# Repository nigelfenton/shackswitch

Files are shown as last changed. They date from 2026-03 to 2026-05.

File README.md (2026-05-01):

# G0JKN ShackSwitch

**Open source HF shack antenna switcher for amateur radio operators.**

**Builder:** Nigel Fenton, G0JKN (retired, UK)  
**Licence:** MIT  
**Current version:** v2.0 — Arduino Uno Q

---

## Photos

### Hardware

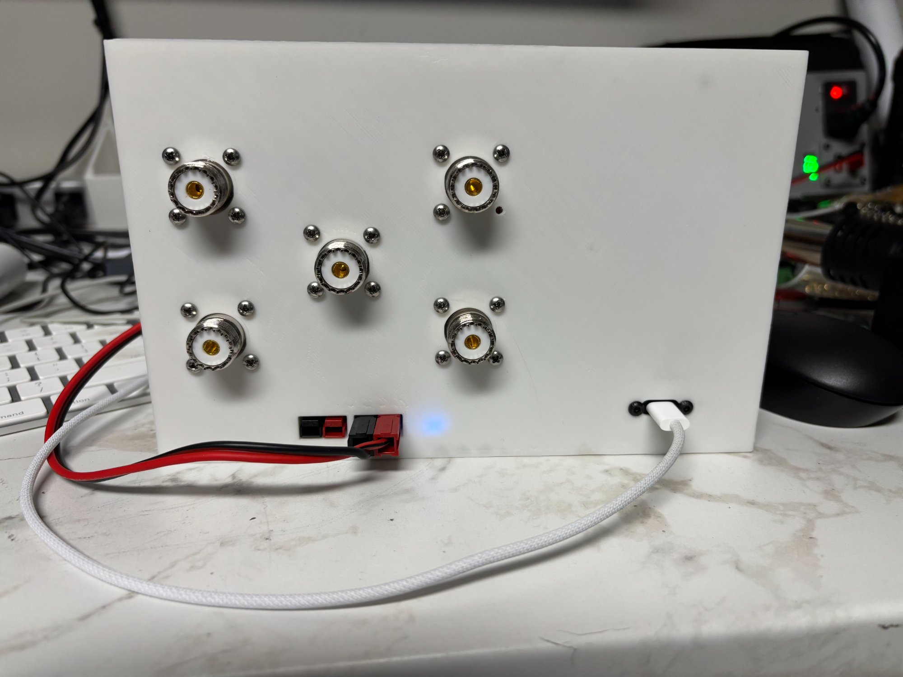
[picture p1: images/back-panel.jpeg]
ShackSwitch v2.0 — back panel


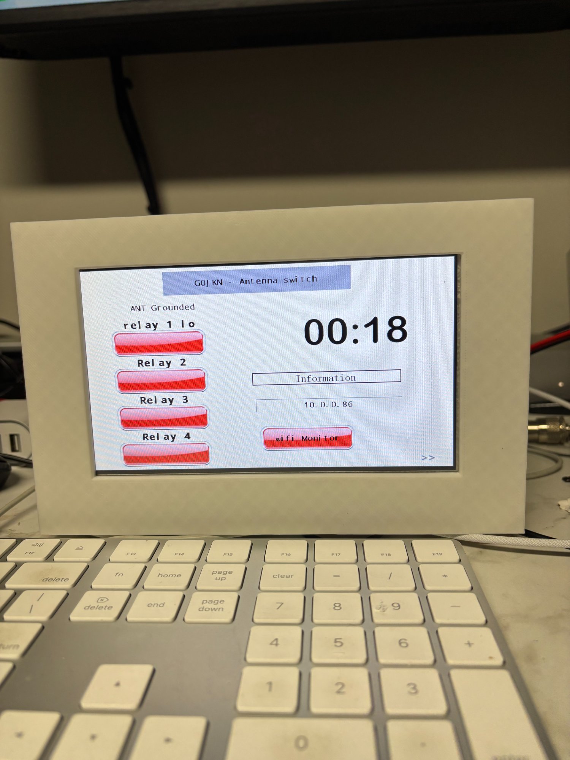
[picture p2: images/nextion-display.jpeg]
Nextion 7" display


### Web Interface

**Status page** — live frequency display per radio input, active antenna highlighted in the band grid, manual override buttons. Cyan = Input A, orange = Input B.

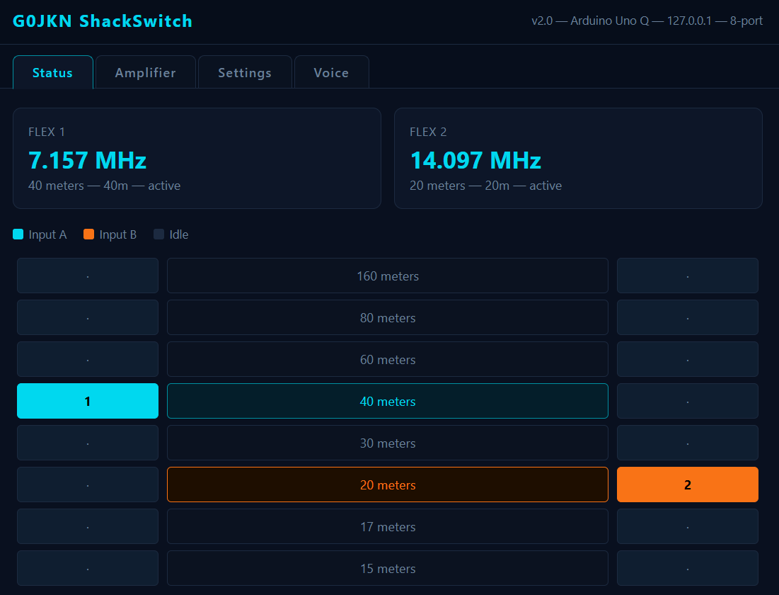
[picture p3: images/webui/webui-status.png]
Status page


**Amplifier page** — RF-Kit RF2K-S live telemetry: forward power, reflected power, SWR, temperature, supply voltage, current.

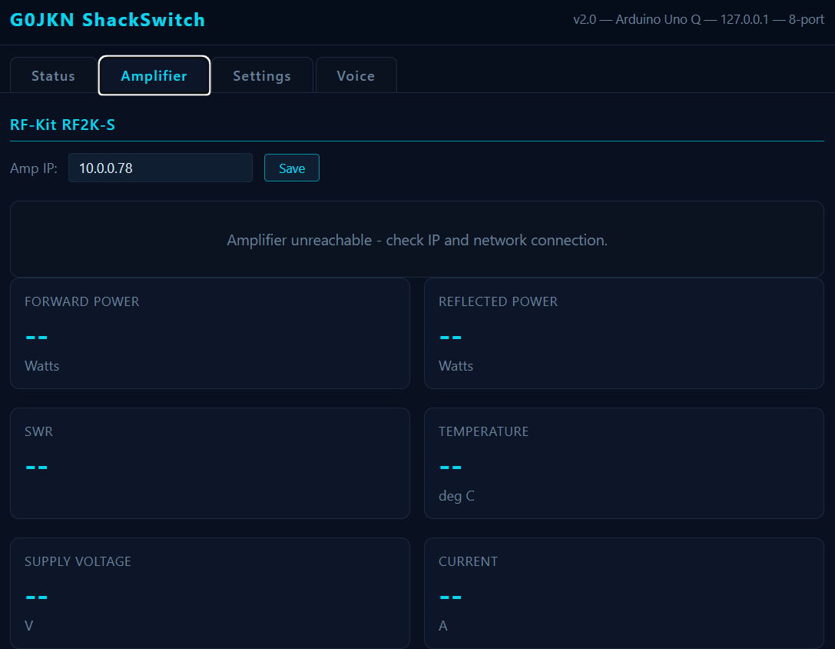
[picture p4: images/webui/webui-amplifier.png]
Amplifier page


**Settings → PORTS** — number of inputs (1 = single radio, 2 = SO2R), port count, input labels, and antenna port names. MCP23017 detection shown here with SO2R-ready status.

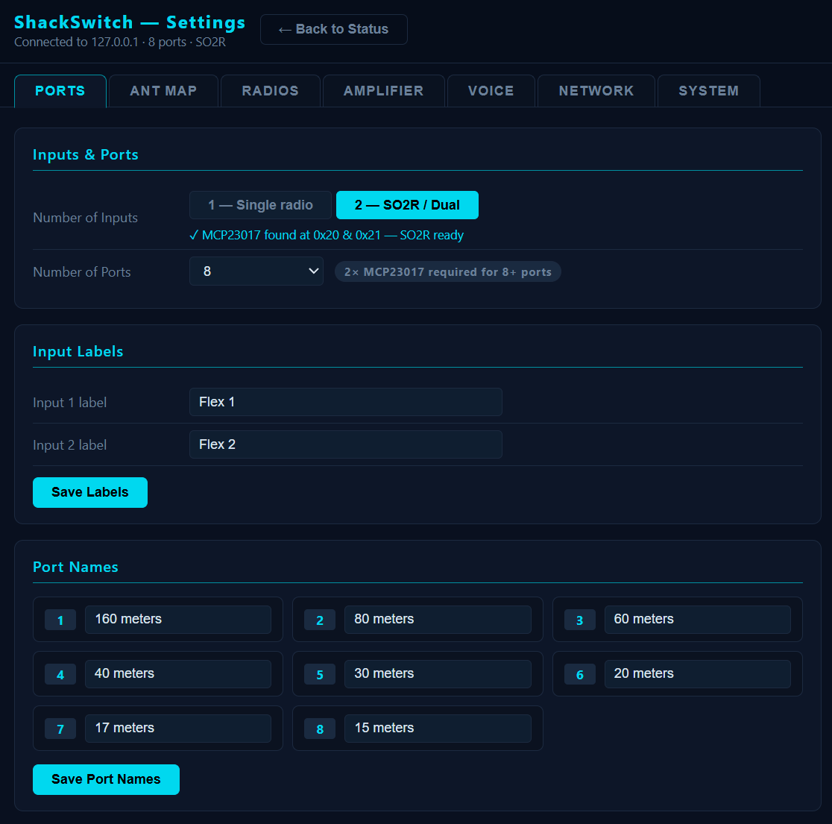
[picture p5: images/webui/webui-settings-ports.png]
Settings — PORTS


**Settings → ANT MAP** — band-to-port assignment grid. Click any cell to assign a band to a port; changes save instantly. The diagonal shows the example 8-antenna one-band-per-antenna setup.

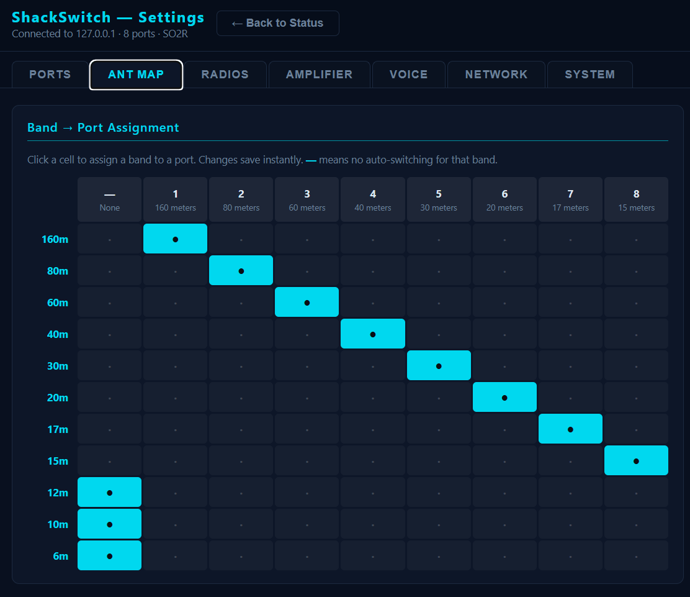
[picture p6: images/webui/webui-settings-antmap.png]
Settings — ANT MAP


**Settings → RADIOS** — CAT radio connections. Add, edit, or remove radios here. FlexRadio/SmartSDR is configured separately and always takes priority over CAT.

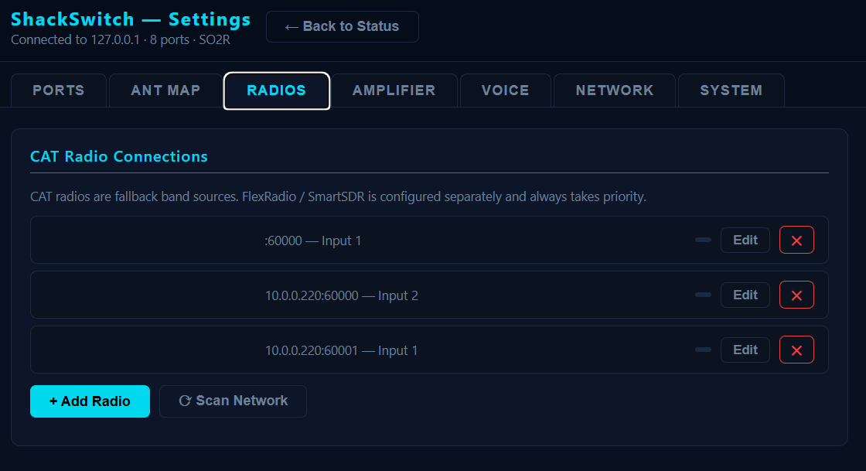
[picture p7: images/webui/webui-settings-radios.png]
Settings — RADIOS


**Settings → AMPLIFIER** — RF-Kit RF2K-S IP address and port configuration.

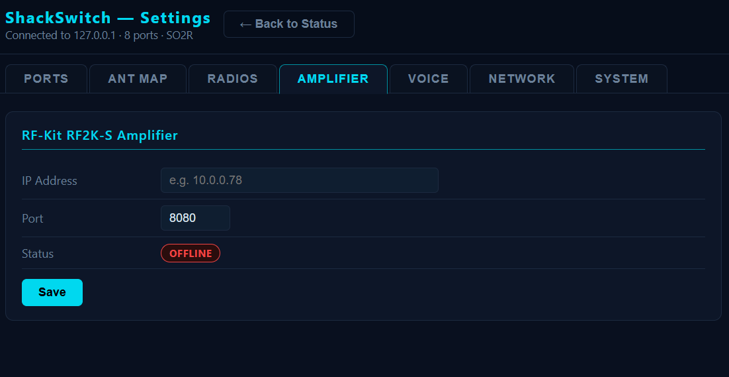
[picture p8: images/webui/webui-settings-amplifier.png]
Settings — AMPLIFIER


**Settings → VOICE** — links to ShackSpeak, the companion voice announcement app that monitors band changes and antenna selections.

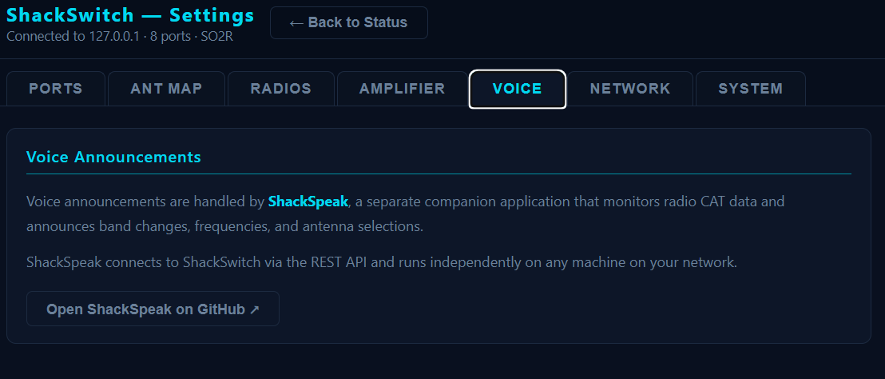
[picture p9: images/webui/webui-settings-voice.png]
Settings — VOICE


**Settings → NETWORK** — shows current WiFi connection and allows scanning for and joining a new network without SSH access.

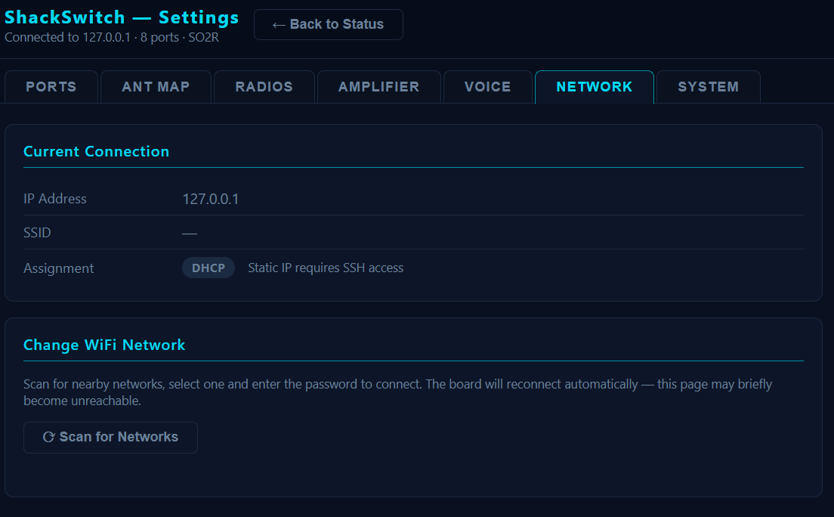
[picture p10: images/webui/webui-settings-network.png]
Settings — NETWORK


**Settings → SYSTEM** — station info (description, IARU region, ITU/CQ zone), board IP, app version and uptime, and factory reset.

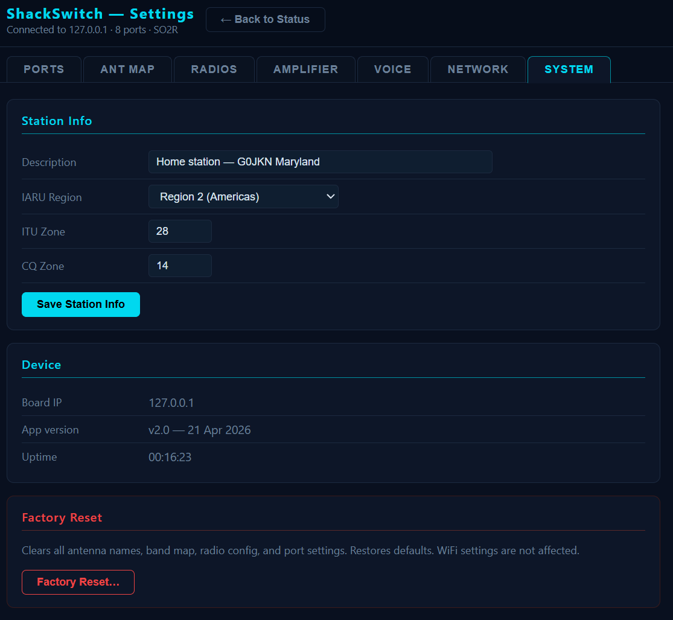
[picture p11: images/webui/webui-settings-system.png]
Settings — SYSTEM


### AetherSDR Integration

**Uno Q — dual input (SO2R), INPUT A on 20m, INPUT B on 80m:**

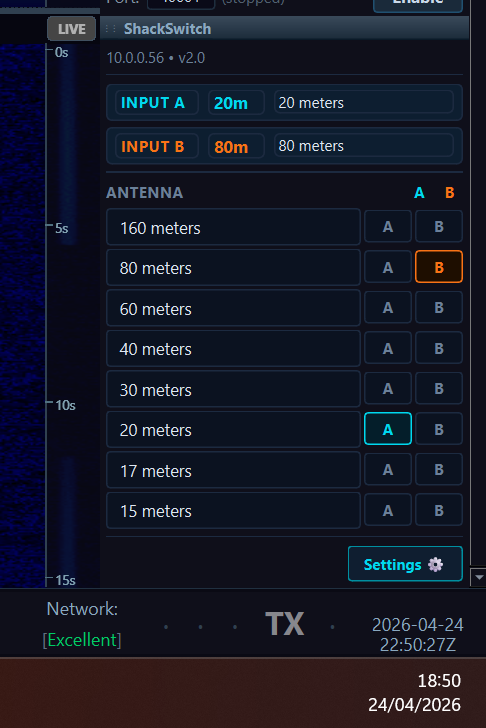
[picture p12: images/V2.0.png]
AetherSDR ShackSwitch applet — Uno Q dual input


**R4 — single input, INPUT A on 40m:**

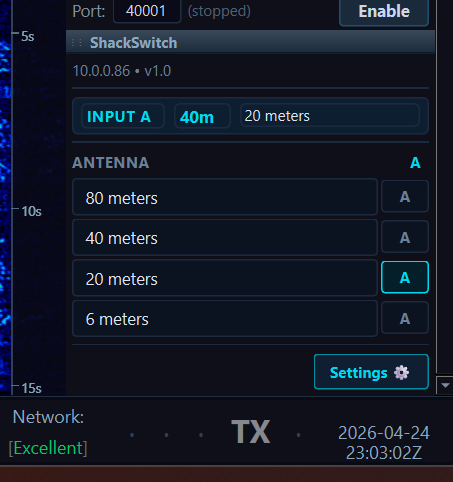
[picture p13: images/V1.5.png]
AetherSDR ShackSwitch applet — R4 single input


---

## What is ShackSwitch?

ShackSwitch sits between your radios and your antennas. It automatically selects the correct antenna when you change band, supports two radio inputs (SO2R capable) with hardware interlock protection, and can be controlled from any browser on your network.

It integrates with FlexRadio SmartSDR, Kenwood, Icom, and Yaesu radios — tracking band changes in real time and switching antennas automatically, with no manual intervention required.

---

## Platform — v2.0

ShackSwitch v2.0 runs on the **Arduino Uno Q** — a single board that combines a Qualcomm QRB2210 quad-core Linux processor with an STM32U585 real-time microcontroller.

- **Linux side** — Python Flask REST API, SmartSDR band tracker, radio CAT orchestrator, 4O3A Antenna Genius emulator. Runs as a Docker container, auto-started on boot.
- **STM32 side** — relay driver firmware. Loaded into RAM via OpenOCD at boot by `shackswitch-boot.sh`. Communicates with the Linux side via the Arduino Bridge RPC.
- **Web UI** — accessible from any browser on the network at `http://[board-ip]:5000/`

No separate Raspberry Pi or Arduino R4 is required.

---

## Features

### Antenna Switching
- Automatic antenna switching triggered by band changes from connected radios
- 2–16 configurable antenna ports (defaults to 8)
- Two radio input ports (SO2R) with hardware interlock — prevents both inputs selecting the same antenna simultaneously
- KK1L 2x6 relay board support via MCP23017 I2C GPIO expander (built and tested)
- G0JKN custom relay shield support (NPN/PNP driver, 12V coils)
- Band-to-antenna assignment grid — configurable per antenna per band

### Radio Interfaces
ShackSwitch tracks band changes from any combination of the following:

| Protocol | Supported Models |
|---|---|
| **FlexRadio SmartSDR** | FlexRadio 6000/7000 series via TCP port 4992 |
| **Kenwood CAT** | TS-450SAT, TS-480HX, TS-590, TS-890S, Elecraft K3/K4 |
| **Yaesu CAT** | FT-845, FT-891, FT-991A, FT-DX10, FT-817/818 |
| **Icom CI-V** | IC-9700, IC-7300, IC-705, IC-7610 |

Each radio runs in its own background thread with automatic reconnection. Serial and network transports are both supported.

### Web UI
- Live antenna selection display with manual switching
- Live frequency display per radio input
- SO2R interlock status
- Settings grid — port count, input labels, antenna names, band assignments
- Profile-based configuration — save and switch between different station setups
- Voice control — Web Speech API for TTS readback and voice commands

### Integration
- **4O3A Antenna Genius emulator** — ShackSwitch advertises itself as an Antenna Genius device over UDP/TCP (port 9007), making it discoverable and controllable by AetherSDR and other compatible software
- **REST API** — full HTTP endpoint set for external control and integration
- **Profile system** — multiple named configurations, switchable at runtime

---

## Hardware

| Item | Detail |
|---|---|
| Main board | Arduino Uno Q (Qualcomm QRB2210 Linux + STM32U585) |
| Relay shield | G0JKN custom shield — NPN/PNP drivers, 12V relay coils |
| Relay expander | KK1L 2x6 relay board with MCP23017 I2C GPIO expanders |
| RF connectors | SO239 — 1–2 radio inputs, up to 16 antenna outputs |
| Radio | FlexRadio 6700 (primary), Kenwood/Yaesu/Icom via CAT |
| Power | 12V DC |

---

## Wiring

### Nextion Display

Connect the Nextion to the Arduino Uno Q header pins as follows:

| Nextion pin | Uno Q pin |
|---|---|
| GND | GND |
| +5V | 5V |
| TX | **D0** (RX) |
| RX | **D1** (TX) |

> ⚠️ **Critical — use D0/D1, not D2/D3.**
> The Uno Q Zephyr OS maps serial ports as follows:
> - `Serial` → internal SoC↔STM32 link (`ttyHS1`) — **never use this for peripherals**
> - `Serial1` → D0/D1 header pins → **this is the Nextion connection**
>
> If you connect to D2/D3 the display will receive nothing. All sketch Nextion functions (`nextion_cmd`, `nextion_poll_serial`, etc.) call `Serial1`, which physically drives D0/D1.

📷 *Photo: close-up of D0/D1 jumper wires on the Uno Q header, with labels*

### MCP23017 I2C (KK1L Relay Board)

| MCP23017 pin | Uno Q pin |
|---|---|
| SDA | SDA (A4) |
| SCL | SCL (A5) |
| VCC | 3.3V (check board spec) |
| GND | GND |
| A0, A1, A2 | GND (I2C address 0x20) |

> If you have address conflicts on the I2C bus, tie A0/A1/A2 to different combinations of GND/VCC to select addresses 0x20–0x27.

📷 *Photo: MCP23017 / KK1L board wired to Uno Q SDA/SCL*

### USB-C Port Gotcha

The Uno Q has two USB-C ports. One is programming/console only; the other is the host USB port used for serial radio adapters. **If USB serial devices don't appear as `/dev/ttyUSB*`, try flipping the USB-C cable** — the host port is orientation-sensitive.

---

## How It Works

```
FlexRadio / Kenwood / Yaesu / Icom
         │ CAT / SmartSDR TCP
         ▼
┌─────────────────────────────────────────┐
│  Arduino Uno Q — Linux side             │
│                                         │
│  radios.py  ──► band change event       │
│                      │                  │
│  main.py (Flask) ◄───┘                  │
│  - REST API :5000                       │
│  - AG emulator :9007                    │
│  - Web UI                               │
│          │ Bridge RPC                   │
└──────────┼──────────────────────────────┘
           │
┌──────────▼──────────────────────────────┐
│  STM32U585 — real-time side             │
│  sketch.ino                             │
│  - Relay driver (direct GPIO)           │
│  - MCP23017 I2C (KK1L board)           │
│  - DIP switch config                    │
└─────────────────────────────────────────┘
           │
    Relay outputs ──► Antennas 1–16
```

### Boot Sequence

On power-up, `shackswitch-boot.sh` (run by systemd):
1. Restarts the `arduino-router` service and waits for its socket
2. Uses OpenOCD to load `sketch.ino.bin` into STM32 RAM
3. Waits for Bridge registration
4. Starts the ShackSwitch Docker container

### SO2R Interlock

When two radios are active:
- If both attempt to use the same antenna — Input B is inhibited
- If both are on the same band — Input B is inhibited
- Interlock state is shown live in the web UI and pushed to connected AetherSDR clients

---

## REST API

| Endpoint | Description |
|---|---|
| `GET /status` | Full status — relay states, bands, SO2R, interlock |
| `GET /radios/status` | CAT radio connection states and current bands |
| `GET /select?input=[a\|b]&port=[n]` | Select antenna port for input A or B |
| `GET /setband?input=[1\|2]&band=[name]` | Set band for input (e.g. `40m`) |
| `GET /bandmap` | Get band-to-antenna assignment map |
| `GET /assign` | Set band-to-antenna assignment |
| `GET /rename` | Rename an antenna port |
| `GET /rename_bulk` | Rename multiple ports in one call |
| `GET /profile` | Get current profile |
| `POST /profile` | Switch or save a profile |
| `GET /config/ports` | Get port count configuration |
| `POST /config/ports` | Set port count (2–16) |
| `GET /factory_reset` | Reset configuration to defaults |
| `GET /kk1l/status` | KK1L relay board status |
| `GET /kk1l/setband` | Drive KK1L board for a band change |

---

## 4O3A Antenna Genius Emulation

ShackSwitch emulates a 4O3A Antenna Genius device so that AetherSDR can discover and connect to it as a peripheral.

- **UDP discovery** — broadcasts on port 9007 every 5 seconds
- **TCP protocol** — implements `antenna list`, `band list`, `port get`, `sub port all`, `sub relay`, and `ping` commands
- Antenna count and band masks are derived from the active profile

See [shackswitch-v2/AETHERSDR-PROTOCOL.md](shackswitch-v2/AETHERSDR-PROTOCOL.md) for full protocol documentation.

> **Status (April 2026):** Full two-way integration is working — ShackSwitch is auto-discovered by AetherSDR, displays as a dedicated ShackSwitch applet showing live band and antenna selection for both inputs (R4: single input; Uno Q: dual input SO2R). Pull request [#2214](https://github.com/ten9876/AetherSDR/pull/2214) is open against the upstream AetherSDR repository; all CI checks passing.

---

## Radio CAT Configuration

Radios are configured in `config.json` under the `radios` key. Each radio entry specifies protocol, transport, and which ShackSwitch input it maps to.

```json
{
  "radios": {
    "a": {
      "label":     "IC-7300",
      "enabled":   true,
      "protocol":  "icom",
      "transport": "serial",
      "device":    "/dev/ttyUSB0",
      "baud":      9600,
      "civ_address": "0x94",
      "input":     "1"
    },
    "b": {
      "label":     "TS-890S",
      "enabled":   true,
      "protocol":  "kenwood",
      "transport": "network",
      "host":      "192.168.1.50",
      "port":      60000,
      "input":     "2"
    }
  }
}
```

FlexRadio SmartSDR is configured separately — `smartsdr.py` connects to the radio's TCP port 4992 and calls `/setband` on band changes.

---

## Repository Structure

```
shackswitch/
├── shackswitch-v2/          — current v2.0 source
│   ├── main.py              — Flask REST API, AG emulator, profile/config management
│   ├── radios.py            — multi-protocol radio CAT orchestrator
│   ├── radio_kenwood.py     — Kenwood CAT driver
│   ├── radio_yaesu.py       — Yaesu CAT driver
│   ├── radio_icom.py        — Icom CI-V driver
│   ├── radio_driver.py      — shared transport and band utilities
│   ├── smartsdr.py          — FlexRadio SmartSDR band tracker
│   ├── kenwood.py           — legacy standalone Kenwood interface (superseded by radios.py)
│   ├── sketch.ino           — STM32U585 relay firmware
│   ├── deploy.sh            — one-command deployment to any Uno Q board
│   ├── templates/           — Flask HTML templates (web UI pages)
│   ├── migrate_config.py    — config format upgrade tool
│   └── AETHERSDR-PROTOCOL.md — 4O3A Antenna Genius protocol documentation
├── services/
│   ├── shackswitch-boot.sh  — boot script: OpenOCD STM32 load + Docker start
│   └── shackswitch.service  — systemd service file
├── firmware/                — legacy Arduino R4 firmware (v1.5, historical)
├── nodered/                 — legacy Node-RED/Pi files (historical)
├── nextion/                 — legacy Nextion HMI files (historical)
└── docs/                    — legacy v1.5 README and project notes
```

---

## Version History

| Version | Platform | Key Changes |
|---|---|---|
| **2.0** | **Arduino Uno Q** | Complete rewrite — Flask REST API on Linux, STM32 relay firmware, Docker container, Bridge RPC, multi-protocol radio CAT (Kenwood/Yaesu/Icom/FlexRadio), KK1L board support, profile system, voice control, 4O3A AG emulation, 2–16 configurable ports |
| 1.5 | Arduino R4 WiFi + Raspberry Pi | TCP control protocol, UDP discovery, FlexRadio band tracking, SO2R interlock, Nextion band display |
| 1.4 | Arduino R4 WiFi | Antenna name labels, live JSON web updates |
| 1.3 | Arduino R4 WiFi | Dual-state image buttons on Nextion |
| 1.2 | Arduino R4 WiFi | NTP time sync, station monitor page, factory reset |
| 1.1 | Arduino R4 WiFi | WiFi web server, web-based antenna control, EEPROM name storage |
| 1.0 | Arduino R4 WiFi | Initial release — 4 relay antenna switching, Nextion display |

---

## Deploying to a New Board

A deploy script is included to get ShackSwitch running on a fresh Arduino Uno Q in one command.

### How the Board Becomes Reachable

The Arduino Uno Q runs Linux. Flask and the Docker container start automatically on every power-up — no USB connection is needed for the app to run.

What changes with USB is **network access**:

| State | What's running | Can you reach it? |
|---|---|---|
| Power only, no WiFi | Flask running on port 5000 | ❌ No — board has no network IP |
| Power + WiFi connected | Flask running on port 5000 | ✅ Yes — `http://[wifi-ip]:5000` from any device on your network |
| Power + USB (App Lab) | Flask running on port 5000 | ✅ Yes — USB network link gives the board a local IP even without WiFi |

When you plug in USB and launch App Lab, the Uno Q presents a **USB network interface** on your computer (Windows shows it as an RNDIS/USB Ethernet adapter). The board gets a USB link-local IP address — App Lab's web interface uses this to let you reach the board. The ShackSwitch web UI at port 5000 is accessible over that same USB link.

**This is the first-time WiFi setup path:**
1. Power up the board (no WiFi yet)
2. Plug in USB → launch App Lab on your computer
3. App Lab connects — board is now reachable over the USB network
4. Open `http://[usb-ip]:5000` in your browser (check App Lab for the board's USB IP address)
5. Go to **Settings → NETWORK** → scan for networks → select your SSID and enter the password → Connect
6. Board joins your WiFi and gets a permanent IP (shown on screen / in App Lab)
7. Unplug USB — from now on use `http://[wifi-ip]:5000` directly

> **Note:** `127.0.0.1` (localhost) refers to *your own computer*, not the board. You cannot use `http://127.0.0.1:5000` in a browser on your PC to reach the board — you need either the WiFi IP or the USB network IP.

---

### Prerequisites

- Arduino Uno Q plugged in via USB-C to your computer
- **App Lab first-run wizard** completed — connect the board to your WiFi network. App Lab displays the board's IP address at the end of setup. Note it down — that's what you pass to the deploy script. It also creates `user:first-app` which ShackSwitch deploys into.
- SSH key set up for the board (see Arduino Uno Q docs)
- This repo cloned to your machine

### Deploy

```bash
cd shackswitch-v2
./deploy.sh 10.0.0.XX    # use the IP shown by App Lab during setup
```

The script will:
1. Copy all Python files and templates to the board
2. Ensure `app.yaml` exposes both ports — **5000** (web UI) and **9007** (AG emulator)
3. Restart the app — flashes the STM32 sketch and starts the Python container

If your SSH key is not at one of the standard locations (`~/.ssh/id_ed25519`, `~/.ssh/id_rsa` etc.) you can override it:

```bash
SSH_KEY=~/.ssh/my_custom_key ./deploy.sh 10.0.0.XX
```

### After Deployment

1. Open `http://10.0.0.XX:5000` in a browser
2. Go to **Settings → PORTS** — name your antenna ports
3. Go to **Settings → ANT MAP** — assign bands to ports (click the grid cell to assign, saves instantly)
4. In **AetherSDR → Radio Setup → Peripherals**, set the ShackSwitch IP to your board IP

> **Note:** Each board starts with a fresh default config — antenna names and band assignments are set up via the web UI after deployment. WiFi and network settings are handled by the Uno Q OS, not ShackSwitch.

---

## udev Rules

To give serial radio adapters persistent device names on the Uno Q, create `/etc/udev/rules.d/99-shackswitch.rules`:

```
# Icom CI-V — Prolific USB-serial adapter
SUBSYSTEM=="tty", ATTRS{idVendor}=="067b", ATTRS{idProduct}=="2303", SYMLINK+="ttyICOM"

# Kenwood / Yaesu — FTDI USB-serial adapter
SUBSYSTEM=="tty", ATTRS{idVendor}=="0403", ATTRS{idProduct}=="6001", SYMLINK+="ttyKENWOOD"
```

Apply without rebooting:
```bash
sudo udevadm control --reload-rules && sudo udevadm trigger
```

Use the symlink in `config.json` (e.g. `"device": "/dev/ttyICOM"`) so the path survives USB re-plug events.

To find vendor/product IDs for an unknown adapter: `lsusb` or `udevadm info -a -n /dev/ttyUSB0 | grep -E "idVendor|idProduct"`.

---

## Key Configuration Settings

The main config file lives at `~first-app/app/config.json` on the board (or `/app/config.json` inside the running Docker container).

| Key | Default | Description |
|---|---|---|
| `ports` | `8` | Number of antenna ports (2–16) |
| `inputs` | `2` | Radio inputs — `1` = single, `2` = SO2R |
| `station.serial` | `"G0JKN-001"` | Station identifier used in AG beacon |
| `station.name` | `"ShackSwitch"` | Display name shown in AetherSDR |
| `smartsdr.host` | `""` | FlexRadio IP address (empty = disabled) |
| `smartsdr.port` | `4992` | SmartSDR TCP port |
| `kk1l.enabled` | `false` | Enable KK1L relay board via MCP23017 |
| `kk1l.i2c_address` | `"0x20"` | MCP23017 I2C address |
| `rf2ks.host` | `""` | RF2K-S amplifier IP (empty = disabled) |

> **AetherSDR identification:** `station.serial` must start with `G0JKN` **or** `station.name` must contain `ShackSwitch` (case-insensitive) for AetherSDR to show the dedicated ShackSwitch applet instead of a generic Antenna Genius panel.

📷 *Screenshot: Settings → SYSTEM page showing station serial and name fields*

---

## Nextion Display — Page Map

Navigation is driven entirely by Python (`nextion.py`). The HMI Touch Release events send `printh 23 02 54 NN` byte sequences (where `NN` is the button code); Python reads those events and issues numeric `page N` commands back to the display.

| Page | Name | Content |
|---|---|---|
| 0 | Splash | ShackSwitch logo, firmware version, **SKIP** button |
| 1 | Single (Main) | Input A band, active antenna, NEXT / PREV |
| 2 | SO2R | Input A and B side-by-side, antenna, interlock state |
| 3 | RSSI | Signal level bars (future) |
| 8 | WiFi | SSID, IP address, signal strength, **BACK** |

### Navigation flow

```
[Boot] → page 0 (splash, 20s auto-advance) → page 1
page 1 → NEXT → page 2 → NEXT → page 3 → NEXT → page 8
page 8 → BACK → page 0 (splash)
```

> **Serial port note:** The Nextion must be connected to D0/D1 (`Serial1` in the sketch). `Serial` is the internal SoC↔STM32 link and cannot be used for the display.

📷 *Photo: Nextion 7" display showing the SO2R page 2 with both inputs active*

---

## Troubleshooting

| Symptom | Likely Cause | Fix |
|---|---|---|
| Nextion stays on splash page | Wrong serial port in sketch | Confirm sketch uses `Serial1.begin(9600)` (D0/D1), not `Serial.begin()` |
| Display shows garbage | Baud mismatch | Both sketch and Nextion HMI must be set to 9600 baud |
| No relay clicks | STM32 sketch not loaded | Check boot script ran: `journalctl -u shackswitch.service` |
| Web UI not reachable at `:5000` | Container not running | `ssh first-app@[ip]` → `docker ps` |
| AetherSDR can't discover ShackSwitch | AG beacon not running | `ss -ulnp \| grep 9007` inside container — check port 9007 UDP |
| AetherSDR shows "Antenna Genius" label | Station name/serial mismatch | Ensure `station.serial` starts with `G0JKN` or `station.name` contains `ShackSwitch` |
| Serial radio not found (`/dev/ttyUSB*` missing) | USB-C orientation | Flip USB-C cable on Uno Q host USB port |
| Band changes not tracked | CAT radio disconnected | Check Settings → RADIOS; verify IP/port/device path; check radio is powered |
| SO2R interlock triggered unexpectedly | Both inputs on same band | This is correct behaviour — interlock clears when bands differ |
| Relay state lost on restart | Known issue — state not persisted | Roadmap item; workaround: re-select band from web UI after restart |

---

## Key File Locations (on the Board)

| File | Path on board | Purpose |
|---|---|---|
| Main config | `~first-app/app/config.json` | All station settings — ports, radios, profiles |
| Boot script | `/usr/local/bin/shackswitch-boot.sh` | Loads STM32 firmware, starts Docker container |
| systemd service | `/etc/systemd/system/shackswitch.service` | Runs boot script on power-up |
| STM32 firmware | `~first-app/app/sketch.ino.bin` | Relay driver binary, loaded into STM32 RAM by OpenOCD |
| Python app | `~first-app/app/*.py` | Flask REST API, radio drivers, AG emulator |
| Nextion module | `~first-app/app/nextion.py` | Nextion display driver and page navigation |
| Templates | `~first-app/app/templates/` | Web UI HTML pages |

📷 *Screenshot: SSH terminal showing `docker ps` output with the shackswitch container running*

---

## Licence

Released under the **MIT Licence**. Free to use, modify and distribute for personal or commercial purposes. Attribution to G0JKN appreciated but not required.

---

## About

Built by **G0JKN/W3** — a retired amateur radio operator keeping the mind sharp one solder joint at a time.

Feedback, suggestions and pull requests welcome.

*73 de G0JKN*

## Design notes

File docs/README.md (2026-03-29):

# G0JKN ShackSwitch
### Open Source Shack Controller for HF Stations





---

## Photos

Nextion Touchscreen Display
*Front panel — Nextion 3.5" touchscreen showing antenna ports, band display, SO2R status, NTP clock and IP address. 3D printed enclosure designed in Fusion 360.*

Back Panel
*Rear panel — five SO239 connectors (one radio input, four antenna outputs), 12V DC power connector with XT60, and USB port for programming. Blue power LED visible.*

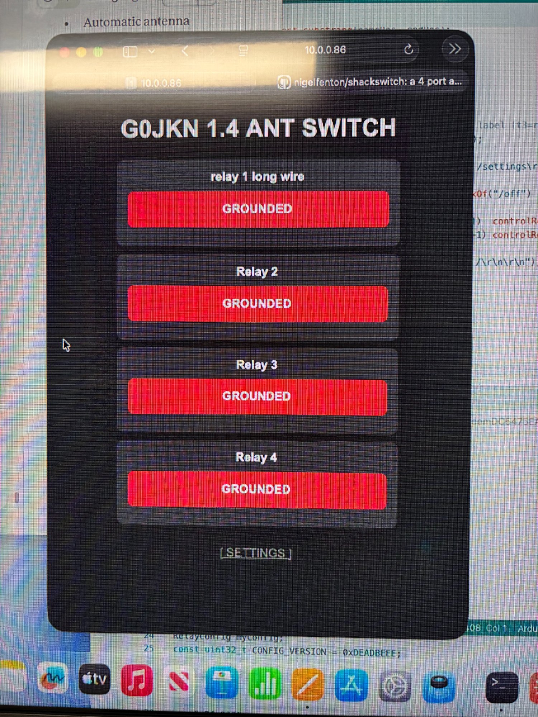
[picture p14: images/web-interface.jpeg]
Web Interface

*Web interface — four antenna ports with live band and SO2R status panel. Updates automatically every 5 seconds.*

---

## What Is This?

The G0JKN ShackSwitch is an open source shack controller designed and built by **G0JKN** as a hobby project. It started life as a simple 4-port antenna switcher and has grown into a full station management system covering antenna switching, SO2R interlock, automatic band tracking via FlexRadio SmartSDR, and network integration via a TCP control protocol and REST API.

If you are new to Arduino or amateur radio electronics, don't worry — this guide explains everything step by step. If you are an experienced builder, feel free to skip ahead to the sections most relevant to you.

---

## Features

- **4-port antenna switching** — select between up to 4 antennas with a single button press
- **Touchscreen control** — Nextion colour display with dual-state image buttons
- **Web interface** — control and monitor the switcher from any browser on your network, including mobile devices
- **Live web updates** — relay state, band display and SO2R status all update automatically every 5 seconds
- **Band display** — tBandA and tBandB show current band for Input 1 and Input 2 on the Nextion and web page
- **SO2R interlock** — inhibits second input if both are transmitting on the same band or same antenna
- **FlexRadio band tracking** — automatic antenna switching driven by SmartSDR frequency data via Raspberry Pi Python service
- **TCP control protocol** — port 9008, compatible with AetherSDR and Node-RED integration
- **UDP discovery beacon** — auto-discovery by network clients every 5 seconds
- **REST API** — full HTTP endpoint set including /setband for band updates
- **Antenna labels** — each port displays its assigned antenna name on the touchscreen and web page
- **WiFi connected** — built-in web server, NTP time sync, and network integration
- **LED Matrix display** — shows active relay or grounded state on the Arduino's onboard matrix
- **EEPROM storage** — antenna names and WiFi credentials survive power cycles
- **Factory reset** — double-tap safety reset accessible from the touchscreen

### Planned / Coming Soon
- KK1L 2x6 relay board expansion — upgrades to 2-input, 6-output matrix via MCP23017 I2C expanders
- Additional shack switching relays (amps, lights, PSU remote) via MCP23017
- BCD band decoder input and output
- PA protection / sequencer integration
- AetherSDR native integration panel (issue #179)

---

## Hardware Required

### Core Components

| Component | Details |
|---|---|
| Arduino Uno R4 WiFi | The brains of the system — includes onboard WiFi and LED matrix |
| Nextion NX4832T035 | 3.5 inch colour touchscreen display (or similar Nextion model) |
| 4x relay module | Single pole, for antenna switching (one relay per antenna port) |
| Custom Arduino shield | PCB or veroboard shield carrying relays, transistor drivers and connectors |
| 12V DC power supply | Powers relay coils via the shield |
| Buck converter | Steps 12V down to 5V for the Arduino and shield logic |
| Raspberry Pi (any model) | Required for SmartSDR band tracking (runs smartsdr.py service) |

### RF Connectors
- 1x SO239 input (from radio)
- 4x SO239 outputs (to antennas)

---

## How It Works

### The Basic Idea

The ShackSwitch sits between your radio and your antennas. Your radio connects to the single RF input, and each of your antennas connects to one of the four RF output ports. Pressing a button on the touchscreen (or clicking in the web interface) activates the corresponding relay, connecting that antenna to the radio and grounding all others.

```
Radio TX/RX
    │
    │  SO239 in
    ▼
┌─────────────────────┐
│  G0JKN ShackSwitch  │──── Relay 1 ──► SO239 ──► Antenna 1
│                     │──── Relay 2 ──► SO239 ──► Antenna 2
│  Arduino R4 WiFi    │──── Relay 3 ──► SO239 ──► Antenna 3
│  Nextion 3.5"       │──── Relay 4 ──► SO239 ──► Antenna 4
└─────────────────────┘
    │              ▲
    │  WiFi        │ HTTP /setband
    ▼              │
Web Browser    Raspberry Pi
               smartsdr.py
                   ▲
                   │ TCP port 4992
                   │
              FlexRadio SmartSDR
```

### Two Input Ports

The ShackSwitch is architecturally a two-input device, reflecting the KK1L 2x6 expansion board and the FlexRadio dual-slice model:

- **Input 1** = FlexRadio Slice A (TX capable)
- **Input 2** = FlexRadio Slice B

In a two-radio setup, Input 1 and Input 2 map to Radio A and Radio B respectively. The firmware tracks band and TX state for each input independently.

### Automatic Band Tracking

A Python service (`smartsdr.py`) runs on a Raspberry Pi on the same network. It connects to SmartSDR on TCP port 4992, subscribes to slice frequency events, and calls the ShackSwitch `/setband` REST endpoint whenever the band changes. The Nextion display and web page update automatically.

### SO2R Interlock

When both inputs are transmitting simultaneously, the firmware evaluates interlock conditions:
- **Same antenna conflict** — Input 2 inhibited
- **Same band conflict** — Input 2 inhibited

The Nextion tSO2R component shows **SO2R OK** (green) or **INHIBIT** (orange).

---

## Software Setup

### Arduino Firmware

**Libraries required** (install via Arduino IDE Library Manager):
- `EasyNextionLibrary` by Seithan
- `NTPClient` by Fabrice Weinberg
- WiFi, RTC, EEPROM, LED Matrix and ArduinoGraphics are included with the R4 board package

**Upload:**
1. Open `shackswitch.ino` and `triggers.ino` in the Arduino IDE — both must be in the same folder
2. Select **Tools → Board → Arduino Uno R4 WiFi**
3. Select the correct COM port
4. Click **Upload**

**Configure WiFi:**
Edit the `loadConfig()` function defaults before uploading, or use the touchscreen WiFi config page after upload.

**Important — boot order:**
Always apply 12V power before or simultaneously with USB. The Nextion runs from 12V — if the Arduino boots before 12V is connected, the boot-time display sync commands are lost.

### Nextion HMI

Copy the `.HMI` file to a FAT32 microSD card, insert into the Nextion, and power the display. It flashes automatically. Remove the card when complete.

### SmartSDR Band Tracker (Raspberry Pi)

The `smartsdr.py` script connects to your FlexRadio and calls `/setband` automatically on band changes.

**Install:**
```bash
# Copy the script
cp smartsdr.py ~/.node-red/smartsdr.py

# Edit the IP addresses at the top of the file
nano ~/.node-red/smartsdr.py
# FLEX_IP = "your.flex.ip.address"
# SHACKSWITCH_IP = "your.shackswitch.ip.address"

# Install as a systemd service
sudo cp smartsdr-tracker.service /etc/systemd/system/
sudo systemctl enable smartsdr-tracker.service
sudo systemctl start smartsdr-tracker.service
```

**Check it's running:**
```bash
sudo systemctl status smartsdr-tracker.service
```

---

## REST API

| Endpoint | Description |
|---|---|
| `GET /status` | Returns relay states, bandA, bandB and so2r as JSON |
| `GET /[n]/on` | Activate relay n (1–4), ground all others |
| `GET /[n]/off` | Ground relay n |
| `GET /rename?id=[n]&name=[name]` | Rename antenna port n, persist to EEPROM |
| `GET /setband?input=[1\|2]&band=[name]` | Set band for Input 1 or 2 (e.g. 40m) |
| `GET /settings` | Settings web page |

**Example /status response:**
```json
{"r1":0,"r2":1,"r3":0,"r4":0,"bandA":"40m","bandB":"20m","so2r":0}
```

**Example /setband response:**
```json
{"input":1,"band":"40m","bandId":4,"so2r":false}
```

---

## TCP Control Protocol (Port 9008)

The ShackSwitch listens for TCP connections on port 9008. Commands are prefixed `C[seq]|`, responses are prefixed `R[seq]|code|` or `S0|` for unsolicited events.

| Command | Description |
|---|---|
| `C1\|ping` | Keepalive check |
| `C1\|antenna list` | List all configured antennas |
| `C1\|band list` | List all bands with frequency ranges |
| `C1\|port get [n]` | Get full state of input port n |
| `C1\|port set [n] rxant=[n] band=[n]` | Set port parameters and drive relay |
| `C1\|interlock set radioA=[0\|1] band=[n]` | Update TX state and trigger interlock |

A UDP discovery beacon is broadcast every 5 seconds on port 9008:
```
SS name=ShackSwitch serial=SS-001 version=1.5.0 ip=[IP] port=9008 ant=4 radio=2
```

---

## Wiring

### Arduino to Nextion

| Arduino Pin | Nextion Pin |
|---|---|
| TX1 (Serial1) | RX |
| RX1 (Serial1) | TX |
| 5V | VCC |
| GND | GND |

### Arduino to Relay Shield

| Arduino Pin | Function |
|---|---|
| D2 | Relay 1 (Antenna 1) |
| D3 | Relay 2 (Antenna 2) |
| D4 | Relay 3 (Antenna 3) |
| D5 | Relay 4 (Antenna 4) |

### Power

| Connection | Details |
|---|---|
| 12V DC in | Powers relay coils directly |
| Buck converter | 12V in → 5V out → Arduino 5V pin and shield logic |

---

## Nextion HMI Components (Page 0)

| Component | Type | Purpose |
|---|---|---|
| b1 – b4 | Dual-state button | Antenna select (active/grounded image) |
| t3 – t6 | Text label | Antenna name above each button |
| tBandA | Text label | Current band for Input 1 / Slice A |
| tBandB | Text label | Current band for Input 2 / Slice B |
| tSO2R | Text label | SO2R OK (green) or INHIBIT (orange) |
| tState | Text label | ANT Active / ANT Grounded |
| tClock | Text label | Current time (NTP synced) |
| t1 | Text label | WiFi IP address |

---

## Troubleshooting

**Display shows "N O T C O N N E C T E D"**
Check SSID and password in the sketch, or use the touchscreen WiFi config page.

**tBandA / tBandB show "---" after boot**
Normal — no band data has been received yet. Start `smartsdr.py` on the Pi and change band in SmartSDR. The display updates within seconds.

**Nextion shows default antenna names after reflash**
Boot order issue — ensure 12V is applied before or with USB power so the Nextion is ready when the Arduino runs setup().

**Web page band panel not updating**
Check `/status` returns `bandA` and `bandB` fields. If they show `---`, the `smartsdr.py` service is not running — check with `sudo systemctl status smartsdr-tracker.service`.

**SmartSDR band tracker not connecting**
Confirm the FlexRadio IP address in `smartsdr.py`. Test TCP connectivity with `nc -zv [flex-ip] 4992`. Check SmartSDR is running with an active slice.

**Web page not updating after touchscreen button press**
The web page polls every 5 seconds. Wait a few seconds — it will update automatically.

---

## Repository Structure

```
shackswitch/
├── firmware/
│   ├── shackswitch.ino           — main sketch, web server, TCP protocol, relay control
│   └── triggers.ino              — Nextion touch event handlers
├── nodered/
│   ├── smartsdr.py               — SmartSDR band tracker (runs on Raspberry Pi)
│   └── smartsdr-tracker.service  — systemd service file for auto-start on boot
├── nextion/
│   └── shackswitch.HMI           — Nextion Editor project file
├── hardwear/
│   ├── shield-schematic.pdf      — Arduino shield schematic
│   └── BOM.csv                   — Bill of materials
├── docs/
│   └── project-brief.docx        — full project brief and architecture document
├── images/
└── README.md
```

---

## Version History

| Version | Changes |
|---|---|
| 1.0 | Initial release — basic 4 relay antenna switching, Nextion display |
| 1.1 | WiFi web server, web-based antenna control, EEPROM name storage |
| 1.2 | NTP time sync, station monitor page, factory reset, WiFi config page |
| 1.3 | Dual-state image buttons on Nextion |
| 1.4 | Antenna name labels, live JSON web updates, improved WiFi handling |
| 1.5 | TCP control protocol (port 9008), UDP discovery beacon, FlexRadio band tracking, SO2R interlock, /setband REST endpoint, Nextion band display, live web band panel, SmartSDR Python integration service |

---

## Licence

This project is released as open source under the **MIT Licence**. You are free to use, modify and distribute it for personal or commercial purposes. Attribution to G0JKN is appreciated but not required.

---

## About

Built by **G0JKN** — a retired amateur radio operator keeping the mind sharp one solder joint at a time. Designed in Fusion 360, coded in Arduino IDE, tested in a real HF shack with a FlexRadio 6700.

Feedback, suggestions and pull requests welcome. If you build one, please share a photo!

*73 de G0JKN* 📻

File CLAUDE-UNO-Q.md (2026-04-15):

# CLAUDE-UNO-Q.md — G0JKN ShackSwitch Project Context

This file gives Claude instant context for the ShackSwitch project.
Paste the raw URL of this file at the start of each session:
`https://raw.githubusercontent.com/nigelfenton/shackswitch/main/CLAUDE-UNO-Q.md`

---

## Project Identity

- **Project:** G0JKN ShackSwitch — open source HF shack antenna switcher
- **Builder:** Nigel Fenton, G0JKN (retired, UK)
- **GitHub:** https://github.com/nigelfenton/shackswitch
- **Licence:** MIT
- **Platform:** Arduino Uno Q (migrated from Arduino Uno R4 WiFi + Raspberry Pi 4)

---

## Current Version

**v2.0** — Arduino Uno Q

---

## CRITICAL — App Lab App Name

**The live App Lab app is `first-app` NOT `shackswitch`.**
The `shackswitch` App Lab app exists but is NOT the running app. Always work with `first-app`.

Live files on Uno Q:
- `first-app` Python: `/home/arduino/ArduinoApps/first-app/python/`
- `first-app` Sketch: `/home/arduino/ArduinoApps/first-app/sketch/`
- `first-app` Templates: `/home/arduino/ArduinoApps/first-app/python/templates/`
- **Config file (host):** `/home/arduino/ArduinoApps/first-app/python/config.json`
- **Config file (container):** `/app/python/config.json` — same file, volume mounted
- ⚠ `/home/arduino/shackswitch_config.json` is a SEPARATE file — NOT used by the running container

---

## Repo Structure

```
shackswitch/
├── CLAUDE-UNO-Q.md         — this file
├── README.md               — project overview
├── CHANGELOG.md            — version history
├── TEST-PLAN-v2.md         — v2.0 test plan (98 tests, 11 sections)
├── shackswitch-v2/         — current source files (reference copies from first-app)
│   ├── main.py             — Flask REST API + smartsdr/radios launcher + AG emulator
│   ├── kenwood.py          — Kenwood-only CAT (serial + network, legacy — still used)
│   ├── radios.py           — Multi-protocol CAT orchestrator (Kenwood/Yaesu/Icom)
│   ├── radio_driver.py     — Abstract RadioDriver base + Serial/Network transports
│   ├── radio_kenwood.py    — Kenwood IF; driver (TS-450/480/590/890, Elecraft K3/K4)
│   ├── radio_yaesu.py      — Yaesu IF; driver (FT-845/891/991A/DX10/817/818)
│   ├── radio_icom.py       — Icom CI-V binary driver (IC-9700/7300/705/7610/7100)
│   ├── smartsdr.py         — FlexRadio SmartSDR band/freq tracker
│   ├── rfkit.py            — RF-Kit RF2K-S amplifier integration
│   ├── migrate_config.py   — config migration tool (flat → profile-based)
│   ├── index.html          — web UI (Status, Amplifier, Settings, Voice pages)
│   ├── sketch.ino          — STM32 firmware (two MCP23017 boards)
│   ├── giga_dummy_890.ino  — Arduino Giga R1 dummy TS-890S (Kenwood CAT, port 60000)
│   ├── r4_dummy_890.ino    — Arduino Uno R4 dummy TS-890S
│   ├── AETHERSDR-PROTOCOL.md — AG protocol documentation
│   └── templates/          — Flask Jinja2 templates
│       ├── index.html      — main UI template (served by Flask)
│       ├── kenwood.html    — Kenwood CAT config/status page
│       └── ag_test.html    — Antenna Genius protocol test harness
├── services/               — systemd service files
│   ├── shackswitch.service
│   └── shackswitch-boot.sh
└── docs/                   — legacy documentation
```

---

## Hardware

### Built and Verified

| Item | Detail |
|---|---|
| Microcontroller | Arduino Uno Q (QRB2210 Linux + STM32U585 MCU) |
| Relay shield | G0JKN custom design, NPN/PNP driver, D2-D5, 12V coils |
| RF connectors | 4x SO239 active (expandable to 16 with dual KK1L boards) |
| Power | 12V DC → relay coils, 5V via Uno Q USB-C |
| Network | WiFi 5 dual band, IP 10.0.0.145 |
| MCP23017 #1 | Address 0x20 — RLYT relay drivers on Port A (Input A routing) |
| MCP23017 #2 | Address 0x22 (A1 bridged to VCC) — RLYB relay drivers on Port A (Input B routing) |
| DIP switches | D6–D9, active LOW with INPUT_PULLUP — 4 bits = values 0–15, read via `get_config` RPC |

### MCP23017 Critical Notes

- **Only Port A (GPA0–GPA7) has relay drivers** — Port B has NO drivers and cannot drive relays
- 1 MCP23017 = **8 usable driven outputs** (Port A only)
- Ports 1–8 → MCP board 1 (0x20) | Ports 9–16 → MCP board 2 (0x22)
- A0 pad pulled LOW by default solder bridge — use A1 or A2 for address setting, NOT A0
- Board 2 address 0x22: A1 bridged to VCC, A0 and A2 open
- ⚠ sketch.ino shows 0x21 for board 2 — **hardware confirmed as 0x22** — sketch needs correcting

---

## Architecture

```
FlexRadio 6700 (10.0.0.250)
│  TCP port 4992
▼
smartsdr.py (Uno Q Linux — Docker container)
  subscribes via sub slice all after 1-second delay
  maps RF_frequency (or frequency) → band name
  calls /kk1l/setband on band change (slice 0 → input 1, slice 1 → input 2)
  reconnects automatically if TCP drops
│
radios.py (parallel thread — multi-protocol CAT)
  polls configured radios via Kenwood/Yaesu/Icom drivers
  calls /kk1l/setband on band change per input assignment
  last_band persists across reconnects (module-level _last_band dict)
│
kenwood.py (parallel thread — legacy Kenwood CAT, still in use)
  serial CAT (TS-480HX etc) and network CAT (TS-890S port 60000)
  same last_band persistence fix applied
│  HTTP GET localhost:5000
▼
Flask REST API (Uno Q Linux — Docker container, port 5000)
  reads/writes /app/python/config.json
│  Bridge RPC (arduino-router.sock)
▼
STM32 firmware (Uno Q MCU — Zephyr OS)
  relay_on/off → D2-D5 (relay shield)
  kk1l_select_a → MCP1 GPA (RLYT, 0x20)
  kk1l_select_b → MCP2 GPA (RLYB, 0x22)
│  GPIO D2-D5 + I2C Wire1 → MCP23017 x2
▼
Relay shield (D2-D5) + KK1L matrix (MCP1 at 0x20, MCP2 at 0x22)
└── SO239 antenna ports 1–16 (8 per MCP board)
```

---

## Radio CAT System

### Two parallel systems (both run at startup)

| System | File | Purpose |
|---|---|---|
| SmartSDR | `smartsdr.py` | FlexRadio 6700 only — subscribes to SmartSDR API on port 4992 |
| Legacy Kenwood | `kenwood.py` | Serial + network Kenwood CAT (TS-480HX, TS-890S etc.) |
| Multi-protocol | `radios.py` | Kenwood + Yaesu + Icom over serial or network — uses radio_*.py drivers |

### Multi-protocol drivers (radio_*.py)

| Driver | File | Covers |
|---|---|---|
| Kenwood | `radio_kenwood.py` | TS-450/480/590/890, Elecraft K3/K4 — ASCII IF; command |
| Yaesu | `radio_yaesu.py` | FT-845/891/991A/DX10/817/818 — ASCII IF; (mode field at pos 21 not 29) |
| Icom CI-V | `radio_icom.py` | IC-9700/7300/705/7610/7100 — binary CI-V, serial only; VHF/UHF bands included for IC-9700 |

### Config key for multi-protocol radios: `"radios"` (NOT `"kenwood"`)

```json
"radios": {
  "a": {
    "label": "IC-9700", "enabled": true, "protocol": "icom",
    "transport": "serial", "device": "/dev/ttyUSB0", "baud": 9600,
    "civ_address": "0x98", "input": "1"
  },
  "b": {
    "label": "TS-890S", "enabled": true, "protocol": "kenwood",
    "transport": "network", "host": "10.0.0.220", "port": 60000, "input": "2"
  }
}
```

### Critical: input source conflicts

If two systems are both assigned to the same input (e.g. SmartSDR slice 1 AND Kenwood radio B both on input 2), they will fight and override each other. The `/radios/status` endpoint detects and reports conflicts. The Settings → Radio Sources page shows a warning banner.

**Kenwood radio B default:** disabled in config (`"enabled": false`) — enable only when a Kenwood/TS-890S is actually connected.

### last_band bug fix (15 Apr 2026)

Both `kenwood.py` and `radios.py` had `last_band` as a local variable that reset to `None` on every reconnect, causing `setband` to fire on each reconnect even if the band hadn't changed. Fixed in both files by using a module-level `_last_band` dict keyed by radio ID.

### Test hardware

| Hardware | Sketch | Role |
|---|---|---|
| Arduino Giga R1 WiFi | `giga_dummy_890.ino` | Dummy TS-890S: touchscreen band buttons, CAT port 60000, web fallback port 80. IP 10.0.0.220 |
| TS-450 | — | Available for serial CAT testing as stand-in for TS-480HX (same Kenwood IF protocol) |

---

## Config File Structure

**Host path:** `/home/arduino/ArduinoApps/first-app/python/config.json`
**Container path:** `/app/python/config.json` (same file, volume mounted)

### Top-level keys

```json
{
  "active_profile": "home",
  "profiles": { "home": { ... } },
  "input1_relay": null,
  "input2_relay": null,
  "input1_port": null,
  "input2_port": null,
  "input1_label": "Flex 6700 A",
  "input2_label": "Flex 6700 B",
  "rfkit_ip": "10.0.0.78",
  "rfkit_enabled": false,
  "kenwood": {
    "a": { "enabled": false, "label": "TS-480HX", "type": "serial", "device": "/dev/ttyUSB0", "baud": 9600, "input": "1", "host": "", "port": 60000 },
    "b": { "enabled": false, "label": "TS-890S",  "type": "network", "host": "", "port": 60000, "input": "2", "device": "/dev/ttyUSB0", "baud": 9600 }
  },
  "radios": {}
}
```

### Profile structure (inside `"profiles"."home"`)

```json
{
  "description": "Home station",
  "iaru_region": 1, "itu_zone": 28, "cq_zone": 14,
  "port_count": 8,
  "antennas": {
    "1": { "name": "Trapped Vertical", "enabled": true,
           "rx_bands": ["160m","80m","40m","20m","15m","10m"],
           "tx_bands": ["40m","20m","15m","10m"], "tx_atu_bands": ["160m","80m"] }
  },
  "band_map": { "20m": 4, "40m": 3, "6m": 7, ... }
}
```

---

## REST API Endpoints (Flask, port 5000)

### Core

| Endpoint | Description |
|---|---|
| `GET /` | Main web UI |
| `GET /status` | Full status — relays, KK1L, band/freq, port_count, active_profile |
| `GET /kk1l/select?input=[1\|2]&port=[n]` | Select KK1L port with interlock |
| `GET /kk1l/deselect_all` | Deselect all KK1L ports |
| `GET /kk1l/setband?input=[1\|2]&band=[name]` | **Auto-switch KK1L by band — use this** |
| `GET /kk1l/status` | KK1L port states + antenna names |
| `GET /bandmap` | band_map + antennas + port_count from active profile |
| `GET /assign?band=[name]&port=[n]` | Assign band to port |
| `GET /assign/clear?band=[name]` | Clear band assignment |
| `GET /rename?id=[n]&name=[name]` | Rename antenna port |
| `POST /rename/bulk` | Rename multiple ports (JSON body) |
| `GET /label?input=[1\|2]&name=[name]` | Set input label |
| `POST /config/ports` | Set port_count 2–16 |
| `POST /antenna/capability` | Update rx/tx/tx_atu_bands and enabled for one port |
| `GET /profile` | Active profile info + available profiles list |
| `GET /profile/set?name=[name]` | Switch active profile |
| `GET /factory_reset` | Reset to 16-port profile defaults |
| `GET /device/config` | Read DIP switch value (0–15) from STM32 |
| `GET /radio/status` | Live FlexRadio slice state |

### Radio CAT (radios.py)

| Endpoint | Description |
|---|---|
| `GET /radios/status` | Combined status: SmartSDR slices + all CAT radios. Includes conflict detection. |
| `GET /radios/scan` | Scan local /24 subnet for radios on ports 4992/60000/50001. Returns list of found services. |
| `GET /radios/config` | Read `config.radios` dict |
| `POST /radios/config` | Write full `config.radios` dict (409 if input conflicts) |
| `PUT /radios/config/<id>` | Add or update a single radio entry |
| `DELETE /radios/config/<id>` | Remove a radio entry |

### Kenwood CAT (legacy)

| Endpoint | Description |
|---|---|
| `GET /kenwood` | Kenwood config/status page |
| `GET /kenwood/status` | JSON state of both radios (a, b) |
| `GET /kenwood/config` | Read kenwood config |
| `POST /kenwood/config` | Write kenwood config for radio a or b |
| `POST /kenwood/test` | Force band change for testing (no radio needed) |

### RF-Kit & Emulators

| Endpoint | Description |
|---|---|
| `GET /rfkit/status` | RF2K-S status |
| `GET /rfkit/config` | Read rfkit_ip and rfkit_enabled |
| `POST /rfkit/config` | Save rfkit_ip and rfkit_enabled |
| `PUT /rfkit/operate` | Set OPERATE or STANDBY |
| `POST /rfkit/fault/reset` | Clear RF2K-S fault |
| `GET /ag-test` | AG protocol test harness page |
| `GET /ag-test/state` | Live AG emulator state JSON |

---

## Web UI

Single page app served by Flask at `http://10.0.0.145:5000/`

**Nav pages:** Status · Amplifier · Settings · Voice · AG Test · Kenwood

**Status page:** Two VFO cards (live freq per input), 3-column antenna matrix, interlock flash, 5s auto-refresh.

**Amplifier page:** RF2K-S metrics, operate mode, fault, IP config.

**Settings page (scroll order):**
1. Hardware Port Count — spinner 2–16, >8 triggers MCP warning
2. Antenna Names — individual and bulk
3. **Radio Sources** — Input 1/2 assignment slots, CAT radio pool (enable/disable/edit/delete), Scan Network button (scans /24 for Flex/Kenwood/Icom), conflict warning banner
4. Input Labels — label for Input A and Input B
5. Band → Antenna Assignment — pigeonhole grid

**Voice page:** TTS + STT (Web Speech API), TTS voice/rate/pitch/volume settings, custom commands.

**Kenwood page:** `/kenwood` — radio A/B config, live status, test band change.

**AG Test page:** `/ag-test` — live Antenna Genius emulator state.

---

## App Lab Setup

- **Tool:** Arduino App Lab 0.6.0
- **Board:** Arduino Uno Q at 10.0.0.145
- **Live app name:** `first-app`
- **Docker container:** `first-app-main-1`
- **Start app (full — reflashes sketch):** `arduino-app-cli app start user:first-app`
- **Stop app:** `arduino-app-cli app stop user:first-app`
- **Restart container only (no reflash):** `docker restart first-app-main-1`
  - ⚠ `docker restart` does NOT re-sync the Bridge RPC — use `arduino-app-cli` for full restart
- **View logs:** `docker logs first-app-main-1 -f --tail 50`
- **Ports exposed:** 5000 (Flask), 9007 (AG emulator TCP)

---

## SSH Access

SSH key installed for passwordless access from this Windows machine:
- **Key:** `~/.ssh/id_ed25519_claude` (on Windows: `C:\Users\nigel\.ssh\id_ed25519_claude`)
- **Connect:** `ssh -i ~/.ssh/id_ed25519_claude arduino@10.0.0.145`
- **SCP:** `scp -i ~/.ssh/id_ed25519_claude <file> arduino@10.0.0.145:/home/arduino/ArduinoApps/first-app/python/`
- Key installed 15 Apr 2026 — one-time password entry via CMD

### Quick deploy (all python files)

```bash
SCP="scp -i ~/.ssh/id_ed25519_claude"
DEST=arduino@10.0.0.145:/home/arduino/ArduinoApps/first-app/python
$SCP main.py kenwood.py radios.py radio_driver.py radio_icom.py radio_kenwood.py radio_yaesu.py smartsdr.py $DEST/
$SCP index.html $DEST/templates/index.html
```

### After deploy — restart

```bash
ssh -i ~/.ssh/id_ed25519_claude arduino@10.0.0.145 "arduino-app-cli app stop user:first-app && arduino-app-cli app start user:first-app"
```

---

## Known Constraints and Gotchas

| Issue | Detail |
|---|---|
| Live app is `first-app` | NOT `shackswitch` — always edit first-app files |
| Config path | Container reads `/app/python/config.json` = host `first-app/python/config.json` |
| `docker restart` vs `app start` | `docker restart` only restarts Python container — Bridge RPC to STM32 may time out. Use `arduino-app-cli app start` for a reliable full restart |
| `Serial1` reserved | Used by arduino-router — do not use in sketch |
| `Bridge.update_safe()` private | Use `Bridge.update()` instead |
| I2C uses Wire1 not Wire | Uno Q headers use Wire1 for SDA/SCL |
| MCP23017 Port A only | Only Port A has relay drivers |
| MCP23017 A0 pulled LOW | Use A1 or A2 for address setting |
| sketch.ino MCP address stale | Shows 0x21 for board 2 — hardware is 0x22 |
| Relay state lost on restart | Startup sync from config not yet implemented |
| /setband vs /kk1l/setband | When kk1l_available always use /kk1l/setband |
| Input source conflict | If SmartSDR and a CAT radio are both assigned to the same input they fight — check /radios/status |
| Kenwood radio B default | Keep `enabled: false` unless a Kenwood radio is physically connected to that IP/port |
| App Lab serial monitor | Unreliable — use Arduino IDE 2.x instead |
| **BSOD — Chrome mic on Win11** | DAX IQ driver + Chrome mic icon = BSOD. Use `chrome://settings/content/microphone` only |

---

## Autostart Status

**SOLVED (6 Apr 2026).** Systemd service reflashes sketch via OpenOCD and starts Docker on power cycle.

- Service: `/etc/systemd/system/shackswitch.service`
- Script: `/home/arduino/shackswitch-boot.sh`
- Sketch binary: `/home/arduino/shackswitch-flash/sketch.ino.bin-zsk.bin`

---

## Antenna Genius (AG) Emulator

ShackSwitch emulates a 4O3A Antenna Genius so AetherSDR can discover and control it.
Protocol documented in `shackswitch-v2/AETHERSDR-PROTOCOL.md`.

- **UDP broadcast:** port 9007, every 5s
- **TCP server:** port 9007 — full AG command/response protocol
- **Status:** connection and protocol fully working as of 9 Apr 2026
- **AetherSDR UI:** antenna panel not yet implemented in AetherSDR — protocol groundwork complete
- **AetherSDR audio:** active bugs in v0.8.15/15.1 (Apr 2026) — monitor for fix

---

## RF-Kit RF2K-S Amplifier Integration

- **Model:** RF-Kit B26-PA RF2K-S — 1500W LDMOS, 160–6m
- **Network:** IP 10.0.0.78, API port 8080 (REST/JSON, no auth)
- `rfkit.py` module live, Amplifier page live
- PA sequencing in `/kk1l/setband`: **not yet implemented**

---

## Known Bugs

| Issue | Detail |
|---|---|
| Relay state not restored on restart | setup() needs to read config and call relay_on at startup |
| sketch.ino MCP address stale | Board 2 shows 0x21 — fix to 0x22 before next sketch deploy |
| PA sequencing not wired in | /kk1l/setband does not yet trigger RF2K-S standby→switch→operate |

---

## Roadmap

| Priority | Item |
|---|---|
| ~~Done~~ | Voice TTS + STT Phase 1+2 — 6 Apr 2026 |
| ~~Done~~ | Live FlexRadio VFO display — 6 Apr 2026 |
| ~~Done~~ | Cold boot autostart via systemd — 6 Apr 2026 |
| ~~Done~~ | Profile-based config — 7 Apr 2026 |
| ~~Done~~ | AG emulator — UDP broadcast + TCP server on port 9007 — 9 Apr 2026 |
| ~~Done~~ | KK1L board built and all relays tested — 9 Apr 2026 |
| ~~Done~~ | TTS voice settings page (voice/rate/pitch/volume) — 14 Apr 2026 |
| ~~Done~~ | Multi-protocol CAT (Kenwood/Yaesu/Icom) — radio_driver/icom/kenwood/yaesu/radios.py — 14 Apr 2026 |
| ~~Done~~ | Radio Sources settings page with network scan + conflict detection — 15 Apr 2026 |
| ~~Done~~ | SSH key auth for passwordless deploy — 15 Apr 2026 |
| ~~Done~~ | last_band reconnect bug fixed in kenwood.py and radios.py — 15 Apr 2026 |
| **Immediate** | Connect KK1L board to MCP23017 driver board (hardware) |
| **Immediate** | Restore relay state on container restart |
| **Immediate** | Fix sketch.ino MCP board 2 address (0x21 → 0x22) |
| **Immediate** | Test Kenwood CAT — Giga dummy (Radio B) then TS-450 serial (Radio A) |
| Near term | Wire RF2K-S PA sequencing into kk1l_setband |
| Near term | USB device passthrough in app.yaml for serial radio (`devices: [/dev/ttyUSB0]`) |
| Near term | Multi-port band_map (SO2R — 2 antennas per band) |
| Near term | Settings page: 2D antenna capability matrix |
| Near term | Profile switcher in UI |
| Future | Visual Radio Controls page (SVG, voice-controllable) |
| Future | MCP23017 #3 for shack switching |
| Future | AetherSDR antenna panel (awaiting their UI implementation) |

---

## Session Log

| Date | Achievement |
|---|---|
| 30 Mar 2026 | Full migration from R4+Pi to Uno Q |
| 30 Mar 2026 | Flask REST API, Bridge RPC, all 4 relays working |
| 30 Mar 2026 | smartsdr.py ported, automatic band switching working |
| 30 Mar 2026 | SO2R interlock working |
| 30 Mar 2026 | Config persistence via host volume mount |
| 30 Mar 2026 | Systemd service for container autostart |
| 31 Mar 2026 | Web UI — dark theme, matrix, status cards, settings, pigeonhole |
| 31 Mar 2026 | KK1L and MCP23017 support added to STM32 sketch |
| 02 Apr 2026 | Wire1 fix, MCP23017 confirmed, KK1L switching working |
| 03 Apr 2026 | RF2K-S integration — rfkit.py, /rfkit/* endpoints, Amplifier page |
| 04 Apr 2026 | Full repo sync to GitHub |
| 04 Apr 2026 | smartsdr.py band-switching bugs fixed — end-to-end confirmed |
| 04 Apr 2026 | MCP23017 #2 at 0x22 added — dual-board confirmed |
| 05 Apr 2026 | Voice TTS Phase 1 + STT Phase 2 live |
| 05 Apr 2026 | Voice Settings page, custom commands, debounce, BSOD root cause |
| 06 Apr 2026 | Cold boot autostart confirmed via systemd |
| 06 Apr 2026 | Live VFO frequency display, multi-slice SO2R confirmed |
| 07 Apr 2026 | Antenna Genius API researched (TCP 9007, pipe-delimited) |
| 07 Apr 2026 | Profile-based config designed and deployed |
| 07 Apr 2026 | Antenna capability model (rx/tx/tx_atu per band per port) |
| 07 Apr 2026 | 16-port scaffold — dual KK1L board ready in config |
| 09 Apr 2026 | AG emulator built — UDP broadcaster + TCP server, AetherSDR confirmed working |
| 09 Apr 2026 | KK1L board built and tested — all relays confirmed |
| 11 Apr 2026 | MCP23017 board 2 address confirmed in hardware; Kenwood CAT architecture designed |
| 14 Apr 2026 | TTS voice settings added to Voice page (voice/rate/pitch/volume + onvoiceschanged fix) |
| 14 Apr 2026 | Multi-protocol radio drivers added: radio_driver.py, radio_icom.py, radio_kenwood.py, radio_yaesu.py, radios.py |
| 14 Apr 2026 | TEST-PLAN-v2.md added, README updated |
| 15 Apr 2026 | SSH key auth set up (id_ed25519_claude → arduino@10.0.0.145) |
| 15 Apr 2026 | All new files deployed from GitHub clone to live first-app |
| 15 Apr 2026 | kenwood.py last_band reconnect bug fixed — module-level _last_band dict |
| 15 Apr 2026 | radios.py same fix applied |
| 15 Apr 2026 | Radio Sources settings page — Input 1/2 slots, CAT pool, Scan Network, conflict detection |
| 15 Apr 2026 | /radios/status, /radios/scan, /radios/config CRUD endpoints added |
| 15 Apr 2026 | Settings page section order rationalised: Radio Sources → Input Labels → Band Map |
| 15 Apr 2026 | Jackson Structured Chart produced (docx, 4 pages, full system decomposition) |

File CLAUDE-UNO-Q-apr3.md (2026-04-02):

# CLAUDE-UNO-Q.md — G0JKN ShackSwitch Project Context

This file gives Claude instant context for the ShackSwitch project.
Paste the raw URL of this file at the start of each session:
`https://raw.githubusercontent.com/nigelfenton/shackswitch/main/CLAUDE-UNO-Q.md`

---

## Project Identity

- **Project:** G0JKN ShackSwitch — open source HF shack antenna switcher
- **Builder:** Nigel Fenton, G0JKN (retired, UK)
- **GitHub:** https://github.com/nigelfenton/shackswitch
- **Licence:** MIT
- **Platform:** Arduino Uno Q (migrated from Arduino Uno R4 WiFi + Raspberry Pi 4)

---

## Current Version

**v2.0** — Arduino Uno Q

---

## CRITICAL — App Lab App Name

**The live App Lab app is `first-app` NOT `shackswitch`.**

The `shackswitch` App Lab app exists but is NOT the running app. Always work with `first-app`.

Live files on Uno Q:
- `first-app` Python: `/home/arduino/ArduinoApps/first-app/python/`
- `first-app` Sketch: `/home/arduino/ArduinoApps/first-app/sketch/`
- `first-app` Templates: `/home/arduino/ArduinoApps/first-app/python/templates/`
- Config file: `/home/arduino/shackswitch_config.json`

---

## Repo Structure

```
shackswitch/
├── CLAUDE-UNO-Q.md          — this file
├── README.md                — project overview
├── CHANGELOG.md             — version history
├── shackswitch-v2/          — current source files (reference copies from first-app)
│   ├── main.py              — Flask REST API + smartsdr launcher
│   ├── index.html           — web UI
│   └── sketch.ino           — STM32 firmware
├── services/                — systemd service files
│   ├── shackswitch.service  — systemd service definition
│   └── shackswitch-boot.sh  — boot script
└── docs/                    — legacy documentation
```

---

## Hardware

### Built and Verified

| Item | Detail |
|---|---|
| Microcontroller | Arduino Uno Q (QRB2210 Linux + STM32U585 MCU) |
| Relay shield | G0JKN custom design, NPN/PNP driver, D2-D5, 12V coils |
| RF connectors | 4x SO239 active (expandable to 6 with KK1L) |
| Power | 12V DC → relay coils, 5V via Uno Q USB-C |
| Network | WiFi 5 dual band, IP 10.0.0.145 |
| MCP23017 | Fitted and detected at 0x20 — KK1L board connected |

### Ordered, Not Yet Built

- KK1L 2x6 relay board — 2 inputs, 6 outputs, 12V relays (board connected, LEDs fitted, full testing pending)

### Retired

- Arduino Uno R4 WiFi — replaced by Uno Q STM32 side
- Raspberry Pi 4 (10.0.0.57) — replaced by Uno Q Linux side (Pi retained for git/SSH)

---

## Architecture

```
FlexRadio 6700 (10.0.0.250)
    │ TCP port 4992
    ▼
smartsdr.py (Uno Q Linux — Docker container)
  subscribes to slice events via C1|sub slice all
  maps RF_frequency → band name
  only fires on band change
    │ HTTP GET localhost:5000
    ▼
Flask REST API (Uno Q Linux — Docker container, port 5000)
  reads/writes /home/arduino/shackswitch_config.json
    │ Bridge RPC (arduino-router.sock)
    ▼
STM32 firmware (Uno Q MCU — Zephyr OS)
  provides relay_on/off, get_status, kk1l_* methods
    │ GPIO D2-D5 (3.3V logic) + I2C Wire1 MCP23017 (KK1L)
    ▼
G0JKN relay shield (NPN/PNP, 12V coils) + KK1L 2x6 (MCP23017 at 0x20)
    │
    └── SO239 antenna ports 1-8
```

---

## REST API Endpoints (Flask, port 5000)

| Endpoint | Description |
|---|---|
| GET / | Main web UI |
| GET /status | Full status JSON including kk1l_available |
| GET /relay/[n]/on | Activate relay n |
| GET /relay/[n]/off | Deactivate relay n |
| GET /select?input=[1\|2]&relay=[n] | Toggle relay for input, enforces interlock |
| GET /setband?input=[1\|2]&band=[name] | Auto-switch by band name |
| GET /assign?band=[name]&relay=[n] | Assign band to port |
| GET /assign/clear?band=[name] | Clear band assignment |
| GET /bandmap | Full band/antenna config |
| GET /rename?id=[n]&name=[name] | Rename single port |
| POST /rename/bulk | Rename multiple ports (JSON body) |
| GET /label?input=[1\|2]&name=[name] | Set input label |
| POST /config/ports | Set port count (4, 6 or 8) |
| GET /set_port_count?count=[n] | Set port count (GET version) |
| GET /factory_reset | Reset config to defaults |
| GET /device/config | Read DIP switch value from STM32 |
| GET /kk1l/select?input=[1\|2]&port=[n] | Select KK1L port for input |
| GET /kk1l/deselect_all | Deselect all KK1L ports |
| GET /kk1l/status | KK1L port states |
| GET /kk1l/setband?input=[1\|2]&band=[name] | Auto-switch KK1L by band |

---

## Bridge RPC Methods (STM32 side)

| Method | Args | Returns | Description |
|---|---|---|---|
| relay_on | int n | bool | Energise relay n (1-4) |
| relay_off | int n | bool | De-energise relay n |
| get_status | — | String | Comma separated relay states |
| kk1l_select_a | int port | bool | Connect port to Input A |
| kk1l_select_b | int port | bool | Connect port to Input B |
| kk1l_deselect | int port | bool | 50 ohm terminate port |
| kk1l_deselect_all | — | bool | Safe state all ports |
| kk1l_status | — | String | Port states e.g. "A,0,B,0,0,0" |
| get_config | — | String | DIP switch value 0-15 |

---

## Config File Structure

Stored at `/home/arduino/shackswitch_config.json` on host, mounted into container:

```json
{
  "antennas": {"1": "Antenna 1", "2": "Antenna 2", "3": "Antenna 3", "4": "Antenna 4"},
  "band_map": {
    "160m": null, "80m": null, "60m": null, "40m": null, "30m": null,
    "20m": null, "17m": null, "15m": null, "12m": null, "10m": null, "6m": null
  },
  "input1_relay": null,
  "input2_relay": null,
  "input1_port": null,
  "input2_port": null,
  "port_count": 4,
  "input1_label": "Input A",
  "input2_label": "Input B"
}
```

---

## Web UI

Single page app served by Flask at `http://10.0.0.145:5000/`

**Status page:**
- Two status cards — current band/antenna for Input 1 and Input 2
- 3-column matrix — [Input 1 button] [Antenna Name] [Input 2 button]
- Buttons show port number (1/2), green for Input 1, orange for Input 2
- Interlock flash — antenna name turns red briefly if blocked
- Routes to `/kk1l/select` when kk1l_available, `/select` otherwise
- 5-second auto-refresh

**Settings page:**
- Port count selector — 4, 6 or 8
- Input label editing — rename Input A/B
- Antenna port naming — individual or bulk save
- Band/antenna pigeon hole grid — click to assign bands to ports

---

## App Lab Setup

- **Tool:** Arduino App Lab 0.6.0
- **Board:** Arduino Uno Q at 10.0.0.145
- **Live app name:** `first-app` (not shackswitch)
- **STM32 library:** Arduino_RouterBridge (auto-added)
- **Python packages:** flask (via requirements.txt)
- **Volume mount:** `/home/arduino/shackswitch_config.json:/app/python/config.json`
- **Port exposed:** 5000

---

## Known Constraints and Gotchas

| Issue | Detail |
|---|---|
| Live app is `first-app` | NOT `shackswitch` — always edit first-app files |
| `Serial1` reserved | Used by arduino-router — do not use in sketch |
| `Bridge.update_safe()` private | Use `Bridge.update()` instead |
| `App.run(on_start=...)` unsupported | Call setup() before `App.run()` |
| RPClite no reference params | Use value types or String returns |
| `app.yaml` read-only in App Lab UI | Edit via SSH |
| STM32 sketch loads into RAM | Does not survive cold power cycle without App Lab reflash |
| 3.3V logic on D pins | NPN/PNP shields fine, verify others |
| I2C uses Wire1 not Wire | Uno Q headers use Wire1 for SDA/SCL |
| App Lab serial monitor unreliable | Use Arduino IDE 2.x serial monitor instead |

---

## Autostart Status (Known Issue)

The STM32 sketch loads into RAM via OpenOCD on every App Lab deploy. After a cold power cycle the sketch must be redeployed from App Lab.

**Workaround:** Deploy once from App Lab. The systemd service (`shackswitch`) then starts the Docker container on subsequent warm reboots.

**Boot sequence files:**
- Service: `/etc/systemd/system/shackswitch.service`
- Script: `/home/arduino/shackswitch-boot.sh`
- OpenOCD binary: `/opt/openocd/bin/openocd`
- Sketch binary: `/home/arduino/shackswitch-flash/sketch.ino.bin-zsk.bin`
- Flash config: `/home/arduino/shackswitch-flash/flash_sketch_ram.cfg`

**Forum post pending** — asking Arduino how to reload sketch and re-register Bridge methods without App Lab.

---

## Known Bugs / Next Session

| Issue | Detail |
|---|---|
| KK1L display not correct in web UI | kk1l_available now true, but web UI matrix not routing/displaying KK1L state correctly |
| Inactive ports still showing dimmed | Change ALL_PORTS to portCount in buildMatrix loop to hide completely |

---

## Roadmap

| Priority | Item |
|---|---|
| Immediate | Fix KK1L display in web UI matrix |
| Immediate | Hide inactive ports completely in matrix |
| Immediate | Solve cold boot autostart — Arduino forum post pending |
| Near term | Wire kk1l_* routing into smartsdr.py band changes |
| Near term | KK1L full relay test with RF |
| Near term | Test plan update for v2.0 |
| Roadmap | MCP23017 #3 shack switching (amps, lights, PSU) |
| Roadmap | PA protection sequencer |
| Roadmap | Binaural/diversity RX handling |
| Roadmap | AetherSDR issue #179 native panel |
| Roadmap | Node-RED integration (deferred) |
| Future | TCP control protocol port 9008 |

---

## Session Log

| Date | Achievement |
|---|---|
| 30 Mar 2026 | Full migration from R4+Pi to Uno Q in single session |
| 30 Mar 2026 | Flask REST API, Bridge RPC, all 4 relays working |
| 30 Mar 2026 | smartsdr.py ported, automatic band switching working |
| 30 Mar 2026 | SO2R interlock working |
| 30 Mar 2026 | Config persistence via host volume mount |
| 30 Mar 2026 | Systemd service for container autostart |
| 31 Mar 2026 | Web UI built — dark theme, 3-column matrix, status cards |
| 31 Mar 2026 | Settings page — port count, input labels, antenna naming |
| 31 Mar 2026 | Band/antenna pigeon hole assignment grid |
| 31 Mar 2026 | Interlock flash on web UI |
| 31 Mar 2026 | KK1L and MCP23017 support added to STM32 sketch |
| 01 Apr 2026 | App renamed attempt — first-app remains live app |
| 02 Apr 2026 | Buttons show input number (1/2) not A/B |
| 02 Apr 2026 | Port count switching working in Settings |
| 02 Apr 2026 | Wire1 fix for I2C on Uno Q headers |
| 02 Apr 2026 | MCP23017 detected, kk1l_available: true confirmed |
| 02 Apr 2026 | KK1L port switching working (LEDs responding) |

---

*G0JKN ShackSwitch v2.0 — 73 de G0JKN*

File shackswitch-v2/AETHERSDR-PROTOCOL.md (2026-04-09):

# AetherSDR — 4O3A Antenna Genius Protocol Notes
# G0JKN ShackSwitch Project — 9 Apr 2026

This file documents the 4O3A Antenna Genius TCP/IP protocol as implemented
in AetherSDR, reverse-engineered from the AetherSDR open source codebase
(https://github.com/ten9876/AetherSDR) and confirmed by live testing against
a ShackSwitch emulator.

---

## Overview

ShackSwitch emulates a 4O3A Antenna Genius so AetherSDR can discover and
control it as a peripheral device. The emulator runs alongside Flask on the
Arduino Uno Q Linux side.

---

## UDP Discovery

AetherSDR listens for UDP broadcast packets on port 9007.

**Packet format (broadcast to 255.255.255.255:9007):**
```
AG ip=<ip> port=<tcp_port> v=<version> serial=<serial> name=<name> ports=<radio_ports> antennas=<antenna_count>\r\n
```

**Example:**
```
AG ip=10.0.0.145 port=9007 v=2.0 serial=G0JKN-SW name=ShackSwitch ports=2 antennas=8\r\n
```

- `ports` = number of radio inputs (ShackSwitch has 2: Input A and Input B)
- `antennas` = number of antenna ports (matches active port_count in profile)
- Broadcast every 5 seconds

**Note:** AetherSDR also supports manual IP entry for devices that cannot be
discovered via UDP (remote/VPN/SmartLink connections). Manually configured
devices auto-connect when the Flex radio connects.

---

## TCP Protocol

**Port:** 9007 (same port as UDP discovery)

### Connection Prologue

On client connection, the device sends immediately:
```
V<version> AG\r\n
```
Example: `V2.0 AG\r\n`

### Command Format (client → device)

```
C<seq>|<command>\r\n
```
- `<seq>` = sequence number, starts at 1, increments per command
- `<command>` = command string (see below)

### Response Format (device → client)

**Single-line response:**
```
R<seq>|00|<body>\r\n
```

**Multi-line response** (antenna list, band list):
```
R<seq>|00|<item1>\r\n
R<seq>|00|<item2>\r\n
R<seq>|00|\r\n
```
Final empty-body line signals end of list.

**Unsolicited status push:**
```
S0|<body>\r\n
```

---

## Command Reference

### C<n>|antenna list

Returns all configured antennas.

**Request:** `C1|antenna list\r\n`

**Response (one line per antenna, terminated by empty line):**
```
R1|00|antenna <id> name=<name> tx=<hex_mask> rx=<hex_mask> inband=<hex_mask>\r\n
R1|00|antenna 2 name=80m_Dipole tx=0x2 rx=0x2 inband=0x2\r\n
R1|00|\r\n
```

- `antenna <id>` — space-separated, NOT `antenna=<id>`
- `name` — underscores replace spaces
- `tx`, `rx`, `inband` — 16-bit hex bitmasks, bit N = band ID N+1

**Band bitmask values:**
| Band | ID | Bit | Hex value |
|---|---|---|---|
| 160m | 1 | 0 | 0x0001 |
| 80m  | 2 | 1 | 0x0002 |
| 60m  | 3 | 2 | 0x0004 |
| 40m  | 4 | 3 | 0x0008 |
| 30m  | 5 | 4 | 0x0010 |
| 20m  | 6 | 5 | 0x0020 |
| 17m  | 7 | 6 | 0x0040 |
| 15m  | 8 | 7 | 0x0080 |
| 12m  | 9 | 8 | 0x0100 |
| 10m  | 10| 9 | 0x0200 |
| 6m | 11| 10| 0x0400 |

---

### C<n>|band list

Returns all band definitions.

**Request:** `C2|band list\r\n`

**Response (one line per band, terminated by empty line):**
```
R2|00|band <id> name=<name> freq_start=<mhz> freq_stop=<mhz>\r\n
R2|00|band 1 name=160m freq_start=1.8 freq_stop=2.0\r\n
...
R2|00|\r\n
```

- `band <id>` — space-separated, NOT `band=<id>`
- `freq_start`, `freq_stop` — MHz as float

---

### C<n>|port get <port>

Returns current status of a radio port (1=Input A, 2=Input B).

**Request:** `C3|port get 1\r\n`

**Response:**
```
R3|00|port <n> auto=<0|1> band=<id> rxant=<ant_id> txant=<ant_id> tx=<0|1> inhibit=<0|1>\r\n
```

- `port <n>` — space-separated, NOT `port=<n>`
- `band` — band ID (0 = no band / unknown)
- `rxant`, `txant` — antenna port number (0 = none selected)
- `tx` — 1 if currently transmitting
- `inhibit` — 1 if inhibited

---

### C<n>|sub port all

Subscribe to port status change notifications.

**Request:** `C5|sub port all\r\n`

**Response:** Acknowledge + immediate push of current state:
```
R5|00|\r\n
S0|port 1 auto=1 band=2 rxant=2 txant=2 tx=0 inhibit=0\r\n
S0|port 2 auto=1 band=0 rxant=0 txant=0 tx=0 inhibit=0\r\n
```

Subsequent changes push unsolicited `S0|port N ...` lines.

---

### C<n>|sub relay

Subscribe to relay/antenna state change notifications.

**Request:** `C6|sub relay\r\n`

**Response:** Acknowledge + immediate push of all relay states:
```
R6|00|\r\n
S0|relay=1 state=off\r\n
S0|relay=2 state=on\r\n
```

---

### C<n>|ping

Keep-alive, sent every 30 seconds.

**Request:** `C7|ping\r\n`

**Response:** `R7|00|\r\n`

---

## Implementation Notes

### ShackSwitch Specifics

- ShackSwitch has **2 radio inputs** (Input A = port 1, Input B = port 2)
- Antenna count matches the active profile's `port_count` (2–16)
- Band masks are derived from the antenna capability model (`tx_bands`, `rx_bands`)
- `inband` mask is set equal to `tx` mask (conservative — can refine later)

### Arduino Platform Health Checks

The Arduino App Lab platform sends HTTP GET requests to all exposed ports
for health monitoring. Port 9007 receives these probes from the Docker gateway
(172.x.x.1). The AG emulator detects HTTP connections (first bytes `GET `) and
responds with `HTTP/1.1 200 OK` then closes — these are not logged.

### AetherSDR Version Status

As of AetherSDR **0.8.7** (9 Apr 2026):
- TCP connection, command/response protocol: ✅ working
- UDP discovery: ✅ implemented (ShackSwitch broadcasts, AetherSDR receives)
- Antenna selection UI panel: ❌ not yet implemented
- Band change commands from AetherSDR to device: not yet observed

The AG TCP infrastructure is complete and ready. The antenna selection panel
in AetherSDR appears to be pending future development.

---

## Suggested AetherSDR Issue / Feature Request

If reporting to the AetherSDR developer (https://github.com/ten9876/AetherSDR/issues):

> **Subject:** Antenna Genius peripheral UI panel
>
> The AG TCP protocol implementation in ShackSwitch confirms the connection
> and command/response sequence works correctly in AetherSDR 0.8.7:
> antenna list, band list, port get 1/2, sub port all, sub relay, and ping
> are all sent and responded to correctly. However no antenna selection UI
> appears in AetherSDR after a successful connection. Is the peripheral
> display panel planned for a future release? Happy to assist test against
> a live ShackSwitch implementation.
>
> Test device: G0JKN ShackSwitch — Arduino Uno Q, 8 antenna ports, 2 radio inputs
> IP: manual config (no real AG hardware)

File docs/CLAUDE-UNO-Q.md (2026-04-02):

# CLAUDE-UNO-Q.md — G0JKN ShackSwitch Project Context

This file gives Claude instant context for the ShackSwitch project.
Paste the raw URL of this file at the start of each session:
`https://raw.githubusercontent.com/nigelfenton/shackswitch/main/CLAUDE-UNO-Q.md`

---

## Project Identity

- **Project:** G0JKN ShackSwitch — open source HF shack antenna switcher
- **Builder:** Nigel Fenton, G0JKN (retired, UK)
- **GitHub:** https://github.com/nigelfenton/shackswitch
- **Licence:** MIT
- **Platform:** Arduino Uno Q (migrated from Arduino Uno R4 WiFi + Raspberry Pi 4)

---

## Current Version

**v2.0** — Arduino Uno Q

---

## Repo Structure

```
shackswitch/
├── CLAUDE-UNO-Q.md          — this file
├── CLAUDE.md                — legacy R4 context (historical)
├── README.md                — project overview
├── CHANGELOG.md             — version history
├── shackswitch-v2/          — current source files (reference copies)
│   ├── main.py              — Flask REST API + smartsdr launcher
│   ├── index.html           — web UI
│   └── sketch.ino           — STM32 firmware
├── services/                — systemd service files
│   ├── shackswitch.service  — systemd service definition
│   └── shackswitch-boot.sh  — boot script (OpenOCD flash + container start)
├── firmware/                — legacy R4 firmware (historical)
└── nodered/                 — legacy Pi Node-RED files (historical)
```

Live files on Uno Q at `/home/arduino/ArduinoApps/shackswitch/`

---

## Hardware

### Built and Verified

| Item | Detail |
|---|---|
| Microcontroller | Arduino Uno Q (QRB2210 Linux + STM32U585 MCU) |
| Relay shield | G0JKN custom design, NPN/PNP driver, D2-D5, 12V coils |
| RF connectors | 4x SO239 active (expandable to 6 with KK1L) |
| Power | 12V DC → relay coils, 5V via Uno Q USB-C |
| Network | WiFi 5 dual band, IP 10.0.0.145 |

### Ordered, Not Yet Built

- KK1L 2x6 relay board — 2 inputs, 6 outputs, 12V relays
- MCP23017 GPIO expanders — in hand, not yet wired

### Retired

- Arduino Uno R4 WiFi — replaced by Uno Q STM32 side
- Raspberry Pi 4 (10.0.0.57) — replaced by Uno Q Linux side

---

## Architecture

```
FlexRadio 6700 (10.0.0.250)
    │ TCP port 4992
    ▼
smartsdr.py (Uno Q Linux — Docker container)
  subscribes to slice events via C1|sub slice all
  maps RF_frequency → band name
  only fires on band change
    │ HTTP GET localhost:5000
    ▼
Flask REST API (Uno Q Linux — Docker container, port 5000)
  reads/writes /home/arduino/shackswitch_config.json
    │ Bridge RPC (arduino-router.sock)
    ▼
STM32 firmware (Uno Q MCU — Zephyr OS)
  provides relay_on/off, get_status, kk1l_* methods
    │ GPIO D2-D5 (3.3V logic) + I2C MCP23017 (KK1L)
    ▼
G0JKN relay shield (NPN/PNP, 12V coils) + KK1L 2x6 (planned)
    │
    └── SO239 antenna ports 1-8
```

---

## REST API Endpoints (Flask, port 5000)

| Endpoint | Description |
|---|---|
| GET / | Main web UI |
| GET /status | Full status JSON |
| GET /relay/[n]/on | Activate relay n |
| GET /relay/[n]/off | Deactivate relay n |
| GET /select?input=[1\|2]&relay=[n] | Toggle relay for input, enforces interlock |
| GET /setband?input=[1\|2]&band=[name] | Auto-switch by band name |
| GET /assign?band=[name]&relay=[n] | Assign band to port |
| GET /assign/clear?band=[name] | Clear band assignment |
| GET /bandmap | Full band/antenna config |
| GET /rename?id=[n]&name=[name] | Rename single port |
| POST /rename/bulk | Rename multiple ports (JSON body) |
| GET /label?input=[1\|2]&name=[name] | Set input label |
| POST /config/ports | Set port count (4, 6 or 8) |
| GET /set_port_count?count=[n] | Set port count (GET version) |
| GET /factory_reset | Reset config to defaults |
| GET /device/config | Read DIP switch value from STM32 |
| GET /kk1l/select?input=[1\|2]&port=[n] | Select KK1L port for input |
| GET /kk1l/deselect_all | Deselect all KK1L ports |
| GET /kk1l/status | KK1L port states |
| GET /kk1l/setband?input=[1\|2]&band=[name] | Auto-switch KK1L by band |

---

## Bridge RPC Methods (STM32 side)

| Method | Args | Returns | Description |
|---|---|---|---|
| relay_on | int n | bool | Energise relay n (1-4) |
| relay_off | int n | bool | De-energise relay n |
| get_status | — | String | Comma separated relay states |
| kk1l_select_a | int port | bool | Connect port to Input A |
| kk1l_select_b | int port | bool | Connect port to Input B |
| kk1l_deselect | int port | bool | 50 ohm terminate port |
| kk1l_deselect_all | — | bool | Safe state all ports |
| kk1l_status | — | String | Port states e.g. "A,0,B,0,0,0" |
| get_config | — | String | DIP switch value 0-15 |

---

## Config File Structure

Stored at `/home/arduino/shackswitch_config.json` on host, mounted into container:

```json
{
  "antennas": {"1": "Antenna 1", "2": "Antenna 2", "3": "Antenna 3", "4": "Antenna 4"},
  "band_map": {
    "160m": null, "80m": null, "60m": null, "40m": null, "30m": null,
    "20m": null, "17m": null, "15m": null, "12m": null, "10m": null, "6m": null
  },
  "input1_relay": null,
  "input2_relay": null,
  "input1_port": null,
  "input2_port": null,
  "port_count": 4,
  "input1_label": "Input A",
  "input2_label": "Input B"
}
```

---

## Web UI

Single page app served by Flask at `http://10.0.0.145:5000/`

**Status page:**
- Two status cards — current band/antenna for Input 1 and Input 2
- 3-column matrix — [Input 1 button] [Antenna Name] [Input 2 button]
- Buttons show port number (1/2), green for Input 1, orange for Input 2
- Interlock flash — antenna name turns red briefly if blocked
- Only active ports shown (controlled by port_count setting)
- 5-second auto-refresh

**Settings page:**
- Port count selector — 4, 6 or 8
- Input label editing — rename Input A/B
- Antenna port naming — individual or bulk save
- Band/antenna pigeon hole grid — click to assign bands to ports

---

## App Lab Setup

- **Tool:** Arduino App Lab 0.6.0
- **Board:** Arduino Uno Q at 10.0.0.145
- **App name:** shackswitch (not first-app — that is legacy)
- **STM32 library:** Arduino_RouterBridge (auto-added)
- **Python packages:** flask (via requirements.txt)
- **Volume mount:** `/home/arduino/shackswitch_config.json:/app/python/config.json`
- **Port exposed:** 5000

---

## Known Constraints and Gotchas

| Issue | Detail |
|---|---|
| `Serial1` reserved | Used by arduino-router — do not use in sketch |
| `Bridge.update_safe()` private | Use `Bridge.update()` instead |
| `App.run(on_start=...)` unsupported | Call setup() before `App.run()` |
| RPClite no reference params | Use value types or String returns |
| `app.yaml` read-only in App Lab UI | Edit via SSH |
| STM32 sketch loads into RAM | Does not survive cold power cycle without App Lab reflash |
| 3.3V logic on D pins | NPN/PNP shields fine, verify others |
| Two App Lab apps exist | Use `shackswitch` not `first-app` |

---

## Autostart Status (Known Issue)

The STM32 sketch loads into RAM via OpenOCD on every App Lab deploy. After a cold power cycle the sketch must be redeployed from App Lab.

**Workaround:** Deploy once from App Lab. The systemd service (`shackswitch`) then starts the Docker container on subsequent warm reboots.

**Boot sequence files:**
- Service: `/etc/systemd/system/shackswitch.service`
- Script: `/home/arduino/shackswitch-boot.sh`
- OpenOCD binary: `/opt/openocd/bin/openocd`
- Sketch binary: `/home/arduino/shackswitch-flash/sketch.ino.bin-zsk.bin`
- Flash config: `/home/arduino/shackswitch-flash/flash_sketch_ram.cfg`

**Forum post pending** — asking Arduino how to reload sketch and re-register Bridge methods without App Lab.

---

## Roadmap

| Priority | Item |
|---|---|
| Immediate | Solve cold boot autostart — Arduino forum post pending |
| Immediate | Hide inactive ports completely in matrix |
| Near term | KK1L board build and wiring |
| Near term | MCP23017 I2C wiring and test |
| Near term | Wire kk1l_* endpoints into web UI |
| Near term | smartsdr.py — route to kk1l/setband when KK1L available |
| Near term | Test plan update for v2.0 |
| Roadmap | MCP23017 #3 shack switching (amps, lights, PSU) |
| Roadmap | PA protection sequencer |
| Roadmap | Binaural/diversity RX handling |
| Roadmap | AetherSDR issue #179 native panel |
| Roadmap | Node-RED integration (deferred) |
| Future | TCP control protocol port 9008 |

---

## Session Log

| Date | Achievement |
|---|---|
| 30 Mar 2026 | Full migration from R4+Pi to Uno Q in single session |
| 30 Mar 2026 | Flask REST API, Bridge RPC, all 4 relays working |
| 30 Mar 2026 | smartsdr.py ported, automatic band switching working |
| 30 Mar 2026 | SO2R interlock working |
| 30 Mar 2026 | Config persistence via host volume mount |
| 30 Mar 2026 | Systemd service for container autostart |
| 31 Mar 2026 | Web UI built — dark theme, 3-column matrix, status cards |
| 31 Mar 2026 | Settings page — port count, input labels, antenna naming |
| 31 Mar 2026 | Band/antenna pigeon hole assignment grid |
| 31 Mar 2026 | Interlock flash on web UI |
| 31 Mar 2026 | KK1L and MCP23017 support added to STM32 sketch |
| 01 Apr 2026 | App renamed from first-app to shackswitch in App Lab |
| 02 Apr 2026 | Buttons show input number (1/2) not A/B |
| 02 Apr 2026 | Port count switching working in Settings |

---

*G0JKN ShackSwitch v2.0 — 73 de G0JKN*

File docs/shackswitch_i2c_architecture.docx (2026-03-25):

G0JKN ShackSwitch

I2C Bus Architecture & Expansion Plan

Design Sketch — March 2026

# Overview

This document describes the I2C bus architecture for the G0JKN ShackSwitch — an open source Arduino-based HF shack controller. The design uses MCP23017 I2C GPIO expander chips to extend the Arduino Uno R4 WiFi's native GPIO, enabling control of a KK1L 2x6 relay matrix antenna switch, hardware configuration via jumpers, shack power sequencing, and future expansion to PA protection, BCD band decoding, and Radioberry integration.

The entire expansion chain runs on just two wires from the Arduino (SDA and SCL), keeping wiring minimal and the system modular. Each MCP23017 is address-configured via three hardware pins, allowing up to eight devices on a single bus.

# I2C Bus Map

Address | Device | Status | Function
0x20 | MCP23017 #1 | Build now | Relay matrix control (KK1L 2x6)
0x21 | MCP23017 #2 | Build now | Hardware config jumpers (board type, inputs, radio)
0x22 | MCP23017 #3 | Roadmap | Shack switching — amps, lights, PSU sequencing
0x23-0x27 | TBD | Roadmap | Radioberry, BCD band decoder, PA protection

# MCP23017 #1 — Relay Matrix Control (0x20)

Drives the KK1L 2x6 relay board. GPA controls Radio 1 outputs, GPB controls Radio 2 outputs. Two spare pins on GPB are reserved for future expansion.

Pin | Direction | Function
GPA0 | — | Spare (pin 0 reserved — relay numbers match pin numbers)
GPA1 | Output | Radio 1 — Antenna port 1
GPA2 | Output | Radio 1 — Antenna port 2
GPA3 | Output | Radio 1 — Antenna port 3
GPA4 | Output | Radio 1 — Antenna port 4
GPA5 | Output | Radio 1 — Antenna port 5
GPA6 | Output | Radio 1 — Antenna port 6
GPA7 | — | Spare (future expansion)
GPB0 | — | Spare (pin 0 reserved — relay numbers match pin numbers)
GPB1 | Output | Radio 2 — Antenna port 1
GPB2 | Output | Radio 2 — Antenna port 2
GPB3 | Output | Radio 2 — Antenna port 3
GPB4 | Output | Radio 2 — Antenna port 4
GPB5 | Output | Radio 2 — Antenna port 5
GPB6 | Output | Radio 2 — Antenna port 6
GPB7 | — | Spare (future expansion)

The KK1L 2x6 board hardware enforces that no two radios can share the same antenna port. The firmware must also enforce this in software before sending any switch command.

# MCP23017 #2 — Hardware Config Jumpers (0x21)

Read on every boot and after factory reset. GPA pins are wired to jumpers or a DIP switch on the PCB. The firmware reads the byte and derives its complete operating configuration — no reflashing or web configuration needed for basic hardware setup.

Bits | Field | Values
GPA 0-1 | Board type | 00 = 4-port original | 01 = KK1L 2x6 | 10 = KK1L 2x8 | 11 = future
GPA 2-3 | Num inputs | 00 = 1 radio | 01 = 2 radios | 10 = 4 radios
GPA 4-5 | Radio type | 00 = FlexRadio | 01 = Generic CAT | 10 = BCD decoder
GPA 6 | PA present | 0 = no PA | 1 = PA fitted
GPA 7 | Spare | Reserved for future use
GPB 0-7 | Spare | Reserved — all inputs, pulled high

Boot sequence — config detection

Wire.begin();

Wire.beginTransmission(0x21); // probe config chip

bool configFound = (Wire.endTransmission() == 0);

if (configFound) {

uint8_t cfg = mcp2.readGPIOA(); // read jumper byte

boardType = (cfg >> 0) & 0x03;

numInputs = (cfg >> 2) & 0x03;

radioType = (cfg >> 4) & 0x03;

paPresent = (cfg >> 6) & 0x01;

} else {

// Fall back to EEPROM stored config or defaults

}

# MCP23017 #3 — Shack Switching (0x22) — Roadmap

Handles station power sequencing, PA interlock, and shack accessories. Critically, GPB pins are inputs — the firmware reads fault and protection signals back from hardware, giving closed-loop protection rather than blind switching.

Pin | Direction | Function
GPA0 | — | Spare (pin 0 reserved — function numbers match pin numbers)
GPA1 | Output | PA power relay (12V feed or SSR input)
GPA2 | Output | PA TX enable / PTT interlock
GPA3 | Output | ATU power
GPA4 | Output | Preamp / RX antenna relay
GPA5 | Output | Shack master power (via SSR or contactor)
GPA6 | Output | Cooling fan
GPA7 | Output | Shack lighting
GPB0 | — | Spare (pin 0 reserved)
GPB1 | Input | PA fault (read back from amp)
GPB2 | Input | SWR trip input (from protection circuit)
GPB3 | Input | Temperature trip input
GPB4 | Input | Antenna relay confirmed (read back from MCP23017 #1)
GPB5-7 | — | Spare / future protection inputs

// Activate antenna port n (1-6) for radio r (1-2)

// Pin number == port number — GPA0/GPB0 deliberately spare

void setAntenna(uint8_t radio, uint8_t port) {

uint8_t mask = (1 << port); // port 1 = bit 1, port 2 = bit 2 etc.

if (radio == 1) mcp1.writeGPIOA(mask);

if (radio == 2) mcp1.writeGPIOB(mask);

}

TX safety interlock

bool safeTX() {

bool antConfirmed = mcp3.digitalRead(GPB3);

bool paFaultClear = !mcp3.digitalRead(GPB0);

bool swrOK = !mcp3.digitalRead(GPB1);

bool tempOK = !mcp3.digitalRead(GPB2);

return antConfirmed && paFaultClear && swrOK && tempOK;

}

Shack-on power sequence

The following sequence must be followed in order to safely bring the station on air:

- Assert shack master power (GPA4)
- Wait 2 seconds — PSUs stabilise
- Assert PA power relay (GPA0)
- Wait 3 seconds — PA bias settles
- Assert PA TX enable (GPA1)
- Update Nextion display: Station Ready

The shack-off sequence reverses this order. The PA is always powered down before the PSU.

For mains voltage switching (shack master power), use a solid state relay (SSR) driven by GPA4. The MCP23017 GPIO is 3.3V / 25mA — sufficient for an SSR logic input but not for direct relay coil drive. For 12V relay coils, use a transistor driver stage (BC547 or similar) as used on the existing ShackSwitch shield.

# Extended /status JSON

The web server status endpoint extends to report all subsystem states. AetherSDR and Node-RED poll this endpoint and adapt their UI based on the reported topology:

{"inputs":2,"outputs":6,

"radio1":2,"radio2":4,

"pa_power":true,"pa_fault":false,

"swr_trip":false,"temp_ok":true,

"shack_on":true,"fan":false}

# KK1L 2x6 Relay Board — Key Specs

Parameter | Value
Price | $33.00 (kk1l.com)
PCB | FR4 double-sided, 2oz copper
Power rating | 1500W+ (2800W key-down into 50 ohms)
Port-to-port isolation | >61dB
Relay activation | 12V DC
Unused port termination | 50 ohms (reduces reradiation and static)
Safety | Impossible to connect both radios to same port
Control lines required | 12 total (6 per radio input)
Dimensions | 10.1875" x 6.5"

# References & Links

- ShackSwitch firmware: https://github.com/nigelfenton/shackswitch
- AetherSDR project: https://github.com/ten9876/AetherSDR
- AetherSDR issue #179 (antenna switch integration): https://github.com/ten9876/AetherSDR/issues/179
- KK1L 2x6 relay board: https://kk1l.com/store/2x6-relay-board/
- MCP23017 datasheet: https://www.microchip.com/en-us/product/mcp23017

G0JKN ShackSwitch — Design Sketch, March 2026. Open source under MIT Licence.

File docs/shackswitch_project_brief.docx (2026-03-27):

G0JKN ShackSwitch

Project Brief — Version 1.5

Nigel Fenton, G0JKN

Last updated: 27 March 2026

# 1. Project Overview

The G0JKN ShackSwitch is an open-source Arduino-based HF shack controller and antenna switcher, designed and built by Nigel Fenton (G0JKN), a retired amateur radio operator based in the UK.

The device provides local touchscreen control, web-based remote control, a TCP control protocol, UDP network discovery, SO2R interlock logic, and FlexRadio band tracking. It is designed to be hardware-configurable without firmware reflashing, using I2C GPIO expanders for board detection at boot.

GitHub repository: https://github.com/nigelfenton/shackswitch

# 2. Current Hardware (Built and Verified)

Component | Detail
Microcontroller | Arduino Uno R4 WiFi — main controller
Touchscreen | Nextion NX4832T035 3.5" colour display — local control via EasyNextionLibrary
Relay module | 4x 5V relay on pins D2–D5 — antenna switching
Shield | Custom Arduino shield with relays, transistor drivers and connectors
RF connectors | 5x SO239 — one radio input, four antenna outputs
Power | 12V DC supply, buck converter 12V→5V
Enclosure | 3D printed, designed in Fusion 360
Firmware | v1.5 — see Section 4 for full feature list

# 3. Expansion Hardware (Ordered, Not Yet Built)

The following hardware has been ordered and will be integrated in the next build phase:

- KK1L 2×6 relay board — upgrades from 4-port to 2-input 6-output matrix. 1500W+, 61dB isolation, 12V relays, 12 control lines required. Source: kk1l.com
- MCP23017 I2C GPIO expanders — to drive the KK1L board and provide hardware configuration detection

# 4. Firmware v1.5 — Feature Summary

The current firmware is v1.5, a significant advance on the v1.4 described in earlier documentation. All features below are implemented and verified.

## 4.1 Web Server (Port 80)

- Relay control via browser UI — /[n]/on and /[n]/off
- Antenna rename — persists to EEPROM, updates Nextion and web page
- Status endpoint — GET /status returns relay states, band data and SO2R status
- Band update endpoint — GET /setband?input=[1|2]&band=[name] sets band for Input 1 or Input 2
- Settings page — WiFi SSID/password configuration

## 4.2 TCP Control Protocol (Port 9008)

- Line-based protocol: commands prefixed C[seq]|, responses prefixed R[seq]| or S0|
- Commands: ping, antenna list, band list, port get, port set, sub port all, interlock set
- Designed for AetherSDR integration and future Node-RED TCP control
- Keepalive — S0|ping sent every 30 seconds to connected client

## 4.3 UDP Discovery Beacon

- Broadcasts device identity every 5 seconds on port 9008
- Payload includes device name, serial, version, IP address, port count and radio count
- Enables automatic discovery by AetherSDR and other network clients

## 4.4 FlexRadio Band Tracking

- portA and portB structures track band, antenna selection, TX state and inhibit status independently
- Band defined by ID (1–11 covering 160m–6m) with frequency range lookup via bandForFreq()
- Band name reverse lookup via band name string → ID for REST /setband endpoint
- Band display updated on Nextion via tBandA, tBandB, tSO2R components

## 4.5 SO2R Interlock

- Evaluates interlock whenever TX state or band changes
- Inhibits Radio B if both radios are transmitting on the same band or same antenna
- Nextion tSO2R shows SO2R OK (green) or INHIBIT (orange)
- Interlock state included in /status REST response and TCP port status push

## 4.6 Other Features

- NTP time sync → RTC, displayed on Nextion tClock
- WiFi RSSI monitoring on Nextion monitor page
- Background WiFi reconnect every 30 seconds if connection lost
- Factory reset with double-tap confirmation and 5-second safety timeout
- LED matrix displays active relay number or ground symbol

# 5. REST API Endpoints

Endpoint | Description
GET /status | Returns relay states, bandA, bandB, so2r as JSON
GET /[n]/on | Activate relay n (1–4), ground all others
GET /[n]/off | Ground relay n
GET /rename?id=[n]&name=[name] | Rename antenna port n, persist to EEPROM
GET /setband?input=[1|2]&band=[name] | Set band for Input 1 or 2 by name (e.g. 40m). Updates Nextion and evaluates SO2R interlock.
GET /settings | Settings web page

# 6. Input Port Architecture

The ShackSwitch is architecturally a two-input device. The two inputs are defined at the hardware level by the KK1L 2×6 relay matrix (2 inputs, 6 outputs) and reflected in the firmware port model.

Input 1 and Input 2 are the correct terms throughout firmware, API and documentation. What is connected to each input is configuration, not definition:

- Current setup: Input 1 = FlexRadio Slice A, Input 2 = FlexRadio Slice B
- Alternative: Input 1 = Radio A, Input 2 = Radio B (two separate transceivers)

The FlexRadio 6000 series can present multiple receive slices simultaneously, each potentially on a different band, with TX active on only one slice at a time. For antenna switching purposes the TX slice is the safety-critical path. The Node-RED integration should subscribe to TX slice identity from SmartSDR, not just band change events.

Note: Multi-RX within a single slice (up to 4 RX, 2 per slice) is a known complexity. RX-only paths do not require independent antenna switching. This is logged as a design consideration for the Node-RED flow and PA protection logic.

# 7. I2C Bus Architecture (Planned)

Address | Device | Purpose
0x20 | MCP23017 #1 | KK1L 2×6 relay matrix control
0x21 | MCP23017 #2 | Hardware config jumpers (board type, inputs, radio type, PA present)
0x22 | MCP23017 #3 | Shack switching — amps, lights, PSU sequencing (roadmap)
0x23–0x27 | TBD | Radioberry, BCD decoder, PA protection (roadmap)

## 7.1 MCP23017 #1 Pin Map (KK1L Control)

Pin numbering convention: pin number always equals port number. GPA0 and GPB0 are deliberately spare. Firmware uses mask = (1 << port) — unambiguous and clean.

Pin | Assignment
GPA0 | Spare
GPA1–6 | Input 1 (Slice A) — Antenna ports 1–6
GPA7 | Spare
GPB0 | Spare
GPB1–6 | Input 2 (Slice B) — Antenna ports 1–6
GPB7 | Spare

## 7.2 MCP23017 #2 Config Bits

Bits | Values | Meaning
0–1 | 00=4-port, 01=2×6, 10=2×8, 11=future | Board type
2–3 | 00=1, 01=2, 10=4 | Number of inputs
4–5 | 00=Flex, 01=generic CAT, 10=BCD | Radio type
6 | 0/1 | PA present
7 | — | Spare

Boot detection: firmware probes 0x21 at startup, reads config byte, derives operating mode. Falls back to EEPROM defaults if chip not found. No reflashing required when changing hardware.

# 8. Related Project — AetherSDR

AetherSDR (https://github.com/ten9876/AetherSDR) is a Linux-native Qt6/C++20 FlexRadio client. Nigel raised issue #179 proposing a native antenna switch integration panel that communicates with the ShackSwitch REST API and TCP protocol.

Integration points:

- REST /status — panel polls for relay state, band and SO2R status
- REST /[n]/on and /[n]/off — panel drives relay selection
- TCP port 9008 — richer integration via port set and interlock set commands
- UDP discovery — AetherSDR can auto-discover ShackSwitch on the local network

The AetherSDR panel should label inputs as Input 1 / Input 2 (or user-renameable) rather than hard-coding Radio 1 / Radio 2, to support both single-radio dual-slice and two-radio configurations.

# 9. Node-RED Integration (Planned)

Node-RED running on a Raspberry Pi will bridge FlexRadio SmartSDR frequency data to the ShackSwitch, enabling automatic band-based antenna switching.

Requirements documented, implementation not yet started:

- Subscribe to TX slice identity and band change events from SmartSDR
- Determine which input port corresponds to the active TX slice
- Call GET /setband?input=[1|2]&band=[name] on band change
- Debounce rapid VFO changes to avoid relay chatter
- Handle radio startup, disconnect and split operation gracefully
- Do not switch antennas on RX-only slice band changes without TX slice confirmation

# 10. Nextion HMI Components

The following components are defined on the Nextion display. Label widths for antenna names (t3–t6) require adjustment in the Nextion editor to accommodate longer names up to 25 characters.

Component | Purpose
b1–b4 | Dual-state antenna selector buttons (page 0)
t3–t6 | Antenna name labels (t3=b1, t4=b2, t5=b3, t6=b4)
tBandA | Current band for Input 1 / Slice A
tBandB | Current band for Input 2 / Slice B
tSO2R | SO2R status — SO2R OK (green) or INHIBIT (orange)
tState | Antenna state — ANT Active or ANT Grounded
tClock | RTC time display
t1 | WiFi IP address
tRSSI | WiFi signal strength in dBm (monitor page)
nSignal | WiFi signal quality bar (monitor page)
b0 | IP address button (monitor page)

# 11. Project Documents

- shackswitch_project_brief.docx — this document
- shackswitch_i2c_architecture.docx — full I2C bus map and pin tables
- shackswitch_test_plan.docx — build and commissioning test plan (covers original 4-port build; update required for v1.5 and KK1L expansion)

# 12. Roadmap

Priority | Item | Notes
Immediate | Nextion label widths | Increase t3–t6 component width in HMI editor
Near term | KK1L board build | Hardware ordered. Requires transistor/ULN2803 driver stage for 12V relays from MCP23017 outputs.
Near term | MCP23017 integration | Firmware support for 0x20 relay matrix and 0x21 boot config detection
Near term | Node-RED flow | SmartSDR → /setband integration. TX slice tracking essential.
Near term | Test plan update | Update shackswitch_test_plan.docx for v1.5 features and KK1L build
Near term | AetherSDR #179 | Confirm API sufficiency for 2-input matrix. Neutral input labelling in panel.
Roadmap | MCP23017 #3 | Shack switching — amps, lights, PSU sequencing
Roadmap | PA protection | TX slice tracking feeds into sequencer logic. Must not fire PA on wrong antenna.
Roadmap | Multi-RX handling | FlexRadio multi-RX per slice. RX-only paths do not drive switching. TX slice is master.
Roadmap | Radioberry / BCD | 0x23+ on I2C bus, TBD

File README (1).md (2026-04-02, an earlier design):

# G0JKN ShackSwitch

Open source HF shack antenna switcher for amateur radio operators.

**Builder:** Nigel Fenton, G0JKN (retired, UK)
**Licence:** MIT

---

## What is ShackSwitch?

ShackSwitch is an antenna switching system that automatically selects the correct antenna when you change band on your radio. It supports two radio inputs (SO2R capable) with interlock protection to prevent both inputs selecting the same antenna simultaneously.

It integrates directly with FlexRadio SmartSDR via the TCP API, tracking band changes in real time and switching antennas automatically.

---

## Current Platform — v2.0

**Arduino Uno Q** — a single board combining a Qualcomm QRB2210 Linux processor with an STM32U585 real-time microcontroller.

- Linux side runs the Flask REST API and SmartSDR band tracker
- STM32 side drives the relay hardware
- Web UI accessible from any browser on the network
- No separate Raspberry Pi or Arduino R4 required

---

## Features

- Automatic antenna switching triggered by SmartSDR band changes
- Two input support (SO2R) with hardware interlock
- Web UI — status display, manual switching, settings
- Band-to-antenna assignment grid
- Configurable port count — 4, 6 or 8 ports
- Customisable antenna and input names
- KK1L 2x6 relay board support (firmware ready, hardware pending)
- MCP23017 I2C GPIO expander support

---

## Hardware

- Arduino Uno Q
- G0JKN custom relay shield (NPN/PNP driver, 12V coils)
- KK1L 2x6 relay board (ordered, not yet built)
- FlexRadio 6700

---

## Web UI

Access at `http://[board-ip]:5000/`

**Status page** — live antenna selection, manual switching, interlock display

**Settings page** — port count, input labels, antenna names, band assignments

---

## Repository Structure

```
shackswitch-v2/    — current source (Flask API, web UI, STM32 sketch)
services/          — systemd service files for autostart
firmware/          — legacy Arduino R4 firmware (v1.5, historical)
nodered/           — legacy Node-RED/Pi files (historical)
```

---

## Version History

See [CHANGELOG.md](CHANGELOG.md)

---

*73 de G0JKN*

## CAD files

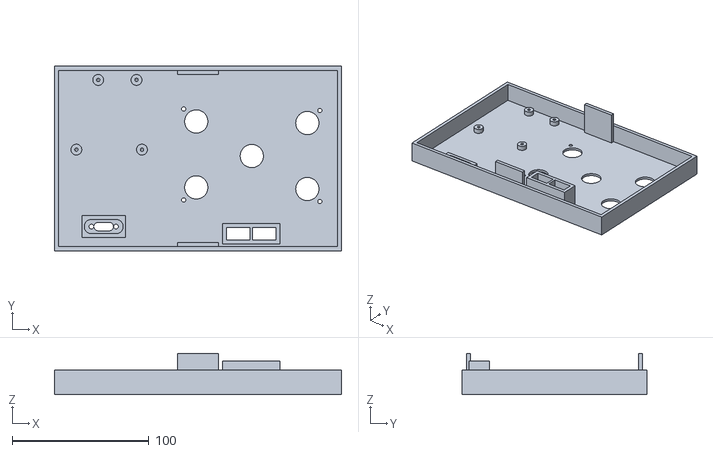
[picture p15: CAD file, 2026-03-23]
hardwear/3d STL files/antenna switch rear panel.stl
210.0 x 135.0 x 30.0

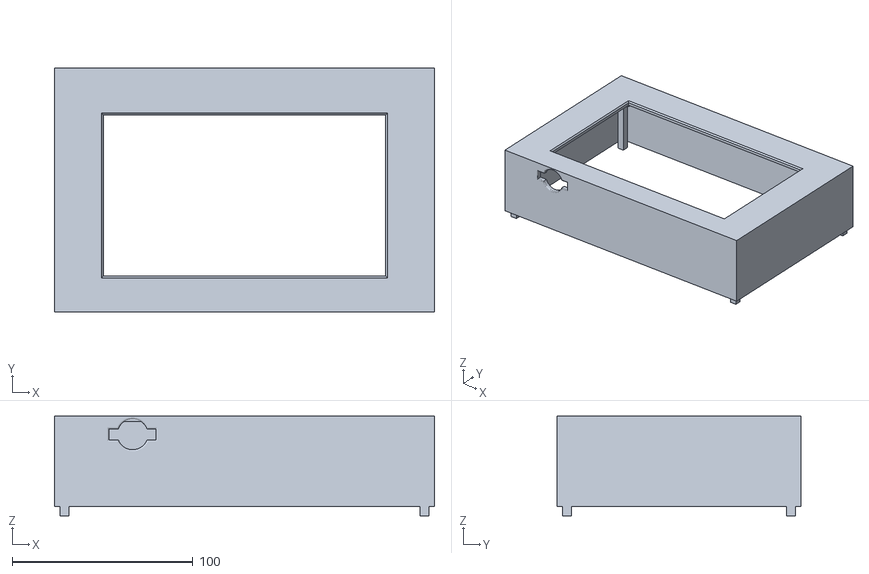
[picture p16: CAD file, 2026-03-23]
hardwear/3d STL files/antenna relay front panel with cf card cutout.stl
210.0 x 135.0 x 55.0

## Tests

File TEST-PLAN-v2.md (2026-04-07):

# G0JKN ShackSwitch v2.0 — Test Plan

**Project:** G0JKN ShackSwitch
**Version:** 2.0 — Arduino Uno Q
**Date:** April 2026
**Tester:** Nigel Fenton, G0JKN

---

## Overview

This test plan covers verification of ShackSwitch v2.0 running on the Arduino Uno Q platform. It supersedes any v1.5 test documentation. Tests are grouped by system area and should be performed in order where dependencies exist.

**Test environment:**
- Arduino Uno Q at 10.0.0.145
- FlexRadio 6700 at 10.0.0.250
- RF-Kit RF2K-S amplifier at 10.0.0.78 (when available)
- Test PC / browser on same LAN
- App Lab 0.6.0 (for sketch deployment)

**Pass criteria:** Each test marked PASS / FAIL / N/A with notes.

---

## Section 1 — Hardware Power-Up and Boot

| # | Test | Expected Result | Result | Notes |
|---|---|---|---|---|
| 1.1 | Apply 12V DC to relay shield | Relay shield power LED illuminates | | |
| 1.2 | Connect Uno Q via USB-C (5V) | Uno Q boots, App Lab detects board at 10.0.0.145 | | |
| 1.3 | Warm reboot — restart Docker container via systemd | ShackSwitch web UI accessible within 30 seconds | | |
| 1.4 | Cold power cycle (remove 12V and USB-C, reapply) | STM32 sketch requires redeploy from App Lab (known issue) | | |
| 1.5 | After cold boot, redeploy sketch from App Lab | All relay and KK1L functions restored | | |

---

## Section 2 — Network and Web UI Availability

| # | Test | Expected Result | Result | Notes |
|---|---|---|---|---|
| 2.1 | Navigate to http://10.0.0.145:5000/ | ShackSwitch Status page loads with dark theme | | |
| 2.2 | Check page title and subtitle | Shows "G0JKN ShackSwitch" and "v2.0 — Arduino Uno Q — 10.0.0.145 — N-port" | | |
| 2.3 | Wait 5 seconds with no action | Status page auto-refreshes (Last update time changes) | | |
| 2.4 | Navigate to Settings page | Settings page loads with port count, labels, antenna names, band grid | | |
| 2.5 | Navigate to Amplifier page | Amplifier page loads showing amp status section | | |
| 2.6 | Navigate back to Status page | Status page loads and resumes auto-poll | | |
| 2.7 | GET http://10.0.0.145:5000/status | Returns valid JSON with ok:true, relays, kk1l, port_count, labels | | |
| 2.8 | GET http://10.0.0.145:5000/bandmap | Returns valid JSON with band_map and antennas | | |

---

## Section 3 — Relay Shield (D2-D5, Ports 1-4)

| # | Test | Expected Result | Result | Notes |
|---|---|---|---|---|
| 3.1 | GET /relay/1/on | Relay 1 energises — audible click, LED/indicator on shield | | |
| 3.2 | GET /relay/1/off | Relay 1 de-energises — click, LED off | | |
| 3.3 | Repeat 3.1-3.2 for relays 2, 3 and 4 | Each relay operates independently | | |
| 3.4 | GET /status after relay 1 on | JSON shows "1":1 in relays object | | |
| 3.5 | Activate relay 1 via web UI matrix button (Input A) | Relay 1 energises, button turns green with "1" | | |
| 3.6 | Click same button again (toggle off) | Relay 1 de-energises, button returns to dot | | |
| 3.7 | Activate relay 1 for Input A, attempt relay 1 for Input B | Interlock rejected — antenna name flashes red briefly | | |
| 3.8 | Activate relay 1 for Input A, activate relay 2 for Input B | Both relays active simultaneously, correct colours shown | | |
| 3.9 | RF path test — connect antenna analyser to SO239 port 1 | Relay closes RF path cleanly, no insertion loss anomaly | | |
| 3.10 | RF path test — repeat for ports 2, 3 and 4 | All ports switch cleanly | | |

---

## Section 4 — KK1L 2x6 Relay Board (MCP23017)

| # | Test | Expected Result | Result | Notes |
|---|---|---|---|---|
| 4.1 | GET /status | kk1l_available: true in response | | |
| 4.2 | GET /kk1l/status | Returns available:true and port states for 6 ports | | |
| 4.3 | GET /kk1l/select?input=1&port=1 | KK1L port 1 Input A LED illuminates on board | | |
| 4.4 | GET /kk1l/select?input=2&port=2 | KK1L port 2 Input B LED illuminates on board | | |
| 4.5 | Attempt GET /kk1l/select?input=2&port=1 (port 1 in use by input 1) | Interlock rejected — returns 409 | | |
| 4.6 | GET /kk1l/deselect_all | All KK1L LEDs extinguish | | |
| 4.7 | Select KK1L port via web UI matrix button | Correct port LED illuminates, button shows 1 or 2 in correct colour | | |
| 4.8 | Web UI matrix routing check | When kk1l_available, buttons route to /kk1l/select not /select | | |
| 4.9 | KK1L RF path test — connect analyser to KK1L output port 1 | RF path closes correctly | | |
| 4.10 | KK1L RF path test — repeat for all 6 output ports | All 6 ports switch cleanly | | |
| 4.11 | KK1L idle ports — confirm 50 ohm termination on inactive ports | Inactive ports show correct impedance | | |

---

## Section 5 — Configuration Persistence

| # | Test | Expected Result | Result | Notes |
|---|---|---|---|---|
| 5.1 | Rename port 1 to "40m Doublet" via Settings page | Name saves, appears in matrix on Status page | | |
| 5.2 | Rename Input A label to "Flex 6700 A" | Label saves, appears in status card header | | |
| 5.3 | Assign 40m band to port 1 via band grid | Assignment saved, visible in grid | | |
| 5.4 | Restart Docker container | Port name, input label and band assignment all persist | | |
| 5.5 | Bulk rename all active ports via Settings | All names save in single operation | | |
| 5.6 | Change port count to 6 | Matrix shows 6 ports, settings reflects change | | |
| 5.7 | Change port count to 8 | Matrix shows 8 ports | | |
| 5.8 | Change port count back to 4 | Matrix shows 4 ports, ports 5-8 hidden | | |
| 5.9 | GET /factory_reset | Config returns to defaults, relay states cleared | | |
| 5.10 | GET /device/config | Returns valid DIP switch value (0-15) | | |

---

## Section 6 — SmartSDR Automatic Band Switching

| # | Test | Expected Result | Result | Notes |
|---|---|---|---|---|
| 6.1 | Confirm smartsdr.py is running in Docker container | Container logs show "SmartSDR tracker started" | | |
| 6.2 | Confirm FlexRadio 6700 reachable at 10.0.0.250 port 4992 | smartsdr.py log shows connected | | |
| 6.3 | Change Slice A to 40m in SmartSDR | ShackSwitch switches to port assigned to 40m (if assigned) | | |
| 6.4 | Change Slice A to 20m | ShackSwitch switches to 20m port | | |
| 6.5 | Change Slice A to a band with no port assigned | No switch occurs — no error | | |
| 6.6 | Band change fires only on actual band change, not frequency within band | No spurious switching while tuning within 40m | | |
| 6.7 | GET /setband?input=1&band=40m manually | Switches to 40m port directly | | |
| 6.8 | GET /kk1l/setband?input=1&band=40m | KK1L switches to 40m port directly | | |

---

## Section 7 — REST API Completeness

| # | Test | Expected Result | Result | Notes |
|---|---|---|---|---|
| 7.1 | GET /select?input=1&relay=1 | Relay 1 selected for input 1 | | |
| 7.2 | GET /select?input=1&relay=1 (toggle) | Relay 1 deselected | | |
| 7.3 | GET /assign?band=40m&relay=1 | 40m assigned to port 1 | | |
| 7.4 | GET /assign/clear?band=40m | 40m assignment cleared | | |
| 7.5 | GET /rename?id=1&name=TestAnt | Port 1 renamed | | |
| 7.6 | POST /rename/bulk with JSON body | Multiple ports renamed in one call | | |
| 7.7 | GET /label?input=1&name=Radio+A | Input 1 label updated | | |
| 7.8 | POST /config/ports with {"port_count":6} | Port count set to 6 | | |
| 7.9 | GET /set_port_count?count=4 | Port count set to 4 via GET | | |
| 7.10 | GET /relay/[n]/on and off for n=1 to 4 | All direct relay endpoints respond correctly | | |

---

## Section 8 — RF-Kit RF2K-S Amplifier Integration

*Note: These tests require the RF2K-S to be powered and reachable at 10.0.0.78 port 8080.*
*Mark N/A if amp not available during testing.*

| # | Test | Expected Result | Result | Notes |
|---|---|---|---|---|
| 8.1 | Confirm RF2K-S reachable: curl http://10.0.0.78:8080/info | Returns device info JSON | | |
| 8.2 | Check RF2K-S firmware supports API (SW G108C132 or later) | Firmware version confirmed in /info response | | |
| 8.3 | GET /rfkit/config | Returns rfkit_ip: "10.0.0.78", rfkit_enabled: false/true | | |
| 8.4 | GET /rfkit/status with amp online | Returns available:true, operate_mode, band, power, SWR, temp | | |
| 8.5 | GET /rfkit/status with amp offline | Returns available:false, no error crash | | |
| 8.6 | Amplifier page — amp online | Shows mode badge, metrics (band, fwd power, SWR, temp, volts, amps) | | |
| 8.7 | Amplifier page — amp offline | Shows "Amplifier unreachable" message gracefully | | |
| 8.8 | Amplifier page — Standby/Operate toggle | PUT /rfkit/operate switches mode, badge updates | | |
| 8.9 | Amplifier page — fault indicator | Fault badge visible when amp reports fault | | |
| 8.10 | Amplifier page — Reset Fault button | POST /rfkit/fault/reset clears fault, badge disappears | | |
| 8.11 | Amplifier page — save IP address | New IP saved to config, amp poll restarts | | |
| 8.12 | PA sequencing (when implemented) — band change | Sequence: STANDBY → switch antenna → set amp antenna → OPERATE | | |

---

## Section 9 — Autostart and System Services

| # | Test | Expected Result | Result | Notes |
|---|---|---|---|---|
| 9.1 | Check systemd service status | sudo systemctl status shackswitch shows active (running) | | |
| 9.2 | Warm reboot (reboot command on Uno Q Linux) | Docker container restarts automatically, web UI available within 30s | | |
| 9.3 | shackswitch-boot.sh — restart arduino-router then Docker | Script completes, Bridge RPC methods available | | |
| 9.4 | Verify STM32 sketch loaded after warm reboot | GET /status returns relay data (not error) — confirms Bridge active | | |
| 9.5 | Cold power cycle — STM32 RAM cleared | GET /status fails or returns bridge error until sketch redeployed | | |
| 9.6 | Redeploy sketch from App Lab after cold boot | GET /status returns correct data, all relay/KK1L functions restored | | |

---

## Section 10 — Web UI Display and Interaction

| # | Test | Expected Result | Result | Notes |
|---|---|---|---|---|
| 10.1 | Status page matrix — active port buttons | Active Input A port shows green button with "1" | | |
| 10.2 | Status page matrix — active port buttons | Active Input B port shows orange button with "2" | | |
| 10.3 | Status page matrix — idle ports | Idle ports show grey "·" dot buttons | | |
| 10.4 | Status page matrix — inactive ports (beyond port count) | Ports beyond port count are hidden completely | | |
| 10.5 | Status page — interlock flash | Clicking an in-use port flashes antenna name red for ~800ms | | |
| 10.6 | Status page — status cards | Input A and B cards show correct current band and antenna | | |
| 10.7 | Settings page — port count buttons | Active port count button highlighted | | |
| 10.8 | Settings page — band assignment grid | Greyed rows visible for inactive ports | | |
| 10.9 | Settings page — assigned bands | Tick mark (✓) shows in correct grid cell | | |
| 10.10 | Mobile browser test | Web UI usable on smartphone browser on same WiFi network | | |

---

## Section 11 — Error and Edge Cases

| # | Test | Expected Result | Result | Notes |
|---|---|---|---|---|
| 11.1 | GET /select with missing relay parameter | Returns 400 with error message | | |
| 11.2 | GET /kk1l/select with port out of range | Returns 400 with "out of range" message | | |
| 11.3 | GET /setband with unassigned band | Returns 404 gracefully | | |
| 11.4 | POST /config/ports with invalid count (e.g. 5) | Returns 400 with "must be 4, 6 or 8" | | |
| 11.5 | SmartSDR disconnected mid-session | smartsdr.py reconnects or fails gracefully — no Flask crash | | |
| 11.6 | RF2K-S unreachable during /setband | ShackSwitch switches antenna normally, logs rfkit failure — no crash | | |
| 11.7 | Two browsers open simultaneously | Both reflect correct state after next poll | | |
| 11.8 | Rapid repeated button clicks | No relay chatter or config corruption | | |

---

## Test Summary

| Section | Tests | Pass | Fail | N/A |
|---|---|---|---|---|
| 1 — Hardware Boot | 5 | | | |
| 2 — Network / Web UI | 8 | | | |
| 3 — Relay Shield | 10 | | | |
| 4 — KK1L Board | 11 | | | |
| 5 — Config Persistence | 10 | | | |
| 6 — SmartSDR Band Switching | 8 | | | |
| 7 — REST API | 10 | | | |
| 8 — RF2K-S Amplifier | 12 | | | |
| 9 — Autostart / Services | 6 | | | |
| 10 — Web UI Display | 10 | | | |
| 11 — Error / Edge Cases | 8 | | | |
| **Total** | **98** | | | |

---

## Known Issues at Time of Testing

| Issue | Detail |
|---|---|
| Cold boot STM32 RAM loss | Sketch must be redeployed from App Lab after cold power cycle |
| KK1L display in web UI | Matrix routing/display of KK1L state not fully correct — under investigation |
| Inactive ports visible | Ports beyond port count shown dimmed rather than fully hidden |
| PA sequencing not implemented | RF2K-S standby/operate sequencing on band change not yet wired in |

---

*G0JKN ShackSwitch v2.0 Test Plan — 73 de G0JKN*

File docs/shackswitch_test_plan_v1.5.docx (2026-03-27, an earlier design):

G0JKN ShackSwitch

Build & Commissioning Test Plan

Configuration: Original 4-port build | Arduino Uno R4 WiFi | Nextion 3.5"

Version: 1.5 | March 2026 | Firmware v1.5

Nigel Fenton, G0JKN

# 1. Purpose

This test plan provides a structured, repeatable procedure for commissioning a G0JKN ShackSwitch from first power-on through to full RF verification. It covers the original 4-port build and all v1.5 firmware features including the TCP control protocol, UDP discovery beacon, band tracking, SO2R interlock, and REST API extensions.

Section 13 covers the KK1L 2x6 expansion build, to be completed once hardware arrives.

Each test section is independent. Work through them in order. Do not proceed to a later section if earlier tests have unresolved failures — the sections build on each other.

# 2. Equipment & Tools Required

Item | Detail / Specification
Multimeter | DC voltage and continuity / resistance ranges
12V DC power supply | Minimum 2A — bench PSU preferred for first power-on
USB cable | USB-A to USB-B for Arduino programming
PC with Arduino IDE | Version 2.x, R4 board package installed
PC or phone browser | On the same WiFi network as the ShackSwitch
Terminal / netcat | For TCP protocol tests on port 9008 (e.g. PuTTY raw mode, nc, or netcat)
Coax jumpers x5 | SO239 / PL259 — one for radio input, four for antenna outputs
Dummy load x1 (min) | 50 ohm, rated for your transceiver power level
Transceiver (low power) | Any HF radio — 5W is sufficient for RF path tests
SWR / power meter | Inline between transceiver and ShackSwitch
Small flat screwdriver | For checking connector screws and shield mounts

WARNING: Do not apply RF power during any electrical or relay test. RF path testing is Section 12 only, and only after all earlier tests have passed.

# 3. Safety Notes

- The ShackSwitch operates from 12V DC. Short circuits can cause fire, damage components, or destroy the Arduino. Always verify wiring before applying power.
- Disconnect 12V power before making any wiring changes or seating/removing the Arduino from the shield.
- RF power is only applied in Section 12. Keep power at 5W or below during initial RF testing.
- If at any point you smell burning or see smoke — disconnect power immediately. Do not re-apply until the fault is found and corrected.

# 4. Pre-Power Visual Inspection

Complete this section before connecting any power. The goal is to catch obvious wiring errors, shorts, and assembly problems before they can cause damage.

# | Action / Step | Expected Result | Pass | Fail | Notes / If Failed

4.1 Arduino & Shield
01 | Inspect the Arduino Uno R4 WiFi — confirm it is correctly seated in the shield headers with no bent pins. | All pins engaged. No pins folded under the board. | | | Re-seat if needed. Check for bent pins with a magnifier.
02 | Inspect relay module — confirm all relay coil connections to shield pins D2, D3, D4, D5 are secure. | Four relay connections present and firm. No bare wire strands touching adjacent pins. | | | Re-seat any loose connectors.
03 | Inspect the Nextion display connector — confirm TX1/RX1 and 5V/GND wiring to the display. | Four wires: TX1→RX, RX1→TX, 5V, GND. No crossed TX/RX wires. | | | TX/RX crossed is the most common Nextion wiring error — swap if display is blank.
04 | Visually inspect the PCB/veroboard for solder bridges, especially around relay driver transistors and shield header pins. | No visible solder bridges. Joints are clean and shiny. | | | Use solder wick to remove any bridges. Re-inspect.

4.2 Power Wiring
05 | Identify the 12V DC input connector. Confirm polarity markings match the power supply — positive centre (barrel jack) or XT60 correct orientation. | Polarity confirmed correct before any connection is made. | | | Do not proceed until polarity is confirmed. Reverse polarity will destroy components.
06 | Check the buck converter output wiring (12V in → 5V out → Arduino 5V pin). Measure the buck converter output with a multimeter before connecting to Arduino. | Buck converter output measures 4.9V–5.1V. | | | Adjust buck converter trimmer pot until output is within range.

4.3 RF Connectors
07 | Confirm all five SO239 connectors are present — one labelled RADIO IN and four labelled ANT 1–4. Check they are firmly mounted. | Five connectors present and mechanically secure. Centre pins present in all five. | | | Tighten retaining nuts if any are loose.
08 | Using multimeter in continuity mode — with 12V disconnected and no coax connected — check RADIO IN centre pin does NOT show continuity to any ANT 1–4 centre pin. | No continuity between RADIO IN and any antenna port (all relays open / grounded at rest). | | | Unexpected continuity indicates a relay or wiring fault. Investigate before powering on.

# 5. First Power-On — Electrical

Apply 12V power for the first time in this section. Have your finger near the power switch or connector so you can disconnect immediately if anything is wrong.

# | Action / Step | Expected Result | Pass | Fail | Notes / If Failed

5.1 Power Rails
01 | Connect 12V supply. Observe the board for 5 seconds before doing anything else. | No smoke, no burning smell, no components becoming hot to the touch. | | | If any of these occur — disconnect immediately and identify the fault before proceeding.
02 | Measure voltage at the Arduino 5V pin (or shield 5V rail) with multimeter. | Reads 4.9V–5.1V. | | | If low (<4.8V) — check buck converter output and wiring. If zero — check buck converter power input.
03 | Measure voltage across the 12V relay coil supply on the shield. | Reads 11.5V–12.5V. | | | If zero — check 12V input wiring to the shield.

5.2 Power LED
04 | Observe the blue power LED on the back panel. | Blue LED illuminated steady. | | | If not lit — check LED polarity and current limiting resistor.

5.3 Arduino Boot
05 | Observe the Arduino onboard LED matrix during boot (first 5 seconds after power-on). | LED matrix shows the boot pattern / relay state display. Matrix illuminates without error. | | | If matrix is blank — check 5V supply to Arduino. If garbled — re-upload firmware.

# 6. Nextion Display

The Nextion display must be running the correct HMI file. If the display is blank or showing factory default content, upload the ShackSwitch HMI file via microSD card before proceeding.

# | Action / Step | Expected Result | Pass | Fail | Notes / If Failed

6.1 Display Boot
01 | Power on and observe the Nextion display. | Display illuminates and shows Page 0 — four antenna port buttons (all grounded state), band display area, SO2R status, clock area, and IP address field. | | | If blank — check 5V and GND to display. If showing wrong content — re-upload HMI file.
02 | Observe the button states on the Nextion at boot. | All four antenna buttons show grounded (inactive) state. No button shows active/green. | | | If any button shows active — check syncButtonStates() call in setup(). Re-upload firmware.

6.2 Antenna Labels
03 | Observe text labels above each of the four antenna buttons. | Labels t3–t6 are visible above the buttons. Default names or previously saved names displayed. Text not clipped. | | | If labels blank — confirm HMI component names match firmware (t3, t4, t5, t6). If clipped — increase component width in Nextion editor.

6.3 Band Display
04 | Observe tBandA, tBandB and tSO2R components on the display at boot. | tBandA shows '---', tBandB shows '---'. tSO2R shows 'SO2R OK' in green text. | | | If tSO2R is black or blank — check updateNextionBandDisplay() is called in setup(). Check tSO2R component name in HMI.

6.4 NTP Clock
05 | Wait up to 60 seconds after WiFi connects (see Section 7). Observe the clock display on the Nextion. | Clock shows current UTC time and updates each minute. | | | If clock shows 00:00 — check WiFi connection (Section 7). NTP requires internet access.

# 7. WiFi & Network

The ShackSwitch must connect to your local WiFi network. If WiFi credentials are not yet configured, either edit loadConfig() and re-upload, or use the Nextion config page to enter credentials.

# | Action / Step | Expected Result | Pass | Fail | Notes / If Failed

7.1 WiFi Connection
01 | Power on and wait up to 60 seconds. Observe the IP address field on the Nextion display. | An IP address in your local network range is displayed (e.g. 10.0.0.x). Not 0.0.0.0. | | | If shows N O T C O N N E C T E D — check SSID and password in firmware or via Nextion config page.
02 | Note the IP address shown on the display. On a PC on the same network, open a browser and navigate to http://[IP address]. | The ShackSwitch web interface loads showing four antenna port cards with names and current state. | | | If page does not load — confirm device is on same network. Try pinging the IP address.

7.2 Status Endpoint
03 | In the browser, navigate to http://[IP address]/status | JSON response displayed: {"r1":0,"r2":0,"r3":0,"r4":0,"bandA":"---","bandB":"---","so2r":0} — all relays grounded at boot. | | | If page not found — check firmware web server routes. Re-upload firmware if needed.

7.3 Settings Page
04 | Navigate to http://[IP address]/settings | Settings page loads showing four antenna name input fields and Save buttons. | | | If page not found — check /settings route in firmware.

# 8. Relay Switching — Touchscreen

This section verifies that the Nextion touchscreen correctly activates each relay and grounds all others. Use a multimeter in continuity mode between the RADIO IN centre pin and each ANT port centre pin to verify switching.

Set your multimeter to continuity/beep mode. Probe RADIO IN centre pin with one lead. Touch each ANT port centre pin with the other lead as you work through the tests.

# | Action / Step | Expected Result | Pass | Fail | Notes / If Failed

8.1 Antenna 1
01 | Press the Antenna 1 button on the Nextion display. | Button 1 changes to active (green) state. Buttons 2, 3, 4 remain grounded. | | | If display does not update — check trigger1() in triggers.ino. Re-upload firmware.
02 | Check relay with multimeter — continuity between RADIO IN and ANT 1. | Continuity (beep) confirmed between RADIO IN and ANT 1. | | | If no continuity — check relay 1 wiring to D2. Check relay module power.
03 | Check remaining ports — probe RADIO IN to ANT 2, ANT 3, ANT 4. | No continuity on ANT 2, ANT 3, ANT 4 (all grounded). | | | If continuity on any non-selected port — relay not releasing. Check relay driver circuit.
04 | Check /status endpoint. | Returns {"r1":1,"r2":0,"r3":0,"r4":0} | | | If status does not match relay state — check relay state tracking in firmware.

8.2 Antenna 2
05 | Press the Antenna 2 button on the Nextion display. | Button 2 active. Buttons 1, 3, 4 grounded. Continuity RADIO IN↔ANT 2 only. /status returns {"r1":0,"r2":1,"r3":0,"r4":0} | | | Relay not releasing — check driver transistor for that relay.
06 | Verify ANT 1, 3, 4 show no continuity to RADIO IN. | No continuity on unselected ports. | | | Relay not releasing — check driver transistor for that relay.

8.3 Antenna 3
07 | Press the Antenna 3 button on the Nextion display. | Button 3 active. Continuity RADIO IN↔ANT 3 only. /status returns {"r1":0,"r2":0,"r3":1,"r4":0} | | | Check trigger3() and relay 3 wiring to D4.
08 | Verify ANT 1, 2, 4 show no continuity to RADIO IN. | No continuity on unselected ports. | | | Relay not releasing — check driver transistor for relay 3.

8.4 Antenna 4
09 | Press the Antenna 4 button on the Nextion display. | Button 4 active. Continuity RADIO IN↔ANT 4 only. /status returns {"r1":0,"r2":0,"r3":0,"r4":1} | | | Check trigger4() and relay 4 wiring to D5.
10 | Verify ANT 1, 2, 3 show no continuity to RADIO IN. | No continuity on unselected ports. | | | Relay not releasing — check driver transistor for relay 4.

8.5 Single-Antenna Enforcement
11 | With Antenna 2 active, rapidly press Antenna 4, then immediately press Antenna 1. | At no point are two antenna buttons shown as active simultaneously. Only the last pressed shows active. | | | If two relays ever close simultaneously — critical firmware fault. Do not use for RF until resolved.

# 9. Relay Switching — Web Interface

Repeat the relay switching tests using the web browser interface. This confirms the web server, button handler, and relay control all work correctly from a network command, independent of the touchscreen.

# | Action / Step | Expected Result | Pass | Fail | Notes / If Failed

9.1 Web Switch — Each Port
01 | In browser, click the Antenna 1 button on the web interface. | ANT 1 card highlighted green. ANT 2–4 shown grey. Multimeter confirms continuity RADIO IN↔ANT 1 only. | | | If click has no effect — check web server GET handler in firmware.
02 | Click Antenna 2 button in browser. | ANT 2 active. All others grounded. Continuity confirmed RADIO IN↔ANT 2. | | | Check web handler for relay 2.
03 | Click Antenna 3 button in browser. | ANT 3 active. All others grounded. Continuity confirmed RADIO IN↔ANT 3. | | | Check web handler for relay 3.
04 | Click Antenna 4 button in browser. | ANT 4 active. All others grounded. Continuity confirmed RADIO IN↔ANT 4. | | | Check web handler for relay 4.

9.2 Cross-Update — Web Follows Nextion
05 | With ANT 3 active via web, switch to ANT 1 using the Nextion touchscreen. Wait 6 seconds then check the web interface. | Web interface updates to show ANT 1 active within 6 seconds without page refresh. | | | If web does not update — check /status polling JavaScript in web page.
06 | With ANT 2 active via Nextion, switch to ANT 4 via the browser. Observe the Nextion. | Nextion button states update to show ANT 4 active. ANT 2 returns to grounded state. | | | If Nextion does not follow web commands — check syncButtonStates() call in controlRelay().

# 10. Antenna Name Storage (EEPROM)

# | Action / Step | Expected Result | Pass | Fail | Notes / If Failed

10.1 Rename via Web
01 | Navigate to http://[IP address]/settings. Enter a distinctive name in each of the four antenna name fields (e.g. '20m Inv V', '40m Dipole', '80m Loop', 'Spare'). Click Save. | Page redirects. Nextion display updates immediately to show new antenna names above each button. Web interface shows new names. | | | If Nextion does not update — check EEPROM write and Nextion label push in /rename handler.

10.2 Power Cycle Retention
02 | Remove 12V power. Wait 10 seconds. Re-apply power. Wait for boot to complete. | Nextion displays the same antenna names entered in the previous step — names survived the power cycle. | | | If names reset to defaults — check EEPROM read in loadConfig(). Check EEPROM magic byte / version check.
03 | Open web interface and navigate to /settings. Confirm names shown match those entered. | All four antenna names match — EEPROM consistent between Nextion and web. | | | If names differ — check that both read from the same config struct.

# 11. Band Tracking & SO2R Interlock

This section verifies the /setband REST endpoint, Nextion band display, and SO2R interlock logic. Tests are performed via browser URL — no radio or Node-RED connection required.

# | Action / Step | Expected Result | Pass | Fail | Notes / If Failed

11.1 REST /setband Endpoint
01 | In browser, navigate to http://[IP]/setband?input=1&band=40m | JSON response: {"input":1,"band":"40m","bandId":4,"so2r":false} | | | If 400 error — check input and band parameters. If band not recognised — check BANDS[] array in firmware.
02 | Observe the Nextion display immediately after step 01. | tBandA updates to show '40m'. tBandB still shows '---'. tSO2R shows 'SO2R OK' in green. | | | If tBandA not updated — check updateNextionBandDisplay() is called in /setband handler.
03 | In browser, navigate to http://[IP]/setband?input=2&band=20m | JSON response: {"input":2,"band":"20m","bandId":6,"so2r":false}. tBandB updates to '20m' on Nextion. | | | Check input=2 path in /setband handler.
04 | Navigate to http://[IP]/status | Response includes: "bandA":"40m","bandB":"20m","so2r":0 | | | If band fields missing — check /status JSON construction in firmware.
05 | Navigate to http://[IP]/setband?input=1&band=99m (unrecognised band name) | Returns HTTP 400 with {"error":"missing or unrecognised params"} | | | If accepts invalid band — check reverse lookup against BANDS[] array.

11.2 SO2R Status Display
06 | With tBandA=40m and tBandB=20m (different bands, not transmitting), observe tSO2R on Nextion. | tSO2R shows 'SO2R OK' in green. No inhibit active. | | | SO2R inhibit only fires when both ports are simultaneously transmitting. Check evaluateInterlock() logic.
07 | Reset Input 2 band: navigate to http://[IP]/setband?input=2&band=40m (same band as Input 1). | tBandB updates to '40m'. tSO2R remains 'SO2R OK' — same-band inhibit only fires during simultaneous TX. | | | If tSO2R shows INHIBIT without TX active — check evaluateInterlock() early return condition.

11.3 Band Reset
08 | Navigate to http://[IP]/setband?input=1&band=160m and http://[IP]/setband?input=2&band=80m. Confirm Nextion updates correctly for both. | tBandA shows '160m', tBandB shows '80m'. tSO2R shows 'SO2R OK'. | | | Check both input paths in /setband handler.

# 12. TCP Control Protocol (Port 9008)

This section tests the TCP control protocol using a terminal client. Use PuTTY (raw mode, port 9008), netcat, or similar. Commands are plain text lines prefixed C[seq]|

PuTTY setup: Connection type = Raw, Host = [IP address], Port = 9008. Disable local echo so you can see responses clearly.

# | Action / Step | Expected Result | Pass | Fail | Notes / If Failed

12.1 Connection & Greeting
01 | Open a TCP connection to [IP address] port 9008. | ShackSwitch responds immediately with: S0|device name=ShackSwitch ready=1 | | | If no response — check tcpServer.begin() in setup(). Check port 9008 is not firewalled.

12.2 Ping
02 | Send: C1|ping | Response: R1|00| | | | If no response — check processTcpCommand() for ping handler.

12.3 Antenna List
03 | Send: C2|antenna list | Four response lines, one per antenna, each containing id=, name=, txBandMask=, rxBandMask=. Final line: R2|00| | | | If names wrong — check myConfig.names[] array. Check EEPROM is loaded.

12.4 Band List
04 | Send: C3|band list | 11 response lines covering 160m through 6m, each with id=, name=, freqStart=, freqStop=. Final line: R3|00| | | | If wrong band count — check BAND_COUNT and BANDS[] array in firmware.

12.5 Port Get
05 | Send: C4|port get 1 | Response includes: id=1 auto=1 band=[current] rxant=0 txant=0 tx=0 inhibited=0 | | | If invalid port error — check portById() function.

12.6 Port Set
06 | Send: C5|port set 1 rxant=2 band=4 | Response: R5|00|ok followed by S0|port id=1 status line. Relay 2 activates. tBandA on Nextion updates to '40m'. | | | If relay does not switch — check port set handler, rxant path for portId==1.

12.7 Keepalive
07 | Leave TCP connection open for 30 seconds without sending any command. | ShackSwitch sends S0|ping after 30 seconds. | | | If no keepalive — check KEEPALIVE_INTERVAL and millis() timer in loop().

# 13. UDP Discovery Beacon

The ShackSwitch broadcasts a UDP discovery packet every 5 seconds on port 9008. This test uses a UDP listener on a PC on the same network.

On Linux/Mac: sudo tcpdump -i any udp port 9008. On Windows: Wireshark, filter: udp.port == 9008. Alternatively use a simple Python socket listener.

# | Action / Step | Expected Result | Pass | Fail | Notes / If Failed

13.1 Beacon Content
01 | With ShackSwitch powered and connected to WiFi, run a UDP listener on port 9008 on a PC on the same network. Wait up to 10 seconds. | UDP packet received containing: SS name=ShackSwitch serial=SS-001 version=1.5.0 ip=[IP] port=9008 ant=4 radio=2 | | | If no packet received — check discoveryUDP.beginPacket() and endPacket() in handleDiscoveryBeacon(). Check broadcast address calculation.
02 | Wait 10 seconds and confirm a second beacon is received. | Second beacon received within 5–6 seconds of the first. Beacon interval confirmed. | | | If interval is wrong — check BEACON_INTERVAL constant (should be 5000ms).

# 14. Factory Reset

Performing a factory reset will clear all stored antenna names and WiFi credentials. Have your WiFi details ready to re-enter afterwards.

# | Action / Step | Expected Result | Pass | Fail | Notes / If Failed

14.1 Reset Procedure
01 | On the Nextion, navigate to the config page. Press the Reset button once. | A warning message appears on the display prompting for confirmation. | | | If no warning appears — check the reset button trigger and warning dialog in HMI.
02 | Wait 6 seconds without pressing Reset again (allow timeout to expire). | Warning disappears. No reset performed. Antenna names and WiFi still intact. | | | Confirms the double-tap safety timeout is working.
03 | Press Reset button on config page, then immediately press Reset a second time within 5 seconds. | Arduino reboots. Nextion shows default antenna names (ANT 1–4). IP address field clears until WiFi reconnects. | | | If no reboot — check second press is received within timeout window. Check reset logic in firmware.
04 | Navigate to /settings in browser after reconnect. Confirm names have returned to defaults. | All four antenna names show factory defaults. | | | If names not cleared — check EEPROM factory reset write in firmware.

# 15. RF Path Test

Only perform this section after ALL previous sections have passed. Use maximum 5W for initial RF testing. Always connect a dummy load to any antenna port that does not have an antenna connected.

# | Action / Step | Expected Result | Pass | Fail | Notes / If Failed

15.1 Setup
01 | Connect transceiver TX output → SWR/power meter → RADIO IN on ShackSwitch. Connect 50 ohm dummy load to ANT 1. Connect dummy loads (or short coax with terminator) to ANT 2, 3, 4. | All five SO239 ports connected. No open ports. | | | Open ports during TX will cause high SWR and potential damage.

15.2 Each Port at Low Power
02 | Select ANT 1 on Nextion. Key transceiver at 5W for 1 second. Observe SWR meter. | SWR reads 1.0:1 to 1.5:1 (dummy load). Power meter shows approximately 5W forward, minimal reflected. | | | High SWR — check coax connector seating. Check relay contact condition.
03 | Select ANT 2. Key at 5W for 1 second. | SWR 1.0:1 to 1.5:1. Low reflected power. | | | High SWR on one port but not others — relay contact issue on that relay.
04 | Select ANT 3. Key at 5W for 1 second. | SWR 1.0:1 to 1.5:1. Low reflected power. | | | See above.
05 | Select ANT 4. Key at 5W for 1 second. | SWR 1.0:1 to 1.5:1. Low reflected power. | | | See above.

15.3 Isolation Check
06 | Select ANT 1. Connect an RF power meter to ANT 2 port. Key at 5W. | No significant power detected on ANT 2. Any reading should be >20dB below transmitted power. | | | If significant power on unselected port — relay not fully opening. Check grounding circuit.

# 16. KK1L 2×6 Expansion Build (Future — Hardware Ordered)

Complete this section once the KK1L board and MCP23017 GPIO expanders have been installed. All sections 4–15 should be re-run after the expansion build, in addition to the tests below.

Do not attempt this section until hardware is in hand and sections 4–15 have passed on the base build.
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

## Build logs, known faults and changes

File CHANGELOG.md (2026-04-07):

# ShackSwitch Changelog

---

## v2.0 — Arduino Uno Q (March–April 2026)

Complete platform migration from Arduino Uno R4 WiFi + Raspberry Pi 4 to Arduino Uno Q.

### Added — 5–6 Apr 2026

- **Voice TTS (Phase 1)** — Web Speech API spoken announcements on antenna selection, band changes, amp state changes, interlock blocks. Toggle via Voice Settings page (accessed from Settings).
- **Voice STT (Phase 2)** — Web Speech Recognition for hands-free control. Built-in commands: input/antenna selection, status readout, amplifier standby/operate, what band/antenna. Continuous listening, auto-restart on end.
- **Custom voice commands** — user-defined phrase→URL pairs, added/deleted via Voice Settings page, persisted in browser localStorage.
- **Voice Settings page** — dedicated page (no nav button, accessed from Settings) with voice toggle, built-in commands reference, and custom command manager.
- **Live FlexRadio VFO frequency display** — status cards show live frequency (e.g. "28.254 MHz") + antenna — band — active. Sourced from `smartsdr.radio_state` dict updated on every freq change.
- **`/radio/status` endpoint** — returns current slice freq/band as `{slices: {1: {freq, band}, 2: {...}}}`.
- **`/status` extended** — adds `bandA`, `freqA`, `bandB`, `freqB` fields from `smartsdr.radio_state`.
- **Double-announce debounce** — 1500ms guard prevents duplicate TTS when state changes rapidly.

### Bug fixes — 5–6 Apr 2026

- **Voice `error:aborted`** — `speechSynthesis.onend` fires before audio device releases; mic started too early → abort. Fix: 350ms `setTimeout` in `speak()` callback before `startRecognition()`.
- **`/status` deadlock** — inline `__import__("smartsdr")` in Flask response could block on Python import lock. Fix: replaced with `sys.modules.get("smartsdr")` safe lookup.

### Architecture changes
- Arduino Uno Q replaces both the R4 and the Pi in a single board
- Linux side (QRB2210) runs Flask REST API and SmartSDR band tracker in Docker
- STM32 side drives relay hardware via Bridge RPC
- Raspberry Pi 4 retired
- Arduino Uno R4 WiFi retired

### New features
- Flask REST API with full endpoint set
- Web UI — dark theme, 3-column switching matrix, status cards
- Settings page — port count selector, input labels, antenna naming
- Band/antenna pigeon hole assignment grid
- Interlock flash warning on web UI
- KK1L 2x6 relay board support in STM32 firmware (MCP23017 via I2C)
- DIP switch config reading (D6-D9)
- SO2R interlock enforced in Flask layer
- Config persistence via JSON file on host filesystem
- Systemd service for container autostart
- Port count configurable — 4, 6 or 8

### Known issues
- STM32 sketch loads into RAM — does not survive cold power cycle without App Lab reflash
- Cold boot autostart not yet fully solved

---

## v1.5 — Arduino Uno R4 WiFi (2024–2025)

### Features
- Arduino Uno R4 WiFi running firmware directly
- Nextion HMI displays (7" primary, 3.5" secondary)
- 4-relay shield on D2-D5
- SmartSDR band tracker on Raspberry Pi (smartsdr.py)
- Node-RED on Pi (partial — smartsdr.py handling band tracking)
- REST API via raw WiFiServer/WiFiClient
- SO2R interlock via evaluateInterlock()
- EasyNextionLibrary for display comms

---

## v1.0 — Initial build

- Single input, 4 antenna ports
- Basic relay switching
- Nextion display

---

*G0JKN ShackSwitch — 73 de G0JKN*

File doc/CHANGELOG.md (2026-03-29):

# Changelog
## G0JKN ShackSwitch — Open Source Shack Controller

All notable changes to this project are documented here.  
Format follows [Keep a Changelog](https://keepachangelog.com/en/1.0.0/) conventions.

---

## [1.5] - 2026-03-27

### Added
- **TCP control protocol** on port 9008 — line-based command/response protocol for AetherSDR and Node-RED integration
  - Commands: `ping`, `antenna list`, `band list`, `port get`, `port set`, `sub port all`, `interlock set`
  - Responses prefixed `R[seq]|code|body`, unsolicited events prefixed `S0|`
  - TCP keepalive — `S0|ping` sent every 30 seconds to connected client
- **UDP discovery beacon** — broadcasts device identity every 5 seconds on port 9008, enabling auto-discovery by AetherSDR and other network clients
- **Two input port model** — `portA` (Input 1 / Slice A) and `portB` (Input 2 / Slice B) structs track band, antenna selection, TX state and inhibit status independently
- **FlexRadio band tracking** — band definitions for 160m through 6m with frequency range lookup (`bandForFreq()`) and name reverse lookup for REST endpoint
- **SO2R interlock** (`evaluateInterlock()`) — inhibits Input 2 when both inputs are simultaneously transmitting on the same band or same antenna. Interlock state pushed to TCP client and Nextion
- **Nextion band display** — `tBandA`, `tBandB`, `tSO2R` components updated via `updateNextionBandDisplay()` after any relay change, band update or interlock evaluation
- **REST `/setband` endpoint** — `GET /setband?input=[1|2]&band=[name]` sets band for Input 1 or 2 by name string (e.g. `40m`), performs reverse lookup to band ID, calls `evaluateInterlock()` and updates Nextion. Returns JSON with input, band, bandId and so2r state
- **`/status` extended** — now returns `bandA`, `bandB` and `so2r` fields alongside relay states
- **Live web band panel** — band and SO2R status panel on main web page now updates automatically from the existing 5-second `/status` poll. No additional HTTP requests. SO2R OK shown in green, INHIBIT in orange
- **SmartSDR Python integration service** (`nodered/smartsdr.py`) — runs on a Raspberry Pi, connects to FlexRadio SmartSDR on TCP port 4992, subscribes to slice frequency events, maps frequency to band name, calls `/setband` on band change. Only fires on actual band change, not every VFO movement
- **systemd service file** (`nodered/smartsdr-tracker.service`) — installs `smartsdr.py` as a persistent system service that starts automatically on Pi boot and restarts on failure

### Changed
- `showMainPage()` — band and SO2R panel now uses span IDs (`bandA`, `bandB`, `so2r`) targeted by the JavaScript polling loop. CSS classes `so2rok` (green) and `so2rwarn` (orange) added
- Firmware fully commented throughout — all structs, functions and web server route handlers have doc-style block comments
- `triggers.ino` fully commented — trigger assignment table in file header, each function has purpose and behaviour documented
- Version string updated to 1.5.0

### Architecture
- Two input port architecture clarified — Input 1 and Input 2 are the correct terms. Current setup: Input 1 = FlexRadio Slice A, Input 2 = FlexRadio Slice B. Supports both single-radio dual-slice and two-radio configurations without firmware changes
- FlexRadio multi-RX noted — TX slice is the safety-critical path for antenna switching. RX-only slice band changes do not drive relay selection. Multi-RX within a single slice is a known future consideration
- `port set` handler notes that Port B relay bank requires KK1L expansion board (not yet built)

---

## [Hardware v2] - 2026-03-22

### Shield PCB — Version 2

#### Added
- 8x SMD transistor arrays replacing through-hole components — doubles drive capacity for future 8-relay expansion
- Additional 4-way screw terminal connectors for easy daisy-chaining to secondary relay/switch PCBs
- I2C expansion header (SDA, SCL, VCC, GND) — ready for MCP23017 GPIO expander integration
- Gerber files exported from Fusion 360 and added to `hardware/gerbers/shackswitch-shield-v2.zip`

#### Changed
- Migrated transistor drivers from through-hole to SMD for significant space saving
- Improved connector layout for cleaner wiring to external relay boards

#### Notes
- Shield v2 is a drop-in replacement for v1 — Arduino pin assignments unchanged
- I2C header is passive (no I2C devices populated) — ready for v1.5 firmware expansion
- KK1L 2x6 relay board ordered — https://kk1l.com/store/2x6-relay-board/

---

## [1.4] - 2026-03-22

### Added
- Antenna name labels on Nextion display (components t3–t6 above each dual-state button)
- `syncAntennaNames()` — pushes all four antenna names from EEPROM to display on boot
- Live JSON status endpoint (`/status`) returning `{"r1":0,"r2":1,"r3":0,"r4":0}`
- JavaScript polling on web page — updates card state and button colour every 5 seconds without page refresh
- Active antenna card highlighted in green on web page

### Changed
- `connectToWiFi()` — replaced blind `delay(5000)` with a proper 15-second connection wait loop
- Web page cards now have unique IDs for JavaScript targeting
- Web server request handler order updated

### Fixed
- IP address no longer wiped by `page 0` command on startup
- Antenna names not displayed on Nextion after migration to dual-state buttons
- Web page rename handler now correctly targets Nextion label components

---

## [1.3] - 2026-03

### Added
- Dual-state image buttons (b1–b4) on Nextion Page 0
- `syncButtonStates()` — single source of truth for relay state to Nextion buttons

### Changed
- `controlRelay()` — replaced `.bco` colour writes with `syncButtonStates()` call
- Button state controlled via `.val` (0=grounded, 1=active) instead of `.bco` colour

### Fixed
- Button state sync broken after renumbering
- `trigger11()` and `trigger12()` conflict resolved

---

## [1.2] - 2026-01

### Added
- NTP time synchronisation on startup via `pool.ntp.org`
- RTC update every 25 seconds, midnight re-sync
- Station monitor page (Page 3) — WiFi RSSI, signal quality bar and IP address
- Factory reset (`trigger8()`) with double-tap safety confirmation and 5-second timeout
- WiFi config page (Page 2) — network scan, selection and password entry
- Non-blocking WiFi reconnect in main loop (retries every 30 seconds)

### Changed
- WiFi credentials moved to `RelayConfig` struct and stored in EEPROM
- `connectToWiFi()` separated into its own function

---

## [1.1] - 2025-12

### Added
- WiFi web server on port 80
- Main web page with four antenna ports, names, state and toggle links
- Web settings page (`/settings`) for renaming antenna ports
- Antenna names stored in EEPROM and restored on boot
- `RelayConfig` struct with EEPROM magic number version check

---

## [1.0] - 2025-11

### Added
- Initial release
- 4-relay antenna switching on Arduino Uno R4 WiFi (pins D2–D5)
- Nextion 3.5" touchscreen control via EasyNextionLibrary on Serial1
- `trigger1()` – `trigger4()` touch event handlers
- Single-antenna enforcement
- Arduino LED Matrix display — active relay number or ground symbol
- Basic WiFi connection on startup
- 3D printed enclosure (Fusion 360)
- Custom Arduino shield with relay drivers, transistors and flyback diodes
- SO239 RF connectors — 1 input, 4 antenna outputs

---

## Planned / In Development

### Near Term
- KK1L 2x6 relay board build — hardware ordered. Requires ULN2803 driver stage for 12V relay coils from MCP23017 outputs
- MCP23017 #1 (0x20) firmware — drives KK1L relay matrix (GPA1-6 = Input 1 ports 1-6, GPB1-6 = Input 2 ports 1-6)
- MCP23017 #2 (0x21) firmware — boot-time hardware config detection (board type, input count, radio type, PA present). No reflash required when changing hardware configuration
- Test plan update for v1.5 features and KK1L expansion build
- Node-RED flow for SmartSDR integration — complements existing Python service, adds visual flow management
- AetherSDR issue #179 — native antenna switch panel in Qt6 client

### Roadmap
- MCP23017 #3 (0x22) — shack switching (amps, lights, PSU sequencing)
- PA protection — TX slice tracking feeds into sequencer. Must not fire PA on wrong antenna
- Multi-RX slice handling — FlexRadio can present up to 4 RX streams, 2 per slice, TX on one only. RX-only paths do not drive antenna switching
- BCD band decoder input/output
- Radioberry I2C interface — forward/reverse power and temperature monitoring
- AetherSDR SO2R aware switching — slice TX/RX state drives Input 1/2 routing automatically
- Unified PCB (v3) — single board incorporating Arduino R4 WiFi design, two MCP23017 expanders, 16x SMD transistor drivers, all connectors

---

*Maintained by G0JKN — 73 de G0JKN* 📻

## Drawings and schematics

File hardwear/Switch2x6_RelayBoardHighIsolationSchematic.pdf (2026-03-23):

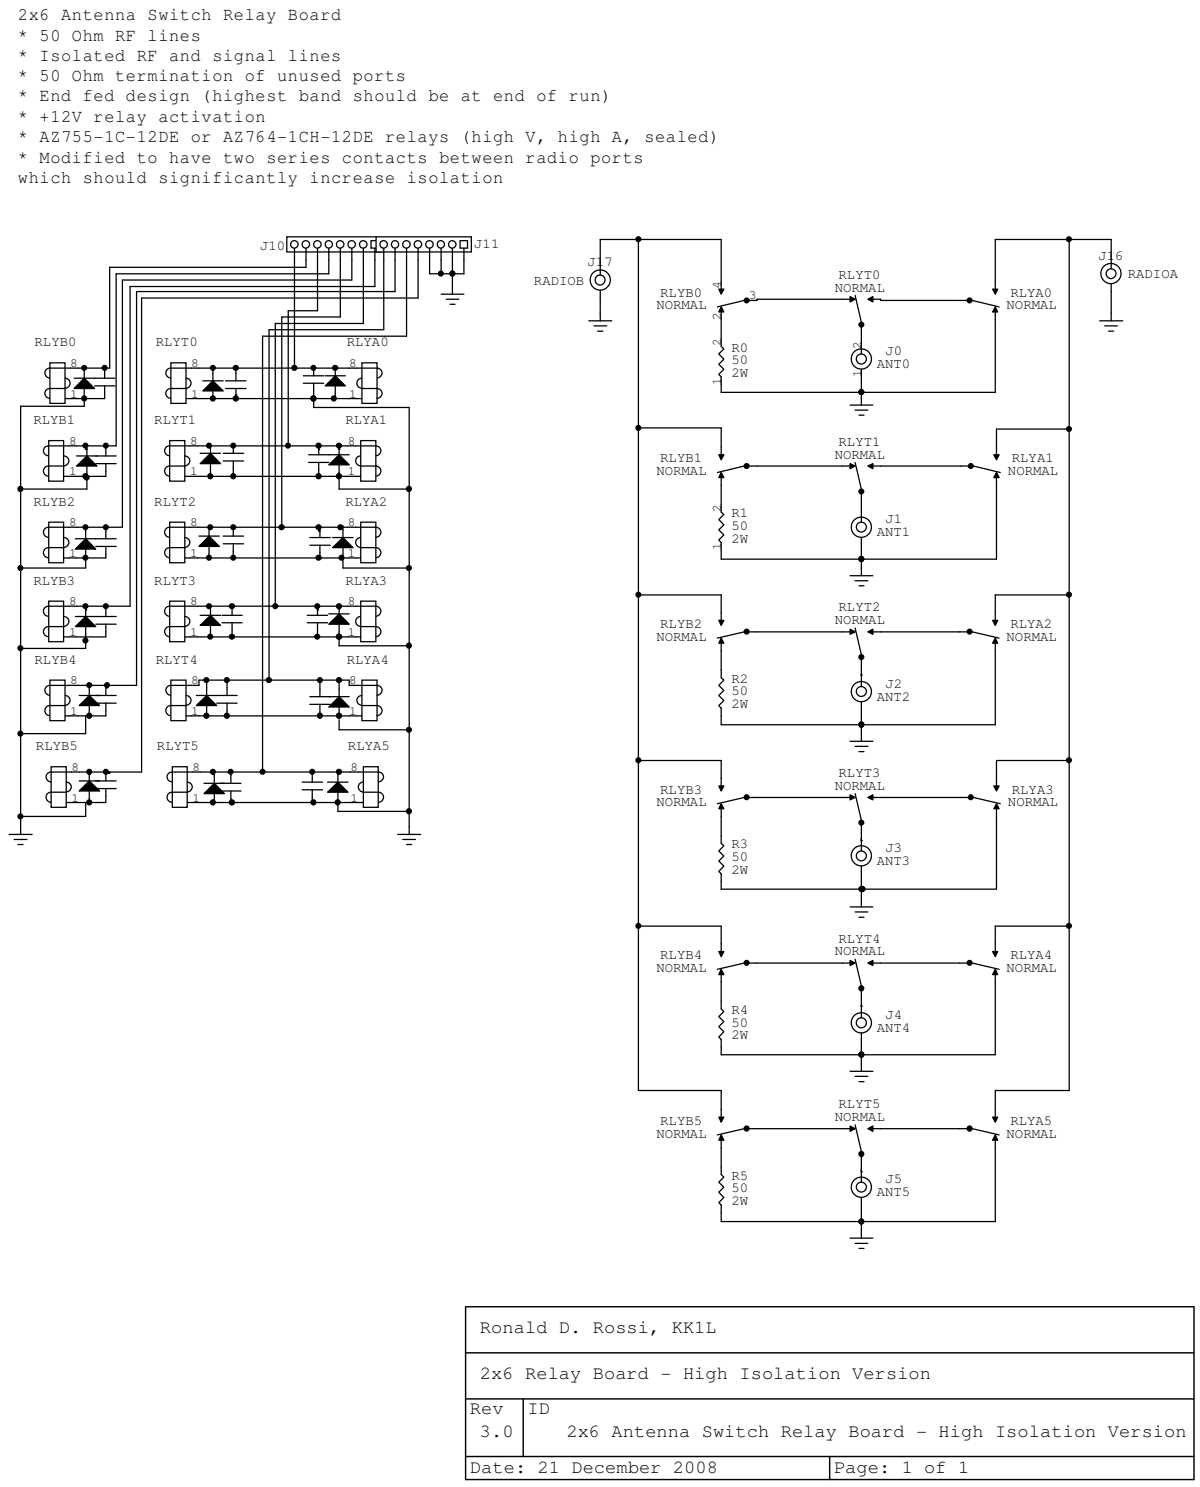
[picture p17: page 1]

2x6 Antenna Switch Relay Board
* 50 Ohm RF lines
* Isolated RF and signal lines
* 50 Ohm termination of unused ports
* End fed design (highest band should be at end of run)
* +12V relay activation
* AZ755-1C-12DE or AZ764-1CH-12DE relays (high V, high A, sealed)
* Modified to have two series contacts between radio ports
which should significantly increase isolation

2x6 Relay Board - High Isolation Version

Rev 3.0 | ID 2x6 Antenna Switch Relay Board - High Isolation Version

Date: 21 December 2008 | Page: 1 of 1

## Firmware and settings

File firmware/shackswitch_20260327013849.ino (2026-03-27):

/* 
 * VERSION 1.5 - G0JKN Antenna Switcher 
 * Integrated State Sync, Background WiFi Manager, and Factory Reset
 * Updated for dual-state image buttons (b1-b4) on Page 0
 * Antenna name labels: t3=b1, t4=b2, t5=b3, t6=b4
 * v1.5: Added TCP control protocol (port 9008), UDP discovery beacon,
 *       Flex-6700 band tracking, and SO2R interlock logic
 */

#include "WiFiS3.h"
#include "EasyNextionLibrary.h"
#include "ArduinoGraphics.h"
#include "Arduino_LED_Matrix.h"
#include "RTC.h"
#include <EEPROM.h>
#include <NTPClient.h>
#include <WiFiUdp.h>

// ── Config struct ─────────────────────────────────────────────
struct RelayConfig { 
  char names[4][26]; 
  char wifiSSID[33];      
  char wifiPass[64];
  uint32_t configMagic;   
};

RelayConfig myConfig;
const uint32_t CONFIG_VERSION = 0xDEADBEEE;

// ── Hardware ──────────────────────────────────────────────────
const int relayPins[] = {2, 3, 4, 5};
const int RELAY_COUNT = 4;

// Ground symbol for 12x8 LED Matrix
const uint32_t ground_hex[] = {
  0x4004004,
  0x7fc0001,
  0xf00000e0,
  66
};

ArduinoLEDMatrix matrix;
EasyNex myNex(Serial1);
WiFiUDP ntpUDP;
NTPClient timeClient(ntpUDP, "pool.ntp.org", -14400, 60000);

// ── Nextion colours ───────────────────────────────────────────
const uint32_t NEXTION_GREEN  = 1024;
const uint32_t NEXTION_RED    = 63488;
const uint32_t NEXTION_ORANGE = 65504;  // SO2R inhibit warning

// ── Web server (port 80) ──────────────────────────────────────
WiFiServer server(80);

// ── TCP control server (port 9008) ───────────────────────────
WiFiServer tcpServer(9008);
WiFiClient tcpClient;

// ── UDP discovery beacon ──────────────────────────────────────
WiFiUDP discoveryUDP;
const uint16_t DISCOVERY_PORT = 9008;

// ── Device identity ───────────────────────────────────────────
const char* DEVICE_NAME    = "ShackSwitch";
const char* DEVICE_SERIAL  = "SS-001";
const char* DEVICE_VERSION = "1.5.0";

// ── Band definitions ──────────────────────────────────────────
struct BandInfo {
  int    id;
  const char* name;
  double freqStartMhz;
  double freqStopMhz;
};

const BandInfo BANDS[] = {
  { 1, "160m",  1.800,  2.000 },
  { 2,  "80m",  3.500,  4.000 },
  { 3,  "60m",  5.330,  5.407 },  // covers all channels + WRC-15
  { 4,  "40m",  7.000,  7.300 },
  { 5,  "30m", 10.100, 10.160 },  // extended
  { 6,  "20m", 14.000, 14.350 },
  { 7,  "17m", 18.068, 18.168 },
  { 8,  "15m", 21.000, 21.450 },
  { 9,  "12m", 24.890, 24.990 },
  {10,  "10m", 28.000, 29.700 },
  {11,   "6m", 50.000, 54.000 },
};
const int BAND_COUNT = sizeof(BANDS) / sizeof(BANDS[0]);

// ── Port state (Radio A = port 1, Radio B = port 2) ──────────
struct PortState {
  int  portId;
  bool autoMode;
  int  band;          // current band id (0 = unknown)
  int  rxAntenna;     // 1-based, 0 = none
  int  txAntenna;
  bool transmitting;
  bool inhibited;
  char inhibitReason[64];
};

PortState portA = {1, true, 0, 0, 0, false, false, ""};
PortState portB = {2, true, 0, 0, 0, false, false, ""};

// ── TCP command state ─────────────────────────────────────────
char tcpLineBuffer[256];
int  tcpLinePos = 0;

// ── Timers ────────────────────────────────────────────────────
unsigned long lastRSSIUpdate    = 0;
unsigned long lastClockUpdate   = 0;
unsigned long lastWiFiCheck     = 0;
unsigned long lastBeacon        = 0;
unsigned long lastKeepalive     = 0;
unsigned long resetTimer        = 0;

const unsigned long BEACON_INTERVAL    = 5000;
const unsigned long KEEPALIVE_INTERVAL = 30000;

// ── UI State ──────────────────────────────────────────────────
int  currentRSSI      = 0;
bool onMonitorPage    = false;
bool onConfigPage     = false;
bool resetConfirmed   = false;
int  currentActiveRelay = 0;

// ═════════════════════════════════════════════════════════════
//  BAND HELPERS
// ═════════════════════════════════════════════════════════════
int bandForFreq(double freqMhz) {
  for (int i = 0; i < BAND_COUNT; i++) {
    if (freqMhz >= BANDS[i].freqStartMhz && freqMhz <= BANDS[i].freqStopMhz)
      return BANDS[i].id;
  }
  return 0;
}

const char* bandName(int bandId) {
  for (int i = 0; i < BAND_COUNT; i++) {
    if (BANDS[i].id == bandId) return BANDS[i].name;
  }
  return "---";
}

// ═════════════════════════════════════════════════════════════
//  RELAY & DISPLAY
// ═════════════════════════════════════════════════════════════
void updateMatrix(int num) {
  matrix.beginDraw();
  matrix.stroke(0xFFFFFFFF);
  matrix.textFont(Font_5x7);
  matrix.beginText(0, 1, 0xFFFFFF);
  if(num > 0) { matrix.print("R"); matrix.print(num); } 
  else { matrix.print("GN "); }
  matrix.endText();
  matrix.endDraw();
}

void displayGroundSymbol() {
  matrix.loadFrame(ground_hex);
}

void syncButtonStates() {
  for (int i = 0; i < RELAY_COUNT; i++) {
    int val = (digitalRead(relayPins[i]) == HIGH) ? 1 : 0;
    myNex.writeNum("b" + String(i + 1) + ".val", val);
  }
}

void syncAntennaNames() {
  for (int i = 0; i < RELAY_COUNT; i++) {
    myNex.writeStr("t" + String(i + 3) + ".txt", myConfig.names[i]);
  }
}

void updateAntennaStatus() {
  bool anyActive  = false;
  int  activeIndex = -1;
  for (int i = 0; i < RELAY_COUNT; i++) {
    if (digitalRead(relayPins[i]) == HIGH) { anyActive = true; activeIndex = i; break; }
  }
  if (anyActive) {
    myNex.writeStr("tState.txt", "ANT Active");
    myNex.writeStr("tState.pco", "63488");
    updateMatrix(activeIndex + 1);
  } else {
    myNex.writeStr("tState.txt", "ANT Grounded");
    myNex.writeStr("tState.pco", "1024");
    updateMatrix(0);
    displayGroundSymbol();
  }
}

/*
 * FUNCTION: controlRelay
 * ----------------------
 * Sets a relay HIGH or LOW. Only one relay active at a time.
 * Syncs Nextion dual-state buttons and LED matrix.
 * Called by: web server, TCP protocol, SO2R band-change logic.
 */
void controlRelay(int targetIndex, bool state) {
  int idx = targetIndex - 1;
  if (idx < 0 || idx >= RELAY_COUNT) return;

  if (state == HIGH) {
    currentActiveRelay = targetIndex;
    for (int i = 0; i < RELAY_COUNT; i++) {
      digitalWrite(relayPins[i], (i == idx) ? HIGH : LOW);
    }
  } else {
    digitalWrite(relayPins[idx], LOW);
    if (currentActiveRelay == targetIndex) currentActiveRelay = 0;
  }
  syncButtonStates();
  updateAntennaStatus();
  updateNextionBandDisplay();
}

/*
 * FUNCTION: updateNextionBandDisplay
 * -----------------------------------
 * Pushes current band and SO2R status to Nextion.
 * Uses tBandA, tBandB, tSO2R text components.
 * Add these components to your Nextion HMI page 0.
 */
void updateNextionBandDisplay() {
  myNex.writeStr("tBandA.txt", bandName(portA.band));
  myNex.writeStr("tBandB.txt", bandName(portB.band));

  if (portA.inhibited || portB.inhibited) {
    myNex.writeStr("tSO2R.txt", "INHIBIT");
    myNex.writeNum("tSO2R.pco", NEXTION_ORANGE);
  } else {
    myNex.writeStr("tSO2R.txt", "SO2R OK");
    myNex.writeNum("tSO2R.pco", NEXTION_GREEN);
  }
}

// ═════════════════════════════════════════════════════════════
//  SO2R INTERLOCK
// ═════════════════════════════════════════════════════════════
void evaluateInterlock() {
  portA.inhibited = false;
  portB.inhibited = false;
  portA.inhibitReason[0] = '\0';
  portB.inhibitReason[0] = '\0';

  if (!portA.transmitting || !portB.transmitting) return;

  // Same antenna conflict
  if (portA.txAntenna != 0 && portA.txAntenna == portB.txAntenna) {
    portB.inhibited = true;
    snprintf(portB.inhibitReason, sizeof(portB.inhibitReason),
      "same antenna as Radio A (ant %d)", portB.txAntenna);
    Serial.println(F("[INTERLOCK] Same antenna — Radio B inhibited"));
    return;
  }

  // Same band conflict
  if (portA.band != 0 && portA.band == portB.band) {
    portB.inhibited = true;
    snprintf(portB.inhibitReason, sizeof(portB.inhibitReason),
      "same band as Radio A (%s)", bandName(portB.band));
    Serial.println(F("[INTERLOCK] Same band — Radio B inhibited"));
  }
}

// ═════════════════════════════════════════════════════════════
//  TCP PROTOCOL
// ═════════════════════════════════════════════════════════════
void sendTcpResponse(int seq, int code, const char* body) {
  if (!tcpClient || !tcpClient.connected()) return;
  char line[256];
  snprintf(line, sizeof(line), "R%d|%02X|%s", seq, code, body);
  tcpClient.println(line);
}

void pushPortStatus(PortState* p) {
  if (!tcpClient || !tcpClient.connected()) return;
  char line[192];
  snprintf(line, sizeof(line),
    "S0|port id=%d auto=%d band=%d rxant=%d txant=%d tx=%d inhibited=%d reason=%s",
    p->portId, p->autoMode ? 1 : 0, p->band,
    p->rxAntenna, p->txAntenna,
    p->transmitting ? 1 : 0,
    p->inhibited ? 1 : 0,
    p->inhibitReason
  );
  tcpClient.println(line);
}

PortState* portById(int id) {
  if (id == 1) return &portA;
  if (id == 2) return &portB;
  return nullptr;
}

// Simple key=value parser — finds value for a given key in a string
// e.g. parseParam("rxant=3 txant=3", "rxant") returns 3
int parseParam(const char* str, const char* key) {
  char* found = strstr(str, key);
  if (!found) return -1;
  found += strlen(key);
  if (*found == '=') found++;
  return atoi(found);
}

void processTcpCommand(const char* line) {
  if (line[0] != 'C') return;

  int seq = 0;
  int i = 1;
  while (line[i] && line[i] != '|') { seq = seq * 10 + (line[i] - '0'); i++; }
  if (line[i] != '|') return;
  const char* cmd = &line[i + 1];

  Serial.print(F("[TCP] seq=")); Serial.print(seq);
  Serial.print(F(" cmd=")); Serial.println(cmd);

  if (strncmp(cmd, "ping", 4) == 0) {
    sendTcpResponse(seq, 0, "");

  } else if (strncmp(cmd, "antenna list", 12) == 0) {
    for (int a = 0; a < RELAY_COUNT; a++) {
      char body[96];
      snprintf(body, sizeof(body),
        "id=%d name=%s txBandMask=FFFF rxBandMask=FFFF rxOnly=0", a+1, myConfig.names[a]);
      sendTcpResponse(seq, 0, body);
    }
    sendTcpResponse(seq, 0, "");

  } else if (strncmp(cmd, "band list", 9) == 0) {
    for (int b = 0; b < BAND_COUNT; b++) {
      char body[64];
      snprintf(body, sizeof(body), "id=%d name=%s freqStart=%.3f freqStop=%.3f",
        BANDS[b].id, BANDS[b].name, BANDS[b].freqStartMhz, BANDS[b].freqStopMhz);
      sendTcpResponse(seq, 0, body);
    }
    sendTcpResponse(seq, 0, "");

  } else if (strncmp(cmd, "port get ", 9) == 0) {
    int portId = atoi(&cmd[9]);
    PortState* p = portById(portId);
    if (!p) { sendTcpResponse(seq, 0x404, "invalid port"); return; }
    char body[128];
    snprintf(body, sizeof(body),
      "id=%d auto=%d band=%d rxant=%d txant=%d tx=%d inhibited=%d reason=%s",
      p->portId, p->autoMode?1:0, p->band, p->rxAntenna, p->txAntenna,
      p->transmitting?1:0, p->inhibited?1:0, p->inhibitReason);
    sendTcpResponse(seq, 0, body);

  } else if (strncmp(cmd, "port set ", 9) == 0) {
    // Format: "port set <portId> rxant=<n> txant=<n> auto=<0|1> band=<n>"
    const char* params = &cmd[9];
    int portId  = atoi(params);
    int rxAnt   = parseParam(params, "rxant");
    int txAnt   = parseParam(params, "txant");
    int autoMode = parseParam(params, "auto");
    int band    = parseParam(params, "band");

    PortState* p = portById(portId);
    if (!p) { sendTcpResponse(seq, 0x404, "invalid port"); return; }

    if (autoMode >= 0) p->autoMode = (autoMode == 1);
    if (band > 0)     p->band = band;

    // Apply antenna selection — only port A drives relays on V1 shield
    // Port B support requires V2/V3 shield (second relay bank)
    if (rxAnt > 0 && rxAnt <= RELAY_COUNT) {
      p->rxAntenna = rxAnt;
      if (portId == 1) {
        // Radio A controls the relay bank
        controlRelay(rxAnt, HIGH);
        Serial.print(F("[RELAY] Port A → Antenna ")); Serial.println(rxAnt);
      }
      // TODO: Port B relay bank when V2/V3 shield fitted
    }
    if (txAnt > 0 && txAnt <= RELAY_COUNT) p->txAntenna = txAnt;

    evaluateInterlock();
    sendTcpResponse(seq, 0, "ok");
    pushPortStatus(p);
    updateNextionBandDisplay();

  } else if (strncmp(cmd, "sub port all", 12) == 0) {
    sendTcpResponse(seq, 0, "subscribed");

  } else if (strncmp(cmd, "interlock set ", 14) == 0) {
    const char* params = &cmd[14];
    bool tx   = false;
    int  band = parseParam(params, "band");

    if (strstr(params, "radioA=")) {
      tx = parseParam(params, "radioA") == 1;
      portA.transmitting = tx;
      if (band > 0) portA.band = band;
    }
    if (strstr(params, "radioB=")) {
      tx = parseParam(params, "radioB") == 1;
      portB.transmitting = tx;
      if (band > 0) portB.band = band;
    }

    evaluateInterlock();
    sendTcpResponse(seq, 0, "ok");
    pushPortStatus(&portA);
    pushPortStatus(&portB);
    updateNextionBandDisplay();

  } else {
    sendTcpResponse(seq, 0x500, "unknown command");
  }
}

void handleTCP() {
  // Accept new client
  if (!tcpClient || !tcpClient.connected()) {
    tcpClient = tcpServer.available();
    if (tcpClient) {
      Serial.println(F("[TCP] Client connected"));
      tcpLinePos = 0;
      tcpClient.println(F("S0|device name=ShackSwitch ready=1"));
    }
    return;
  }

  // Read lines
  while (tcpClient.available()) {
    char c = tcpClient.read();
    if (c == '\n') {
      tcpLineBuffer[tcpLinePos] = '\0';
      if (tcpLinePos > 0 && tcpLineBuffer[tcpLinePos-1] == '\r')
        tcpLineBuffer[--tcpLinePos] = '\0';
      if (tcpLinePos > 0) processTcpCommand(tcpLineBuffer);
      tcpLinePos = 0;
    } else if (tcpLinePos < (int)sizeof(tcpLineBuffer) - 1) {
      tcpLineBuffer[tcpLinePos++] = c;
    }
  }
}

// ═════════════════════════════════════════════════════════════
//  UDP DISCOVERY BEACON
// ═════════════════════════════════════════════════════════════
void handleDiscoveryBeacon() {
  unsigned long now = millis();
  if (now - lastBeacon < BEACON_INTERVAL) return;
  lastBeacon = now;

  if (WiFi.status() != WL_CONNECTED) return;

  char beacon[160];
  snprintf(beacon, sizeof(beacon),
    "SS name=%s serial=%s version=%s ip=%s port=9008 ant=%d radio=2",
    DEVICE_NAME, DEVICE_SERIAL, DEVICE_VERSION,
    WiFi.localIP().toString().c_str(),
    RELAY_COUNT
  );

  IPAddress broadcast = WiFi.localIP();
  broadcast[3] = 255;
  discoveryUDP.beginPacket(broadcast, DISCOVERY_PORT);
  discoveryUDP.write((uint8_t*)beacon, strlen(beacon));
  discoveryUDP.endPacket();
}

// ═════════════════════════════════════════════════════════════
//  WIFI & CONFIG
// ═════════════════════════════════════════════════════════════
void loadConfig() {
  EEPROM.get(0, myConfig);
  if (myConfig.configMagic != CONFIG_VERSION) {
    Serial.println("EEPROM Empty. Loading Defaults...");
    for (int i = 0; i < RELAY_COUNT; i++) {
      String dName = "Relay " + String(i + 1);
      dName.toCharArray(myConfig.names[i], 26);
    }
    strncpy(myConfig.wifiSSID, "tinkerbell", 33);
    strncpy(myConfig.wifiPass, "disneybell", 64);
    myConfig.configMagic = CONFIG_VERSION;
    EEPROM.put(0, myConfig);
  }
}

void connectToWiFi() {
  WiFi.begin(myConfig.wifiSSID, myConfig.wifiPass);
  Serial.print("Connecting to: "); Serial.println(myConfig.wifiSSID);
  unsigned long startAttempt = millis();
  while (WiFi.status() != WL_CONNECTED && millis() - startAttempt < 15000) {
    delay(500); Serial.print(".");
  }
  if (WiFi.status() == WL_CONNECTED) {
    delay(500);
    Serial.println("\nWiFi Connected! IP: " + WiFi.localIP().toString());
  } else {
    Serial.println("\nWiFi connection timed out.");
  }
}

void syncTime() {
  timeClient.begin();
  if(timeClient.update()) {
    RTCTime currentTime(timeClient.getEpochTime());
    RTC.setTime(currentTime);
    Serial.println("NTP Synced.");
  }
}

void updateStationMonitor() {
  if (WiFi.status() == WL_CONNECTED) {
    currentRSSI = WiFi.RSSI();
    int signalQuality = map(currentRSSI, -100, -40, 0, 100);
    signalQuality = constrain(signalQuality, 0, 100);
    myNex.writeStr("tRSSI.txt", String(currentRSSI) + " dBm");
    myNex.writeNum("nSignal.val", signalQuality);
    myNex.writeStr("b0.txt", WiFi.localIP().toString());
    if (currentRSSI > -60)      myNex.writeNum("nSignal.pco", NEXTION_GREEN);
    else if (currentRSSI > -80) myNex.writeNum("nSignal.pco", NEXTION_RED);
  }
}
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
void loop() {
  myNex.NextionListen();

  // ── TCP control protocol ──────────────────────────────────
  handleTCP();

  // ── UDP discovery beacon ──────────────────────────────────
  handleDiscoveryBeacon();

  // ── TCP keepalive ─────────────────────────────────────────
  if (tcpClient && tcpClient.connected()) {
    if (millis() - lastKeepalive > KEEPALIVE_INTERVAL) {
      lastKeepalive = millis();
      tcpClient.println(F("S0|ping"));
    }
  }

  // ── RSSI update ───────────────────────────────────────────
  if (millis() - lastRSSIUpdate > 10000) {
    if (onMonitorPage || WiFi.status() == WL_CONNECTED) updateStationMonitor();
    lastRSSIUpdate = millis();
  }

  // ── Reset safety timeout ──────────────────────────────────
  if (resetConfirmed && (millis() - resetTimer > 5000)) {
    resetConfirmed = false;
    myNex.writeStr("tStatus.txt", "Reset Canceled");
  }

  // ── WiFi reconnect ────────────────────────────────────────
  if (WiFi.status() != WL_CONNECTED && !onConfigPage) {
    if (millis() - lastWiFiCheck > 30000) {
      WiFi.begin(myConfig.wifiSSID, myConfig.wifiPass);
      lastWiFiCheck = millis();
    }
    myNex.writeStr("t1.txt", "N O T   C O N N E C T E D");
  }

  // ── RTC clock update ──────────────────────────────────────
  if (millis() - lastClockUpdate > 25000) {
    RTCTime now;
    if (RTC.getTime(now)) {
      char buf[16];
      sprintf(buf, "%02d:%02d", (int)now.getHour(), (int)now.getMinutes());
      myNex.writeStr("tClock.txt", buf);
      if (now.getHour() == 0 && now.getMinutes() == 0 && now.getSeconds() < 10) syncTime();
    }
    lastClockUpdate = millis();
  }

  // ── Web server ────────────────────────────────────────────
  WiFiClient webClient = server.available();
  if (webClient) {
    String request = webClient.readStringUntil('\r');
    webClient.flush();

    if (request.indexOf("GET /status") != -1) {
      String json = "{";
      for (int i = 0; i < RELAY_COUNT; i++) {
        json += "\"r" + String(i+1) + "\":" + String(digitalRead(relayPins[i]));
        if (i < RELAY_COUNT - 1) json += ",";
      }
      json += ",\"bandA\":\"" + String(bandName(portA.band)) + "\"";
      json += ",\"bandB\":\"" + String(bandName(portB.band)) + "\"";
      json += ",\"so2r\":" + String((portA.inhibited || portB.inhibited) ? "1" : "0");
      json += "}";
      webClient.println("HTTP/1.1 200 OK\r\nContent-Type: application/json\r\nAccess-Control-Allow-Origin: *\r\n\r\n" + json);
    }
    else if (request.indexOf("GET /settings") != -1) { showSettingsPage(webClient); }
    else if (request.indexOf("GET /rename") != -1) {
      int idPos   = request.indexOf("id=") + 3;
      int rId     = request.substring(idPos, idPos + 1).toInt();
      int namePos = request.indexOf("name=") + 5;
      int endPos  = request.indexOf(" ", namePos);
      String nN   = request.substring(namePos, endPos);
      nN.replace("+", " "); nN.replace("%20", " ");
      if (rId >= 1 && rId <= RELAY_COUNT) {
        nN.toCharArray(myConfig.names[rId-1], 26);
        myConfig.configMagic = CONFIG_VERSION;
        EEPROM.put(0, myConfig);
        myNex.writeStr("t" + String(rId + 2) + ".txt", nN);
      }
      webClient.println("HTTP/1.1 303 See Other\r\nLocation: /settings\r\n\r\n");
    }
    else if (request.indexOf("/on") != -1 || request.indexOf("/off") != -1) {
      for (int i = 1; i <= RELAY_COUNT; i++) {
        if (request.indexOf("/" + String(i) + "/on") != -1)  controlRelay(i, HIGH);
        if (request.indexOf("/" + String(i) + "/off") != -1) controlRelay(i, LOW);
      }
      webClient.println("HTTP/1.1 303 See Other\r\nLocation: /\r\n\r\n");
    }
    else { showMainPage(webClient); }
    webClient.stop();
  }
}

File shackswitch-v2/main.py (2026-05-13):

from arduino.app_utils import *
from flask import Flask, jsonify, request, render_template
import threading
import json
import time
import sys

flask_app = Flask(__name__)
flask_app.config["TEMPLATES_AUTO_RELOAD"] = True   # always serve fresh templates
CONFIG_PATH = "/app/python/config.json"

MAX_PORTS   = 16
ALL_BANDS   = ["160m","80m","60m","40m","30m","20m","17m","15m","12m","10m","6m"]
APP_VERSION = "v2.0"
APP_DATE    = "21 Apr 2026"
_START_TIME = time.time()

# Docker bridge gateway — the host OS is reachable at this IP from inside the
# container.  Discovered dynamically so it works on any board regardless of
# which subnet Docker assigns.
def _docker_gateway() -> str:
    import subprocess as _sp
    try:
        r = _sp.run(['ip', 'route', 'show', 'default'],
                    capture_output=True, text=True, timeout=3)
        return r.stdout.split()[2]   # "default via X.X.X.X dev ..."
    except Exception:
        return '172.18.0.1'

_GATEWAY = _docker_gateway()

# ---------------------------------------------------------------------------
# Config I/O
# ---------------------------------------------------------------------------

def load_config():
    with open(CONFIG_PATH) as f:
        return json.load(f)

def save_config(config):
    with open(CONFIG_PATH, "w") as f:
        json.dump(config, f, indent=2)

# ---------------------------------------------------------------------------
# Profile helpers
# ---------------------------------------------------------------------------

def get_profile(config=None):
    """Return the active profile dict. All logical config lives here.
    Falls back gracefully if config is still the legacy flat format."""
    if config is None:
        config = load_config()
    if "profiles" not in config:
        # Legacy flat config — treat the whole dict as the profile
        return config
    name = config.get("active_profile", "home")
    return config["profiles"][name]

def get_port_count(config=None):
    """Active port count — stored in profile, range 2-MAX_PORTS."""
    return int(get_profile(config).get("port_count", 8))

def get_input_count(config=None):
    """Active input count — 1 or 2. Stored in profile."""
    return int(get_profile(config).get("input_count", 1))

def port_exists(config, port):
    return 1 <= port <= get_port_count(config)

# ---------------------------------------------------------------------------
# SmartSDR state helper — replaces the ugly inline __import__ pattern
# ---------------------------------------------------------------------------

def smartsdr_state():
    m = sys.modules.get("smartsdr")
    return m.radio_state if m and hasattr(m, "radio_state") else {}

# ---------------------------------------------------------------------------
# Bridge
# ---------------------------------------------------------------------------

def bridge_call(method, *args):
    return Bridge.call(method, *args)

def _pa_seq(cfg, switch_fn):
    """Standby PA → execute relay switch → 20 ms settle → restore PA.
    Only acts when rfkit_enabled=True and rfkit_ip is set in config."""
    amp_on = cfg.get('rfkit_enabled') and cfg.get('rfkit_ip')
    if amp_on:
        rfkit.rfkit_standby()
    switch_fn()
    if amp_on:
        time.sleep(0.02)
        rfkit.rfkit_operate_mode()

# ---------------------------------------------------------------------------
# Factory reset template
# Illustrative defaults — every capability type shown so builders understand
# the options just by reading the config. Ports 9-16 disabled placeholders.
# ---------------------------------------------------------------------------

_DEFAULT_ANTENNAS = {
    "1":  {"name": "Trapped Vertical — e.g. Hustler 5BV",
           "enabled": True,
           "rx_bands":     ["160m","80m","40m","20m","15m","10m"],
           "tx_bands":     ["40m","20m","15m","10m"],
           "tx_atu_bands": ["160m","80m"]},
    "2":  {"name": "80m Dipole",
           "enabled": True,
           "rx_bands":     ["80m"],
           "tx_bands":     ["80m"],
           "tx_atu_bands": []},
    "3":  {"name": "40m Dipole",
           "enabled": True,
           "rx_bands":     ["40m"],
           "tx_bands":     ["40m"],
           "tx_atu_bands": []},
    "4":  {"name": "20m Yagi",
           "enabled": True,
           "rx_bands":     ["20m"],
           "tx_bands":     ["20m"],
           "tx_atu_bands": []},
    "5":  {"name": "17m Vertical",
           "enabled": True,
           "rx_bands":     ["17m"],
           "tx_bands":     ["17m"],
           "tx_atu_bands": []},
    "6":  {"name": "15m Yagi",
           "enabled": True,
           "rx_bands":     ["15m"],
           "tx_bands":     ["15m"],
           "tx_atu_bands": []},
    "7":  {"name": "10m / 6m Vertical",
           "enabled": True,
           "rx_bands":     ["10m","6m"],
           "tx_bands":     ["10m","6m"],
           "tx_atu_bands": []},
    "8":  {"name": "Beverage RX Only — 160m / 80m",
           "enabled": True,
           "rx_bands":     ["160m","80m"],
           "tx_bands":     [],
           "tx_atu_bands": []},
}
for _i in range(9, MAX_PORTS + 1):
    _DEFAULT_ANTENNAS[str(_i)] = {
        "name": "", "enabled": False,
        "rx_bands": [], "tx_bands": [], "tx_atu_bands": []
    }

_DEFAULT_BAND_MAP = {
    "160m": 1,  "80m": 2,  "60m": None,
    "40m":  3,  "30m": None,
    "20m":  4,  "17m": 5,  "15m": 6,
    "12m":  None,
    "10m":  7,  "6m":  7
}

def fresh_profile():
    """Return a new default profile dict."""
    return {
        "description": "Home station — update with your callsign and location",
        "iaru_region": 1,
        "itu_zone":    28,
        "cq_zone":     14,
        "port_count":  8,
        "input_count": 1,
        "antennas":    {k: dict(v) for k, v in _DEFAULT_ANTENNAS.items()},
        "band_map":    dict(_DEFAULT_BAND_MAP)
    }

# ---------------------------------------------------------------------------
# Routes — index
# ---------------------------------------------------------------------------

@flask_app.route('/')
def index():
    return render_template('index.html')

@flask_app.route('/settings')
def settings():
    return render_template('settings.html')

# ---------------------------------------------------------------------------
# Routes — relay (legacy v1.5 shield compatibility)
# ---------------------------------------------------------------------------

@flask_app.route('/relay/<int:n>/on')
def relay_on(n):
    bridge_call("relay_on", n)
    return jsonify({"relay": n, "state": "on", "ok": True})

@flask_app.route('/relay/<int:n>/off')
def relay_off(n):
    bridge_call("relay_off", n)
    return jsonify({"relay": n, "state": "off", "ok": True})
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

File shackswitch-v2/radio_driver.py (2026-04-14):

"""
radio_driver.py — ShackSwitch radio CAT abstraction layer

Provides:
  - RadioDriver   abstract base class all protocol drivers inherit from
  - SerialTransport / NetworkTransport  reusable connection wrappers
  - Shared band tables covering HF through 23cm (for IC-9700)
  - Shared _setband() callback to ShackSwitch core
"""

import os
import socket
import termios
import time
import urllib.request


# ---------------------------------------------------------------------------
# Band table — HF + VHF/UHF/23cm for IC-9700
# ---------------------------------------------------------------------------

HF_BANDS = [
    (   1_800_000,    2_000_000, '160m'),
    (   3_500_000,    4_000_000, '80m'),
    (   5_300_000,    5_410_000, '60m'),
    (   7_000_000,    7_300_000, '40m'),
    (  10_100_000,   10_150_000, '30m'),
    (  14_000_000,   14_350_000, '20m'),
    (  18_068_000,   18_168_000, '17m'),
    (  21_000_000,   21_450_000, '15m'),
    (  24_890_000,   24_990_000, '12m'),
    (  28_000_000,   29_700_000, '10m'),
    (  50_000_000,   54_000_000, '6m'),
]

VHF_UHF_BANDS = [
    ( 144_000_000,  148_000_000, '2m'),
    ( 430_000_000,  440_000_000, '70cm'),
    (1_240_000_000, 1_300_000_000, '23cm'),
]

ALL_BANDS = HF_BANDS + VHF_UHF_BANDS


def freq_to_band(freq_hz, include_vhf=False):
    table = ALL_BANDS if include_vhf else HF_BANDS
    for lo, hi, name in table:
        if lo <= freq_hz <= hi:
            return name
    return None


def setband(input_n, band):
    """HTTP callback — tell ShackSwitch core to apply band routing."""
    try:
        url = f'http://127.0.0.1:5000/kk1l/setband?input={input_n}&band={band}'
        urllib.request.urlopen(url, timeout=2)
    except Exception:
        pass


# ---------------------------------------------------------------------------
# Transports
# ---------------------------------------------------------------------------

_BAUD_MAP = {
    4800:   termios.B4800,
    9600:   termios.B9600,
    19200:  termios.B19200,
    38400:  termios.B38400,
    57600:  termios.B57600,
    115200: termios.B115200,
}


class SerialTransport:
    """RS-232/USB-serial connection using stdlib termios only (no pyserial)."""

    def __init__(self, device, baud):
        self.device = device
        self.baud = int(baud)
        self._fd = None

    def connect(self):
        fd = os.open(self.device, os.O_RDWR | os.O_NOCTTY)
        attrs = termios.tcgetattr(fd)
        attrs[0] = 0                                              # iflag — raw
        attrs[1] = 0                                              # oflag
        attrs[2] = termios.CS8 | termios.CREAD | termios.CLOCAL  # cflag 8N1
        attrs[3] = 0                                              # lflag
        brate = _BAUD_MAP.get(self.baud, termios.B9600)
        attrs[4] = brate
        attrs[5] = brate
        attrs[6][termios.VMIN]  = 0
        attrs[6][termios.VTIME] = 20   # 2 s read timeout (tenths of seconds)
        termios.tcsetattr(fd, termios.TCSANOW, attrs)
        self._fd = fd

    def send(self, data: bytes):
        os.write(self._fd, data)

    def recv(self, n=256, delay=0.15) -> bytes:
        time.sleep(delay)
        return os.read(self._fd, n)

    def close(self):
        if self._fd is not None:
            try:
                os.close(self._fd)
            except OSError:
                pass
            self._fd = None

    @property
    def description(self):
        return f'{self.device}, {self.baud} baud'


class NetworkTransport:
    """TCP socket connection (Kenwood KNS, Icom CI-V over network, etc.)."""

    def __init__(self, host, port, connect_timeout=5, recv_timeout=3):
        self.host = host
        self.port = int(port)
        self._connect_timeout = connect_timeout
        self._recv_timeout = recv_timeout
        self._sock = None

    def connect(self):
        s = socket.socket(socket.AF_INET, socket.SOCK_STREAM)
        s.settimeout(self._connect_timeout)
        s.connect((self.host, self.port))
        s.settimeout(self._recv_timeout)
        self._sock = s

    def send(self, data: bytes):
        self._sock.sendall(data)

    def recv(self, n=256, terminator=None, timeout=3.0) -> bytes:
        """Read up to n bytes. If terminator byte/bytes given, read until seen."""
        raw = b''
        deadline = time.time() + timeout
        while time.time() < deadline:
            try:
                chunk = self._sock.recv(n)
                if not chunk:
                    raise ConnectionError('Connection closed by remote')
                raw += chunk
                if terminator and terminator in raw:
                    break
                if not terminator and len(raw) >= n:
                    break
            except socket.timeout:
                break
        return raw

    def close(self):
        if self._sock is not None:
            try:
                self._sock.close()
            except OSError:
                pass
            self._sock = None

    @property
    def description(self):
        return f'{self.host}:{self.port}'


# ---------------------------------------------------------------------------
# RadioDriver — abstract base
# ---------------------------------------------------------------------------
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

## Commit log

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2026-03-19 Add G0JKN Antenna Switcher firmware 1.4
    This file contains the implementation of the G0JKN Antenna Switcher, including features like state synchronization, a background WiFi manager, and a factory reset. It also supports dual-state image buttons and manages relay configurations.
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2026-03-27 Add files via upload
    the newer v 1.5 with comms to flex radio for ant switching
    [shackswitch_20260327013849.ino]
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2026-04-02 Enhance bridge_call with retries and add Flask routes
    Added error handling and retry logic to bridge_call function. Implemented various Flask routes for relay control, status retrieval, and configuration management.
    [main.py]
2026-04-02 Refactor bridge_call and clean up main.py
    Refactor bridge_call function to simplify error handling and remove unnecessary retries. Clean up code by removing unused routes and imports.
    [main.py]
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2026-04-02 Sync shackswitch-v2 from live first-app — KK1L MCP23017 working, Wire1 fix
    [sketch.ino]
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2026-04-05 Session 04 Apr 2026 — SmartSDR fixed, dual MCP23017 support
    smartsdr.py:
    - Fixed subscription bug: subscribe after 1s delay, not on interlock line
    - Fixed endpoint: call /kk1l/setband not /setband (UI reads input1_port)
    - Fixed input mapping: inp = sidx+1 (was broken binary 0/not-0 mapping)
    - Added reconnection loop and frequency= fallback parsing
    sketch.ino:
    - Added MCP23017 #2 at 0x22 (A1 bridged to VCC)
    - RLYT relays → MCP1 GPA (0x20), RLYB relays → MCP2 GPA (0x22)
    - Both boards detected and confirmed online
    CLAUDE-UNO-Q.md:
    - Full rewrite with clean formatting
    - Updated hardware section — dual MCP boards documented
    - Updated architecture, gotchas, known bugs, roadmap
    - Session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
    [sketch.ino, smartsdr.py]
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2026-04-06 Add voice transcript debug display
    Shows last recognised phrase below the antenna matrix when Voice is ON.
    Also shows recognition errors. Helps confirm correct mic is being used.
2026-04-06 Suppress no-speech as error in voice transcript display
    no-speech is normal timeout behaviour — show Listening... instead of Error.
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2026-04-06 Fix speech recognition abort loop — add 300ms restart delay
    Immediate restart on onend caused start→abort→end tight loop.
    300ms delay gives Chrome time to fully release the session.
2026-04-06 v2.0: voice control, live freq display, custom commands (5-6 Apr 2026)
    - Web Speech TTS + STT (Phase 1+2) live on 10.0.0.145:5000 and localhost tunnel
    - Voice Settings page with built-in command reference and custom command manager
    - Live FlexRadio VFO frequency in status cards via smartsdr.radio_state
    - /radio/status endpoint; /status extended with bandA/freqA/bandB/freqB
    - Fix: 350ms TTS-to-mic delay resolves error:aborted race condition
    - Fix: sys.modules.get() replaces __import__() to avoid import lock deadlock
    - CLAUDE-UNO-Q.md and CHANGELOG.md updated
    [main.py, smartsdr.py]
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2026-04-12 12 Apr 2026 — kenwood.py: replace pyserial with stdlib termios (no pip)
    [kenwood.py]
2026-04-12 12 Apr 2026 — Giga R1 dummy 890 sketch (touchscreen), fix IF; mode position
    [giga_dummy_890.ino, r4_dummy_890.ino]
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2026-04-15 Add Radio Sources settings page with network scan and conflict detection
    - Settings page: new Radio Sources section shows Input 1/2 assignment,
    CAT radio pool with enable/disable/edit/delete, and Scan Network button
    - /radios/status: combined SmartSDR slices + CAT radios with conflict detection
    - /radios/scan: parallel subnet scanner for Flex (4992), Kenwood (60000), Icom (50001)
    - /radios/config PUT/DELETE: per-radio add/update/remove endpoints
    - radios.py: fix last_band reset-on-reconnect bug (move to module-level dict)
    - kenwood.py: same last_band fix; radio B disabled by default
    [kenwood.py, main.py, radios.py]
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2026-04-16 Recover rfkit.py and live index.html — were never committed to git
    rfkit.py: RF-Kit RF2K-S integration (get_status, set_operate_mode,
    reset_fault, set_antenna). Was only on device since 3 Apr 2026.
    index.html: 381-line diff vs repo — live version had significant
    updates deployed directly to device on 15 Apr 2026.
    [rfkit.py]
2026-04-16 Fix conflict detection: SmartSDR only claims input when actually connected
    SmartSDR sources were always enabled:True, permanently blocking CAT radios
    from being assigned to input 1/2 even when no Flex was connected.
    [main.py]
2026-04-16 Fix status endpoint: fall back to CAT radio band/freq when SmartSDR not connected
    /status was reading bandA/freqA/bandB/freqB from SmartSDR only.
    Now falls back to active CAT radio state per input when SDR has no data.
    [main.py]
2026-04-16 Add Icom CI-V port 50002 to scan; fix IC-9700 network support comment
    IC-9700 port 50002 (Serial) provides raw CI-V over TCP — compatible with
    existing NetworkTransport. Enable via MENU > SET > WLAN/LAN on radio.
    [main.py, radio_icom.py]
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2026-04-16 Fix USBHostSerial API — use buffer-based Mbed Stream read/write, drop begin()
    [giga_dummy_890.ino]
2026-04-17 Fix conflict detection: SmartSDR + CAT on same input is not a conflict
    CAT radios act as fallback when SmartSDR is not connected. Two CAT
    radios on the same input still flags correctly. Direct-input radios
    are excluded from conflict detection entirely.
    [main.py]
2026-04-18 Add Nextion display driver, input_count setting, and direct relay path
    - nextion.py: new driver for NX8048P070 via STM32 bridge (D0/D1 serial)
    - Parses printh 23 02 54 NN touch events from HMI buttons
    - Pushes antenna labels from /bandmap on startup (fixes Port 1-4 placeholder)
    - UTC clock in HH:MMz format, updated every 60s
    - Bidirectional: web and Nextion stay in sync on port changes
    - main.py: input_count setting (1=single radio, 2=SO2R)
    - 1-input mode uses direct relay pins D2-D5 (no MCP23017 needed)
    - 2-input mode uses KK1L MCP23017 matrix
    - POST /config/inputs endpoint; enforced in kk1l_select and kk1l_setband
    - /select (legacy) now calls nextion.on_port_selected() for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
    [main.py, nextion.py, sketch.ino]
2026-04-18 WiFi page 8 flow, input_count feature, Nextion sync fixes
    - input_count (1 or 2) selects direct relay path vs MCP23017 matrix
    - POST /config/inputs endpoint; web UI Settings selector
    - kk1l_select/setband route through relay_on/off for 1-input mode
    - nextion.py: startup fetches /bandmap for real antenna names, UTC clock push
    - Nextion WiFi page: SCAN via host HTTP service (172.21.0.1:5555), CONNECT
    - wifi_scan_svc.py: host-side nmcli wrapper, adds /connect endpoint
    - sketch.ino: nextion_get_str + nextion_get_num bridge functions
    - Fix: PAGE_WIFI=8, all printh events handled in PAGE_MAIN block (page always 0)
    - Fix: /select (legacy) now calls nextion.on_port_selected()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
    [main.py, nextion.py, sketch.ino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]
2026-04-18 Add factory reset endpoint and page8 back/reset button handlers
    - POST /config/reset clears all user config (labels, radios, Kenwood,
    RF-Kit IP, band_map) and restores fresh_profile() defaults, then
    restarts the app after 3s
    - nextion.py: COMP_WIFI_RESET (0x23) calls factory reset via Flask
    - nextion.py: COMP_WIFI_BACK (0xFF) sends page page0 (backup if printh added)
    - bBackt on page8 handled directly in HMI with page page0 (no printh needed)
    [main.py, nextion.py]
2026-04-18 Require double-press to confirm factory reset
    First press shows 'Press RESET again!' on tStatus.
    Second press within 10s executes the reset.
    Accidental single tap does nothing destructive.
    [nextion.py]
2026-04-20 Add AetherSDR AG protocol emulation, settings page, and deploy script
    main.py:
    - AG UDP broadcaster: fixed to use stable device identity (serial=G0JKN-SW,
    name=ShackSwitch) so AetherSDR can reliably identify and route to the
    ShackSwitch applet rather than the generic Antenna Genius panel
    - AG TCP server: handles AetherSDR connection and antenna select commands
    templates/index.html:
    - Full restyle to match AetherSDR dark theme (CSS variables: --bg #09101f,
    --cyan #00d8ef, --orange #f97316 etc.)
    - Nav restyled as tab bar; Settings nav button now correctly reaches /settings
    - Topbar replaces h1/h3 headers
    templates/settings.html:
    - New settings page (IP config, port labels, voice settin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
    [main.py]
2026-04-20 AG live push, settings fixes, Nextion SO2R, KK1L ports 7-8, exclusive relay select
    - AG TCP server pushes S0|port N status to AetherSDR on every relay/band change
    - HTTP health checks from 172.21.0.1 no longer register as AG clients
    - Fixed 4 settings routes (bandmap, label, rename/bulk, profile/set) to accept POST
    - Nextion navigates to correct page (page2 for 8-port SO2R) on startup
    - on_band_set now passes input_n so Input B band changes update bB buttons
    - _push_buttons updates bB buttons even if _input_count not yet loaded (startup race)
    - KK1L_PORTS increased to 8 — ports 7 and 8 now actuate relays
    - kk1l_select_a/b now use assignment (=) not OR (|=) — exclusive relay select,
    imp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
    [main.py, nextion.py, sketch.ino]
2026-04-21 Add MCP23017 hardware detection to settings UI
    - sketch: add mcp_status() bridge function returning detected I2C
    addresses ("none", "0x20", or "0x20,0x21")
    - main.py: expose mcp_boards in /status; graceful fallback to "none"
    if sketch not yet reflashed; fix kk1l_available to reflect hardware
    detection rather than current input_count (breaks circular lock)
    - settings.html: show MCP status line under Number of Inputs buttons —
    orange warning when no MCP detected, cyan confirmation with addresses
    when found; SO2R button disabled when no MCP hardware present
    [main.py, sketch.ino]
2026-04-21 Fix /profile missing antennas/band_map/input_count; pigeonhole band map; settings UI fixes
    - /profile endpoint now returns antennas, band_map, input_count, input labels
    (was silently omitting them, leaving Settings PORTS/ANT MAP tabs blank)
    - ANT MAP tab replaced with click-to-assign pigeonhole matrix grid (auto-saves on click)
    - setInputCount() re-fetches /status after save so MCP detected status stays correct
    - app.yaml: added port 9007 to Docker port mappings (AG emulator was unreachable)
    - Deployment note: always restart app after template changes to flush Jinja2 cache
    [main.py]
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2026-04-25 Add skip-splash support (0x30) and _navigate_to_main() helper
    COMP_SKIP (0x30) from splash bNext triggers _navigate_to_main() which
    picks page0/page1/page2 based on input_count and port_count — same
    logic as _push_startup_state(). Uno Q goes to page2 (SO2R), single-
    input goes to page0, 6-port goes to page1.
    [nextion.py]
2026-04-25 Fix Nextion button latching: optimistic update from poll thread
    - bA/bB touch events now update _active_port/_active_port_b and call
    _push_buttons() immediately from the poll thread, avoiding Flask-thread
    bridge conflicts that were silently dropping the bco commands
    - API call to /kk1l/select fired in background thread (non-blocking)
    - Toggle logic: tapping active port deselects it (sets to None)
    - bB buttons now use COL_ACTIVE_B (orange) instead of green to
    visually distinguish Input A (green) from Input B (orange)
    [nextion.py]
2026-04-25 Fix button state display: use pic/pic2 not bco (sta=image buttons)
    bA/bB buttons use sta=image so bco is ignored at runtime. Switch to
    pic/pic2 to latch state — same approach as R4 sketch.
    bA inactive: pic=23/pic2=23 bA active: pic=24/pic2=24
    bB inactive: pic=25/pic2=25 bB active: pic=26/pic2=26
    [nextion.py]
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2026-04-29 Add dual FlexRadio SmartSDR support and fix CAT radio UI
    smartsdr.py: refactored to support multiple radios from config.json
    (smartsdr_radios array). Each radio runs in its own thread and maps to
    a fixed input. Added reload() so enable/disable takes effect live
    without a container restart.
    main.py: new PUT /config/smartsdr_radio endpoint (enable/disable a
    Flex radio by IP, triggers smartsdr.reload()). radios_status() now
    reads SmartSDR radios from config rather than hardcoded slice loop.
    settings.html RADIOS page:
    - New FlexRadio/SmartSDR card lists configured Flex radios with
    live enable/disable toggle (no restart required)
    - CAT radio list fixed: now shows label, protocol, and device p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
    [main.py, smartsdr.py]
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2026-04-30 Nextion: fix Serial1 port mapping and auto-navigation
    - sketch.ino: all Nextion serial calls switched from Serial to Serial1.
    On Uno Q Zephyr, Serial = internal SoC/STM32 link (arduino-router);
    Serial1 = D0/D1 header pins (physical Nextion connection). This was
    why every Python->Nextion command was silently dropped while touch
    events appeared to work (HMI handled its own page navigation directly).
    - nextion.py: page navigation now uses numeric index (page 1 / page 2)
    rather than page name, with doubled send + confirmation prints for
    reliability.
    - nextion.py: _push_startup_state builds full label/port state before
    calling _navigate_to_main() so page populates immediately on a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
    [nextion.py, sketch.ino]
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2026-05-01 fix: _navigate_to_main must not route to SO2R page based on port count
    port_count > 4 incorrectly sent single-radio users to the unfinished
    SO2R page (page 2). Page selection must depend only on input_count:
    single-radio always goes to page 1 regardless of how many ports are
    configured.
    [nextion.py]
2026-05-01 fix: correct Nextion IP display and immediate re-navigation on mode change
    - nextion.py _local_ip(): query host-side wifi_scan_svc /ip endpoint instead
    of hostname -I which returns only 172.x bridge addresses inside Docker;
    fall back to hostname -I for non-Docker dev environments
    - wifi_scan_svc.py: add /ip endpoint returning the host's real WiFi IP
    (filters 172.x and 127.x) so the Docker container can discover it
    - main.py /config/inputs: after saving input_count, notify Nextion driver
    and re-navigate immediately so display switches page without restart
    [main.py, nextion.py, wifi_scan_svc.py]
2026-05-01 fix: discover Docker bridge gateway dynamically instead of hardcoding IP
    172.21.0.1 was wrong on this board (actual gateway is 172.18.0.1).
    Replace all hardcoded gateway IPs in nextion.py and main.py with a
    _GATEWAY constant derived from `ip route show default` at startup so
    the wifi_scan_svc on port 5555 is reachable from any board regardless
    of which subnet Docker assigns to the App Lab network.
    [main.py, nextion.py]
2026-05-01 fix: run WiFi scan/connect in background threads to unblock event loop
    Calling _wifi_scan_and_push() and _wifi_connect() directly in the event
    poll loop blocked it for up to 25s (nmcli --rescan yes is slow), causing
    missed button presses. Now run both in daemon threads, matching how port
    selection already works. Add _scan_in_progress guard to prevent multiple
    concurrent scans from rapid button presses.
    [nextion.py]
2026-05-01 fix: remove --rescan yes from wifi scan to avoid 10-20s block
    Use cached NM results (returned instantly) and fire a background rescan
    in parallel. When disconnected NM scans continuously anyway so results
    are already fresh. --rescan yes was causing the scan button to appear
    unresponsive for up to 20 seconds.
    [wifi_scan_svc.py]
2026-05-01 fix: add connect guard and extend connect timeout to 30s
    _wifi_connect() was firing multiple concurrent threads with no guard,
    and the urllib timeout of 2s was far too short for nmcli to complete a
    WiFi connection (takes 20-30s). Add _connect_in_progress guard matching
    the scan guard pattern, extend timeout to 30s, and log errors properly.
    [nextion.py]
2026-05-01 fix: halve event poll interval and add instant button acknowledgement
    Reduce _event_poll_loop sleep from 150ms to 75ms so button presses are
    caught faster. Add immediate tStatus feedback on SCAN/CONNECT press so
    the user sees a response on first press and stops pressing repeatedly.
    [nextion.py]
2026-05-01 fix: navigate to WiFi page on startup if board has no WiFi IP
    When booting without WiFi credentials, the 20s startup push was
    navigating away from the WiFi setup page back to the main page.
    Now checks _local_ip() first — if no non-Docker IP is found, send
    'page 8' and return immediately so the user stays on WiFi setup.
    Normal startup proceeds as before when WiFi is connected.
    [nextion.py]
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2026-05-01 refactor: simplify Nextion to display-only — remove WiFi page handling
    Nextion is now a read-only status display. All configuration is done
    via the web UI at http://[ip]:5000.
    Removed:
    - PAGE_WIFI, COMP_WIFI_SCAN/CONNECT/BACK/RESET, WIFI_SCAN_SVC constants
    - WiFi IP startup check that navigated to page 8
    - _wifi_scan_and_push(), _wifi_connect(), _factory_reset() functions
    - _scan_in_progress, _connect_in_progress, _reset_confirm_time guards
    - update_wifi_ssids(), update_wifi_status() methods
    - COMP_WIFI touch handler (page8 navigation)
    Kept:
    - _local_ip() / _GATEWAY for IP display on screen
    - Startup now shows 'No WiFi — use USB' if no network IP found
    - All antenna selection, band dis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
    [nextion.py]
2026-05-01 fix: use nmcli connection add+up for WPA2 to avoid key-mgmt error
    nmcli device wifi connect cannot set wifi-sec.key-mgmt on a new
    profile, causing '802-11-wireless-security.key-mgmt: property is
    missing' on clean boards with no existing connection profile.
    New approach for password-protected networks:
    1. Delete any stale nmcli profile for the SSID
    2. nmcli connection add with explicit wpa-psk + key-mgmt
    3. nmcli connection up to activate
    Open networks (no password) still use device wifi connect directly.
    [wifi_scan_svc.py]
2026-05-01 fix: page 2 button highlighting and interlock revert
    Page 2 (SO2R) uses bt0-bt7 (Input A) and bt8-bt15 (Input B) not
    the t-component vis approach assumed by old code.
    - _push_buttons: colour bt{n-1} for A, bt{n+7} for B using bco;
    also retain vis t{n+7}/t{n-1} for narrow middle column indicators
    - _update_button_a/b: same dual-page update on fast single-change path
    - _select_port: now reads server response; calls _sync_port_state()
    to revert Nextion display if server rejects (interlock 409 etc.)
    - _sync_port_state: new method — re-fetches /status and redraws buttons
    [nextion.py]
2026-05-01 fix: page 2 three-state narrow column indicators
    t8-t15 = Input A (cyan) indicators, t0-t7 = Input B (orange) indicators.
    Both hidden = background picture shows (idle). _push_buttons() now sends
    vis commands for all three states on every redraw, matching the HMI design
    where the narrow column shows A, B, or nothing per antenna row.
    [nextion.py]
2026-05-01 fix: page 2 bt buttons use val not bco — dual-state image type
    bt0-bt15 are dual-state image buttons (sta=image, pic2=30).
    bco has no effect on image-type buttons. val=1 shows pic2 (highlighted),
    val=0 shows pic (empty → background). Nextion auto-toggles val on touch
    but only for the pressed button — Python must send val=0 to deselect the
    previously active button, which the fast update methods now do correctly.
    [nextion.py]
2026-05-01 feat: auto-detect input_count from MCP23017 hardware on boot
    Both 0x20 + 0x21 present → input_count=2 (SO2R, page 2).
    One board or none → input_count=1 (single radio, page 1).
    Runs in setup() after the 15s bridge warm-up, before the Nextion
    driver reads /status at 20s. Disconnecting MCP boards on reboot
    now automatically reverts the display to single-radio mode without
    manual config changes.
    [main.py]
2026-05-01 fix: run setup() in daemon thread so App.run() starts before bridge_call
    setup() was blocking the main thread before App.run(), meaning Bridge.call()
    had no runtime to service it and hung forever — neither the MCP auto-detect
    print nor Nextion startup messages ever appeared in logs.
    [main.py]
2026-05-01 fix: timeout bridge_call in setup() — mcp_status not yet in firmware
    Bridge.call() hangs indefinitely if the STM32 firmware doesn't recognise
    the method. Wrap in a daemon sub-thread and bail after 8 s with a clear
    log message so the rest of the boot sequence is never blocked.
    [main.py]
2026-05-01 fix: correct mcp_status timeout message — firmware does support it
    The earlier message said "firmware not yet implemented" but the real
    cause was setup() calling bridge_call before App.run() had started.
    Now that setup() runs in a daemon thread the call works; timeout is
    kept as a safety net for slow or missing coprocessor responses.
    [main.py]
2026-05-01 feat: auto-set port_count=8 when SO2R hardware first detected
    On the 1→2 input_count transition (both MCP23017s found at boot),
    default port_count to 8 so all relay ports appear on the Nextion
    immediately. Operator can reduce this in Settings; manual changes
    survive subsequent reboots since we only set it on the 1→2 transition.
    [main.py]
2026-05-01 fix: push labels to active page only — avoid overwriting page 2 indicators
    _push_labels() was sending both page 1 (t3-t10) and page 2 (t16-t23)
    label commands unconditionally. On page 2, t3-t10 are the narrow-column
    A/B indicator components, so antenna names were appearing twice — once
    on the correct label and once on an indicator component.
    Now only the label set for the current page (based on input_count) is sent.
    [nextion.py]
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2026-05-02 fix: treat empty smartsdr_radios list same as missing key
    cfg.get('smartsdr_radios', default) returns [] when the key exists but
    is empty, hiding the Flex radio from the settings UI. Use 'or default'
    so both missing and empty fall back to the built-in default entry.
    [main.py]
2026-05-02 fix: smartsdr_radio_update initialises from default when list is empty
    When smartsdr_radios was [] the toggle endpoint looped over nothing,
    found no entry to update, and saved [] back — permanently wiping the
    Flex radio from the UI. Now falls back to the default list (same as
    radios_status) before applying the enable/disable toggle.
    [main.py]
2026-05-02 KPA-1500: bar-meter UI, threading fix, antenna support
    - index.html: replace KPA-1500 tab with KPA1500 Remote-style bar meters
    (Power, Reflected, SWR, Current, Voltage, Temp, Fan), large AMP ON /
    STANDBY / FAULT status banner, Ant 1 / Ant 2 buttons, Clear Fault
    - kpa1500.py: add _cmd_lock to serialise socket access between poll thread
    and Flask request threads (fixes fwd_power always reading 0); add
    set_antenna() and poll ^AN; to expose antenna selection
    - main.py: add PUT /kpa/antenna route; add kpa1500/acom600s drivers
    [acom600s.py, kpa1500.py, main.py]
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2026-05-02 Acom 600S: fix TCP mode blocked by pyserial availability check
    start() only gates on _SERIAL_AVAILABLE for serial mode; TCP works without pyserial.
    [acom600s.py]
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2026-05-09 icom: fix IC-9700 default CI-V address (0xA2 not 0x98)
    Verified live against IC-9700 on the bench: auto-discovery returned
    0xA2, driver subsequently read freq 146.985 MHz on 2m correctly.
    The default only affects callers that construct IcomCIVDriver() with
    no civ_address — radios.py always passes None for auto-discovery, so
    this is mainly a docstring correctness fix.
    [radio_icom.py]
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

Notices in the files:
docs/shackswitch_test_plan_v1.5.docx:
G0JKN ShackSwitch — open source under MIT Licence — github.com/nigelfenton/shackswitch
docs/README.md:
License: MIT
